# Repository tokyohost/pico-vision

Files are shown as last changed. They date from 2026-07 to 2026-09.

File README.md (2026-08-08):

# Pico RP2040 系统监控屏

项目包含电脑端数据采集程序和 Pico RP2040 显示程序，实现两个独立功能：

1. 按开发板型号非阻塞控制 WS2812 多色灯或 GPIO 单色状态灯。
2. 通过 USB CDC 或 Wi-Fi WebSocket 增量接收 JSON，并将 ST7789 LCD 按条带异步刷新。

## 设计约束

- 不使用 RP2040 第二核心，规避 MicroPython 线程、USB 和 SPI 之间的互锁风险。
- 内置 USB CDC 仅用于 REPL；PV1 通信使用独立 USB CDC 及非阻塞批量 FIFO。
- LCD 不申请 240×320 的整帧缓冲，仅使用 240×48×2，即 23,040 字节条带缓冲。
- LED、串口接收和 LCD 刷新均由单核协作式主循环调度。
- JSON 最大长度为 16 KiB，超限数据包会被拒绝。

## Pico 端文件

将 `picoRP2040/` 的完整目录结构复制到 Pico 根目录：

- `main.py`：应用入口和协作式主循环。
- `led/`：不同板载状态灯的非阻塞控制策略与控制器工厂。
- `protocol.py`：PV1 握手及 JSON 增量接收状态机。
- `net/`：USB CDC、Wi-Fi、WebSocket 传输策略及首连接锁定选择器。
- `usb_transport.py`：创建与 REPL 隔离的 USB CDC 数据通道。
- `usb/device/`：上游 MicroPython `usb-device` 和 `usb-device-cdc` MIT 实现。
- `upgrade_manager.py`：串口升级会话、临时写入、SHA-256 校验、安装和自动重启。
- `data_receiver.py`：最新 JSON 快照缓存。
- `lcd.py`：ST7789 初始化和区域写屏。
- `canvas.py`：带条带裁剪的 RGB565 绘图。
- `dashboard.py`：仪表盘布局和分段刷新。
- `config.py`：开发板、屏幕方案、周期和协议配置。
- `color_manager.py`：按屏幕型号管理反色模式和 RGB/BGR 颜色顺序。
- `board_manager.py`：注册开发板硬件档案并隔离不同板载 LED 类型。
- `fonts/`：SDK 内置文泉驿点阵正黑和 Fusion Pixel 双语字模的授权说明。

Pico 握手会向 Monitor 返回当前开发板型号、屏幕色彩方案、运行固件版本和 `net` 状态；ESP32-S3 还会返回由 eFuse MAC 经 SHA-256 派生的稳定 `device_id`，设备管理页面以 UUID 形式展示且不暴露原始 MAC。USB 模式返回 `mode=usb`，Wi-Fi 模式还返回 SSID、IP、网关、RSSI、WebSocket 端口与路径。源码
直接部署时版本为 `development`，发布全量固件包会自动写入对应的发布版本。

开发板型号和 Wi-Fi 开关由 `picoRP2040/config.py` 配置。例如 ESP32-S3 开启 Wi-Fi：

```python
BOARD_MODEL = "ESP32-S3"
WIFI_ENABLED = True
```

ESP32-S3 与 RP2040 都遵循样式声明的默认字体，例如现有紧凑样式使用
`font_name = "screen_2inch_compact"`。需要显示中文时，可通过 `canvas.text()` 的
`font_name` 参数为单次文字绘制选择字体；调用结束后会恢复样式默认字体。

项目配套的 RP2040 与 ESP32-S3 固件还可选择 `wqy_8x16` 或
`fusion_pixel_8x16`。两者均为英文半角 8×16、中文全角 16×16，直接由 `fn_canvas`
从固件只读区绘制。`canvas.text()` 和 `canvas.text_width()` 都接受 `font_name`；不传入
时保持当前样式字体，样式未指定时仍默认 `native`。

仅使用 USB CDC 时把 `WIFI_ENABLED` 设为 `False`，固件不会初始化无线网卡或 WebSocket 服务。支持的板型包括：

- `rp2040_usb`：GP22 上的 WS2812 多色状态灯。
- `rp2040_typec`：GP25 控制的单色状态灯。
- `ESP32-S3`：默认使用 GPIO48 上的板载 WS2812；具体开发板引脚不同时可修改 `board_manager.py` 中的档案。

新增型号时，可创建 `BoardProfile` 并通过 `register_board_profile()` 注册；业务层
无需感知 LED 的具体实现。

USB 能力同样按照 `BOARD_MODEL` 自动选择，不需要额外 USB 开关：

- `rp2040_usb`、`rp2040_typec` 使用 `machine.USBDevice` 注册保留 REPL 的独立数据 CDC。
- `ESP32-S3` 使用固件内置 USB CDC 或 USB 串行控制台，通过 `sys.stdin` 与
  `sys.stdout` 承载 PV1，不导入也不调用 ESP32 不支持的 `machine.USBDevice`。

ESP32-S3 内置控制台在收到 Monitor 首个字节后锁定 USB 会话；长期无通信后释放，
使启用 Wi-Fi 时 WebSocket 仍可参与传输竞选。

RP2040 端需要 MicroPython 1.23 或更新版本。启动后 USB 会重新枚举为
两个串口：一个保留给 REPL，另一个由 Monitor 通过 PV1 PING 自动识别。
首次部署后原串口短暂断开属于正常现象。Debian 下建议将
`PICO_MONITOR_PORT` 留空，不要固定 `/dev/ttyACM0`。

屏幕硬件由 `picoRP2040/config.py` 中的 `LCD_DEVICE_TYPE` 选择。编码由
芯片、尺寸、排针数量和批次组成，最终由 `lcd` 目录中对应的 `LcdDevice` 子类完整
定义脚位、分辨率、色彩、偏移和写屏细节。工厂会自动扫描该目录中公开
`LCD_DEVICE_CLASS` 的模块，无需维护集中式型号表：

- `st7789-2inch-8pin-a`：ST7789VW 二英寸八针 SPI A 款屏幕。
- `st7789-2.4inch-10pin-a`：ST7789 二点四英寸十针 SPI A 款屏幕。
- `st7789-2.4inch-8pin-b`：ST7789 二点四英寸八针 SPI B 款屏幕。

两种八针屏会按照 `BOARD_MODEL` 自动选择 GPIO。RP2040 保持原有
`SCK=GP6、MOSI=GP7、CS=GP8、DC=GP14、RST=GP15、BL=GP26`；ESP32-S3 使用
`SPI(2)、SCK=GPIO12、MOSI=GPIO11、CS=GPIO10、DC=GPIO9、RST=GPIO14、BL=GPIO13`。
ESP32-S3 默认以 10 MHz 驱动屏幕，并将不接屏幕的 MISO 显式分配到 GPIO15，避免
旧版 MicroPython 自动使用 GPIO13 而与背光 PWM 冲突。
完整接线见 `doc/ST7789_WIRING_README.md`。十针屏目前仅支持 RP2040，ESP32-S3
选择该方案时会返回明确错误，防止误用 RP2040 脚位。

屏幕色彩方案由所选屏幕档案确定，并在握手时提供给 Monitor：

- `st7789vw_2inch`：旧款 ST7789VW 二英寸屏，开启反色并使用 RGB 顺序。
- `st7789_2_4inch`：二点四英寸八针屏，关闭反色并使用 RGB 顺序。
- `st7789_2_4inch_10pin_a`：二点四英寸十针 A 款屏，开启反色并使用 RGB 顺序。
- `st7789_2_4inch_bgr`：新款屏的 BGR 变体；仅在红色与蓝色互换时使用。

旧配置名 `st7789_2inch` 仍可使用，并会自动映射到 `st7789vw_2inch`。

GitHub Actions 会按照全部开发板型号与规范 LCD 设备类型的笛卡尔积生成全量固件包，
文件名格式为 `OmniWatch-pico-full-v<版本>-<开发板型号>-<LCD设备类型>.zip`。包内直接保存
完整部署目录，不再包含 upgrade 清单。Windows Monitor 解压后通过 mpremote 比较设备端文件的
大小和 SHA-256，只复制缺失或内容不一致的文件。无型号后缀的兼容包固定对应
`rp2040_usb` 与 `st7789-2inch-8pin-a`，其他硬件不可混用该兼容包。

## 通信协议

PV1 帧可承载在 USB CDC 字节流或 WebSocket 二进制消息中。USB 和 WebSocket 同时可用时，设备始终优先锁定 USB。WebSocket 默认监听 `ws://设备IP:8765/pv1`，Monitor 握手会携带稳定客户端标识和本机设备名称；ESP32-S3 在 `websocket_clients.json` 中记录成功连接次数、最近地址、启用状态和优先级。设备管理页面可打开“WebSocket 客户端”查看、禁用或设置 `-1000` 至 `1000` 的优先级；仅严格更高优先级的新客户端能够抢占当前 WebSocket，会话切换时会清空旧缓冲，始终只允许一个客户端同步 JSON。

启用 JSON 发送间隔自适应后，Monitor 在每次建立发送会话时从 `400ms` 快速档开始协商；单次启动慢 ACK 不会立即降速，连续慢 ACK 才上调周期，ACK 超时则按两倍周期指数退避，恢复后立即采用更快周期。发送过程继续保持一条在途 JSON 的背压约束。最低采集与发送间隔为 `300ms`；固定间隔模式也不接受更低配置。

设备提供三个配网命令：`wifi.list` 每次返回按信号强度排序的附近全部网络，并在失败中的自动重连与扫描冲突时恢复无线状态后重试；`wifi.set` 的 `params` 接受 `ssid`、`password` 和可选 `timeout_ms`；`wifi.forget` 的 `params` 接受已保存的 `ssid`，用于删除设备凭据。命令均通过 `COMMAND` 帧返回成功详情或失败原因。Wi-Fi 凭据仅保存在设备端 `wifi_config.json`，PONG 和日志不会返回密码。

数据包采用纯 ASCII 行协议，避免 MicroPython 将二进制 `0x03` 解释为 Ctrl+C：

```text
JSON: + 单行 UTF-8 JSON + 换行符
```

设备发现命令为 `PING:PICO_LCD?\n`，有效 JSON 接收完成后返回 `ACK:JSON\n`。

## 启动方式

```powershell
python -m pip install -r requirements.txt
python send_frame.py
```

固定串口时可增加 `--port COM3` 参数。

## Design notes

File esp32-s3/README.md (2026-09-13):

# ESP32-S3 设备端代码

本目录是从 `picoRP2040` 独立出来的 ESP32-S3 专用实现，不包含 RP2040 硬件档案、Pico USB Device 驱动或跨开发板选择逻辑。

## 固定硬件配置

- 开发板：ESP32-S3
- 状态灯：GPIO48 板载 WS2812，单灯珠
- LCD 总线：SPI2，SCK GPIO12，MOSI GPIO11，保留 MISO GPIO15
- LCD 控制：CS GPIO10，DC/RS GPIO9，RST/RESET GPIO14，背光 PWM GPIO13
- 默认 LCD：ST7789 2.4 英寸十针 SPI A 款，排针顺序为 GND、RS、CS、SCL、SDA、RESET、VDD、GND、LED+、LED-
- 十针信号：RS 接 GPIO9，CS 接 GPIO10，SCL 接 GPIO12，SDA 接 GPIO11，RESET 接 GPIO14
- 十针背光：LED+ 接受限电源，LED- 通过外部低端 MOSFET 调光，GPIO13 只驱动 MOSFET 栅极
- 按键：GPIO1、GPIO2、GPIO3，低电平有效并启用内部上拉

### 主题按键监听

当前主题可以实现可选的 `on_button_event(button, event_type, snapshot)` 方法监听三枚物理按键。`button` 分别为 `style_previous`、`style_next`、`function`，`event_type` 分别为 `press`、`long_press`、`repeat`、`release`。返回 `True` 表示主题消费该事件，驱动会使用当前快照立即刷新主题；返回 `False` 或不实现该方法时，继续执行设备原有的样式切换、亮度、旋转等默认命令。监听器异常只会上报 `BUTTON:STYLE_EVENT_ERROR`，不会中断设备主循环。
- 通信：ESP32-S3 内置 USB 控制台和可选 Wi-Fi WebSocket
- WebSocket：客户端握手携带设备名称和稳定标识；设备持久化连接记录，并支持禁用、优先级抢占和单活动连接 JSON 同步

## 10pin LCD 接线图

ST7789 2.4 英寸十针 SPI A 款屏幕按以下排针顺序连接 ESP32-S3：

```text
ST7789 10pin LCD                  ESP32-S3
------------------------------------------------
1  GND        ------------------  GND
2  RS / DC    ------------------  GPIO9
3  CS         ------------------  GPIO10
4  SCL / SCK  ------------------  GPIO12
5  SDA / MOSI ------------------  GPIO11
6  RESET      ------------------  GPIO14
7  VDD        ------------------  3V3
8  GND        ------------------  GND
9  LED+       ------------------  受限流的背光电源正极
10 LED-       ------------------  MOSFET 背光模块 LED- 端子
```

背光使用 GPIO13 驱动外部低端 MOSFET，GPIO 不直接承载 LED 背光电流：

```text
MOSFET 背光模块端子              连接位置
------------------------------------------------
PWM / SIG / IN  --------------  ESP32-S3 GPIO13
GND             --------------  ESP32-S3 GND
LED-            --------------  LCD 第 10 脚 LED-
GND             --------------  背光电源 GND，与 ESP32-S3 GND 共地
```

如果使用裸 MOSFET 而不是成品背光模块，则按以下方式连接：

```text
GPIO13 ----[100R~220R]---- MOSFET G
GPIO13 ----[10K下拉]------ GND

MOSFET S ----------------- GND
MOSFET D ----------------- LCD LED-
LCD LED+ ----------------- 受限流的背光电源正极
ESP32-S3 GND ------------- 背光电源 GND 共地
```

LED+ 必须接带限流的背光电源正极，不要让 GPIO 或无保护电源直接承担背光电流。

## 固件要求

推荐使用仓库 `esp32/driver` 中带原生 PV1、Canvas 和 LCD DMA 加速模块的 ESP32-S3 MicroPython 固件。标准固件缺少原生模块时，协议、画布和 LCD 像素传输会自动使用兼容后端，但必须提供 `network`、`neopixel`、`machine.SPI`、`machine.PWM` 和内置 USB 控制台能力。

部署时将本目录中的 Python 文件及子目录复制到 ESP32-S3 文件系统根目录，并以 `main.py` 作为启动入口。

可见帧整秒同步由每个 Style 的 `sync_visible_frame_to_second` 布尔属性独立决定。
切换 Style 时，渲染器只把该属性下发给 MicroPython SDK；未声明的旧自定义 Style
默认关闭。开启后，每次渲染只把完整画布复制到 C 层的最新帧邮箱并立即返回；
新画布会覆盖尚未显示的旧画布。原生 FreeRTOS 任务在墙钟整秒前取出最新帧，
重新按已显示帧哈希计算脏区，设置 LCD 窗口并在整秒边界启动第一笔像素 DMA。
Python 不计算目标时间，也不等待边界。FPS、
游戏和测试 Style 默认关闭，普通监控及待机时钟 Style 默认开启。缺少 `fn_lcd`
API 4 的兼容 SPI 固件不支持底层异步整秒同步。
设备端会同步推进所有 `history` 和 `*_history` 固定时间格：某秒没有收到新快照
时复制最近一个值，同一秒内真实数据到达后直接覆盖该保持值，使折线持续滚动且
不改写此前的真实历史数据。

## 独立 USB CDC

固件按 TinyUSB 官方双 CDC 方案在启动时直接枚举两个原生接口：CDC 0 保留给 REPL，CDC 1 专供 PV1 数据。数据接口由独立 `fn_cdc_rx` FreeRTOS 任务持续推进 TinyUSB，C 回调立即读空 FIFO 并写入 32 KB 环形缓冲，再按 PV1 头部与 64 字节物理边界组装到四帧有界队列。全程不再使用 `machine.USBDevice` 的 Python 端点回调。长期缓冲优先从 PSRAM 动态分配；队列和环形缓冲都满时依靠 USB NAK 背压，不覆盖未处理数据。该功能必须连接 ESP32-S3 原生 USB OTG 接口，CH343 等 USB-UART 接口仍属于兼容控制台通道。

- 原生数据 CDC 通过 `_usb_cdc_data → NativeCdcStream → UsbCdcTransport → TransportManager` 接入现有协议。
- USB 枚举、端点重挂、FIFO、半帧超时和完整帧队列全部由固件 C 层处理，Python 只取完整帧并调用 `fn_protocol` C 解析器，LCD 渲染停顿不会中断逐包端点服务。
- 固件没有编译 `_usb_cdc_data` 时才回退到原有内置控制台或 CH343 通道，不再创建存在长期稳定性问题的运行时 Python CDC。
- 如需固定使用 CH343/控制台传输，应把 `USB_DEDICATED_CDC_ENABLED` 设为 `False`。
- 可通过 `config.py` 的 `USB_DEDICATED_CDC_ENABLED` 控制数据通道；C 缓冲容量由板级固件宏 `MICROPY_HW_USB_CDC_DATA_RX_BUFSIZE` 决定。
- PONG 会报告当前 MicroPython SDK 版本及 `sdk_update` 能力。仅原生 USB 传输可以执行 `sdk.bootloader`；设备先返回并刷新结构化成功应答，再通过 MicroPython 调度器延迟调用 `machine.bootloader()`，确保命令处理栈退出后进入 ESP32-S3 ROM USB 下载模式，供 Windows Monitor 无按键刷写完整合并 bin。

## 第二阶段渲染服务

ESP32-S3 专用入口已经使用 `render_service.py` 隔离通信主循环与渲染状态：

- 通信主线程只解析 USB/WIFI 数据并发布最新快照。
- Python 渲染工作线程独占 `DashboardRenderer`、Canvas、LCD 和 SPI。
- 两个固定快照槽支持 `latest` 最新帧覆盖和 `block` 阻塞等待两种背压策略。
- 样式切换、旋转、背光和截图通过八项固定控制队列在渲染线程执行。
- 线程模块不可用或线程创建失败时，自动回退到相同接口的同步渲染服务。
- 启动日志通过 `BOOT:RENDER_SERVICE:THREAD` 或 `SYNC_FALLBACK` 标明实际模式。

该阶段可以在 SPI DMA 等待释放 GIL 时让通信主线程继续运行，但所有 MicroPython 线程仍受 GIL 和 CPU1 亲和性限制。真正把绘制计算固定到 CPU0 需要继续实施原生 C 渲染任务。

## LCD 像素传输后端

`LCD_TRANSFER_BACKEND` 可在 `legacy`、`native_dma` 和 `auto` 之间切换。默认
`auto` 在固件包含 `fn_lcd` API 4 时，让 MicroPython 始终在完整 RAM 画布绘制；
C 固件自动检测并记录脏区，以两块内部 SRAM 条带缓冲交替提取像素，再通过两块
内部 DMA RAM 发送。旧固件会安全回退标准 `machine.SPI.write()`。该优化不改变
Python Style 和 Canvas API；完整原理、
配置方法与对照测试见
[ESP32-S3 MicroPython LCD DMA 渲染原理](../doc/esp32-fix/ESP32-S3_MicroPython_LCD_DMA渲染原理.md)。

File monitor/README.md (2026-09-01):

# Pico LCD 系统硬件监控程序

本目录提供独立电脑端监控程序，使用 PV1 协议经独立 USB CDC 或 Wi-Fi WebSocket 双工传输系统快照。内置 USB CDC 仅保留给 MicroPython REPL，不承载监控数据。设备会锁定首个建立的传输模式，只有该连接断开后才重新选择；Monitor 在两种模式下均支持断线重连和 WebSocket 心跳。

Windows 可选用 PresentMon/ETW 采集前台程序 FPS，JSON 顶层 `fps` 包含 `value`、24 点 `history`、`source`、`process_id` 和 `process_name`。PresentMon 不可用时保持字段结构并返回空值；AMD ADLX 可作为可选回退。部署说明见 [win/fps/README.md](win/fps/README.md)。

本程序不安装自定义内核驱动：Windows 使用系统性能接口和串口驱动，Linux 使用 `/proc`、`/sys` 及系统串口驱动。这样无需驱动签名，也不会绑定特定内核版本。

CPU 数据通过顶层 `cpu` 对象发送，其中 `frequency_ghz` 是当前 GHz 频率。GPU 数据通过顶层 `gpu` 对象发送，除使用率和历史外，还包含专用显存 `dedicated_memory_used_bytes`/`dedicated_memory_total_bytes` 与温度 `temperature_c`；操作系统或驱动不提供对应指标时字段值为 `null`。Linux 支持 NVIDIA NVML、AMD sysfs 和 Intel i915 PMU；Intel 核显使用共享内存，因此专用显存字段通常为 `null`。DEB 服务默认以 root 身份运行，可直接读取 i915 系统级 PMU；手动以普通用户运行时，需要系统允许该用户访问对应 perf 事件。

磁盘明细通过 JSON 顶层 `disks` 数组发送。同一物理盘的多个分区会合并，字段包括 `name`、`devices`、`mountpoints`、`filesystems`、`used_bytes`、`total_bytes`、`percent`、`temperature_c` 和 `health`。同时，面向 Pico 显示的物理磁盘统计通过顶层 `physical_disks` 数组发送，每块物理盘也包含 `health`、温度、容量、占用率、实时读写速度 `read_bps`/`write_bps`，以及固定长度的读写速度历史 `read_history`/`write_history`。程序在启动时检查 SMART，之后每 30 分钟复查；Linux 需要安装 `smartmontools`。`health` 取值为：`0` 未知、`1` 健康、`2` 注意、`3` 警告、`4` 严重、`5` 失败。分级以 smartmontools 总体自检结论为最高优先级，并结合 NVMe Critical Warning、寿命百分比和 ATA 重映射、待映射及不可校正扇区等公开指标；无法读取 SMART、USB 硬盘盒不支持或权限不足时返回 `0`。

网络统计通过 `network.receive_bytes` 提供已下载总流量，通过 `network.transmit_bytes` 提供已上传总流量，单位均为字节。

所有 `history`、`*_history` 字段均以一秒为固定时间格，表示最近 24 秒，不受 `PICO_MONITOR_INTERVAL` 或 qBittorrent 采集间隔影响。同一秒内的多次采集保留峰值，避免折线尖峰被后续低值擦除；跨过多秒时，缺失秒使用上一秒数值补齐。

系统采集任务频率使用秒为单位并支持小数，例如在 Windows 设置界面填写
`0.8`，或使用 `--collection-task-intervals '{"cpu_memory": 0.8}'`，表示每
0.8 秒调度一次对应任务。旧版整数配置保持兼容。

开启并配置 qBittorrent Web UI 后，程序会在后台通过 Web API 采集 `qbittorrent` 顶层指标，不会阻塞系统指标发送。字段包括实时上传下载速度及历史、会话与历史流量、历史分享率、会话丢弃、连接用户、下载目录剩余空间和种子状态数量。完整配置与字段说明见 [qbittorrent_config.md](qbittorrent_config.md)。

## 主要功能

- 自动发现并握手识别 Pico LCD，也可固定串口。
- 支持通过 `ws://设备IP:8765/pv1` 连接 ESP32-S3，并在 PONG 中读取当前传输模式和 Wi-Fi 详情。
- 连接后读取并记录 Pico 开发板型号、屏幕色彩方案、当前固件版本和底层 SDK 版本。
- Windows 设备管理支持校验 ESP32-S3 完整合并 bin，并经 USB CDC 受控进入 ROM 下载模式完成 SDK 刷写。
- 下载当前 Monitor 版本对应的 Pico 全量固件包，通过 mpremote 按 SHA-256 增量更新固件。
- 磁盘汇总统计所有有效本地分区，并发送每个磁盘的设备、挂载点、容量、占用率和可用温度。
- Linux 支持通过 RAPL 能耗计数器发送实时功耗；不支持的平台明确发送空值。
- 设备拔插、休眠唤醒或通信失败后自动重连。
- 完整记录握手、JSON 原文、数据块数量、Pico 响应、异常和超时。
- Windows 单文件 EXE、托盘运行、日志查看和当前用户自启动。
- 自定义数据支持目录或 ZIP 插件包、插件独立虚拟环境、第三方依赖安装和超时子进程隔离。
- Debian/Ubuntu DEB、systemd 守护、异常自动重启和开机启动。
- 全部源码采用无 BOM UTF-8，类和方法包含规范中文注释。

## 源码运行

```powershell
python -m pip install -r requirements.txt
python pico_monitor.py
```

常用参数：

```text
--port COM3                 固定 Windows 串口
--port /dev/ttyACM1         固定 Linux 数据 CDC；建议留空自动发现
--websocket-url ws://192.168.1.20:8765/pv1
                            使用 Wi-Fi WebSocket；断线后按 reconnect-interval 自动重连
--wifi-discovery-strategy announcement|scan
                            默认监听 ESP32 UDP 公告并以网段扫描兜底；scan 直接扫描网段
--wifi-announcement-port 37856
                            ESP32 主动公告监听端口
--ping-target 1.1.1.1       指定延迟探测目标，默认 www.baidu.com
--serial-probe-interval 3   串口探测 PING 间隔，默认 3 秒
--interval 1.0              指定采集发送间隔
--reconnect-interval 3.0    指定断线重连间隔
--screen-rotation 180       将 Pico 屏幕旋转一百八十度
--lcd-brightness 80         将 LCD 背光亮度设置为 80%，范围为 1 至 100
--network-unit MB           按 B/s、KB/s、MB/s、GB/s 自动选择单位
--network-unit Mbps         按 bps、Kbps、Mbps、Gbps 自动选择单位
--lcd-style default|disk|horizontal_disk|horizontal_disk4x|horizontal_disk4x_qb|horizontal_disk6x
                            切换 Pico 固件内置 LCD 样式；horizontal_disk4x_qb 保留双列四磁盘布局，并将 IP/GPU 区域替换为 qBittorrent 仪表盘
--qbittorrent-enabled       开启 qBittorrent 指标采集
--no-qbittorrent            显式关闭 qBittorrent 指标采集
--qbittorrent-address http://127.0.0.1:8080
                            qBittorrent Web UI 地址
--qbittorrent-username admin
                            qBittorrent Web UI 登录账号
--qbittorrent-password password
                            qBittorrent Web UI 登录密码
--qbittorrent-interval 2.0 qBittorrent 指标采集间隔，单位为秒
--disk-health-test-index 1  指定从 1 开始的磁盘序号并启用 health 显示测试，0 表示关闭
--disk-health-test-level 3  指定测试 health 等级 0 至 5，默认 3
--dev                       开发模式；未发现 Pico 后停止重试并持续打印 JSON
--once                      成功发送一次后退出
--version                   显示 Monitor 构建版本并退出
--pico-info                 显示已连接 Pico 的板型、屏幕方案和固件版本
--upgrade-pico              下载当前 Monitor 版本全量固件包并更新 Pico
--upgrade-url URL           开发版或私有发布使用的全量固件包地址
--upgrade-sha256 HASH       可选的全量固件包下载摘要校验值
```

开发模式也可通过环境变量 `PICO_MONITOR_DEV=1` 开启。LCD 背光亮度可通过 `PICO_MONITOR_LCD_BRIGHTNESS=1..100` 配置。首次串口扫描未找到 Pico 后，程序不再重试 COM 口，而是按照 `--interval` 周期持续采集，并以 `[DEV][Monitor -> Pico][JSON]` 标识打印完整 `JSON:` 协议行，方便在没有硬件时调试采集数据。

qBittorrent 也可通过环境变量 `PICO_MONITOR_QBITTORRENT_ENABLED`、`PICO_MONITOR_QBITTORRENT_ADDRESS`、`PICO_MONITOR_QBITTORRENT_USERNAME`、`PICO_MONITOR_QBITTORRENT_PASSWORD` 和 `PICO_MONITOR_QBITTORRENT_INTERVAL` 配置。启用采集后地址、账号、密码必须全部配置。建议使用环境变量或 Linux 配置文件保存密码，避免密码出现在进程命令行中。

WebSocket 地址也可通过 `PICO_MONITOR_WEBSOCKET_URL` 配置。首次配网时先使用 USB CDC 连接，通过 `PicoJsonClient.request_wifi_list()` 发送 `wifi.list` 搜索网络，再通过 `PicoJsonClient.set_wifi(ssid, password)` 发送 `wifi.set`。Windows Monitor 的 Wi-Fi 页面每次重新扫描附近全部网络，同时保留“已保存”网络供用户选中；点击“忘记网络”会通过 `PicoJsonClient.forget_wifi(ssid)` 发送 `wifi.forget` 并删除设备端凭据。命令使用结构化 `COMMAND` 帧返回扫描结果、连接或忘记成功详情及具体失败原因；配网成功后关闭 USB 数据串口，再以设备返回的 IP 启动 WebSocket 模式。

ESP32-S3 联网后默认每 2 秒向 `239.255.77.77:37856` 发送 UDP 组播公告，并同时发送局域网广播以兼容不转发组播的路由器。公告不包含 Wi-Fi 凭据；Monitor 使用数据报来源 IP 生成候选地址，并继续通过 PV1 握手确认设备身份。

Linux Monitor 在 USB 和 WebSocket 均未连接时默认先监听 ESP32 主动公告，公告窗口内没有可连接设备时再执行同网段快速扫描兜底，之后每次发现起点至少间隔 30 秒；任一传输连接成功后停止发现。将配置文件中的 `network.discovery_strategy` 改为 `scan` 可跳过公告监听并直接使用原网段扫描。周期扫描限制为 16 个并发连接和 `/24` 最大扫描范围，并严格按 TCP 端口开放、标准 WebSocket 升级、PV1 设备握手三阶段确认。

Windows 托盘的“设备管理 → 主动探测”默认先监听 ESP32 UDP 公告，超时后才枚举所有启用网卡的 IPv4 局域网地址并扫描；设置页面可切换为直接扫描本地网段。所有候选服务都会经过 PV1 设备握手确认；确认成功后，连接地址保存到当前用户的 `settings.json`，以后启动时优先直连。连接成功、首次连接失败和已连接后断开都会产生托盘通知，相同失败状态不会重复通知。

### Windows 受控 USB SDK 刷写

设备管理会同时显示 Python 文件固件版本和 MicroPython SDK 版本。仅当设备通过 ESP32-S3 原生 USB CDC 连接，并在 PONG 中声明支持 SDK 刷写时，“刷写 USB SDK”按钮才会启用；Wi-Fi WebSocket、RP2040、CH343 等兼容控制台通道均不会进入该流程。

选择 `.bin` 后，Monitor 会在停止设备传输前校验 ESP32-S3 芯片编号、`0x8000` 分区表、`0x10000` factory 应用、镜像大小和 SHA-256，并显示目标 SDK 版本供再次确认。确认后设备先返回并刷新带 request_id 的成功应答，再通过调度器延迟调用 `machine.bootloader()` 退出应用 USB；Monitor 只接受同一物理位置或新枚举的 Espressif `VID 303A` ROM 串口，并仅在真实重枚举后报告已经进入 ROM 下载模式，随后由隔离子进程调用 esptool 将完整合并镜像写入 `0x0`。刷写完成会重启监控进程，并在设备重新连接后核对 PONG 中的 SDK 版本。

刷写期间不要断电、拔线或让电脑休眠。旧设备固件如果尚未实现 `sdk.bootloader`，设备页会保持按钮禁用；这类设备需要先用传统方式升级一次支持该命令的固件，后续 SDK 更新才可不按 Boot 键完成。

当设备管理没有已连接设备，或设备已人工进入 ROM 下载模式时，可使用“强刷 SDK”。该入口仍会先校验 `.bin` 镜像，但由用户手动选择目标 COM 口，并让 esptool 通过默认复位策略尝试进入下载模式；使用前必须确认所选 COM 口属于目标 ESP32-S3 设备。

## 构建 Windows 安装包

在 Windows 命令提示符执行：

```bat
build-exe.bat
```

安装包和生成的 Windows EXE 清单均要求管理员权限，启动时系统会显示 UAC 提权确认窗口；用户拒绝提权时程序不会运行。

最终发布文件为 `dist\OmniWatch-windows-x64-setup-v<版本>.exe`，`dist\pico-monitor.exe` 仅作为安装包构建的中间产物。安装完成后从开始菜单或桌面快捷方式启动，程序会驻留系统托盘，运行日志位于 `%LOCALAPPDATA%\PicoMonitor\pico-monitor.log`。右键托盘图标选择“日志导出”，可导出最近 1 MB 日志并打开导出文件目录；勾选“Dev 模式”会保存配置并重启后台监控，使开发模式立即生效。选择“检查更新”可在弹窗中确认或修改更新地址，程序会先更新 Pico 固件，再运行 Monitor 安装包并自动重启。

构建脚本会从 Python 官方 NuGet 源下载固定版本的便携 Runtime，生成 `dist\plugin-runtime` 并一同写入安装包。这个 Runtime 只负责为自定义数据插件创建独立虚拟环境，不参与 Monitor 主程序执行。构建机需要能够访问 `www.nuget.org`。

自定义数据只接受包含 `plugin.json` 的标准插件目录或 ZIP 插件包，不再扫描、导入或校验旧版单文件 `.py`。首次创建用户数据目录时会生成 `custom_data_plugin_template` 目录模板，该目录仅供复制开发，不会作为已安装插件运行。

每个插件会在 Monitor 设置页生成独立配置面板。`interval` 是保留字段，无需写入
`config_panel`；即使不声明 `config_panel`，面板也会至少显示采集间隔。支持的字段
类型为 `string`、`number`、`boolean`、`select`、`password` 和 `textarea`。字段可声明
`default`、`required`、`min`、`max`、`decimal`、`reg`；`select` 还必须声明非空
`options`。所有面板值（包括 `interval`）会组成 JSON 字符串传给 `collect(config_json)`，
插件通过 `json.loads(config_json)` 自行解析。为兼容已有插件，无参数 `collect()` 仍可运行。

插件启用状态由 Monitor 单独持久化，不属于面板业务配置。协议 2 可声明配置动作按钮，
通过白名单方法返回受校验的配置补丁；也可声明删除前执行的 `uninstall(context)` 清理
钩子。完整清单格式、安全边界和迁移规则见
[`docs/custom_data_plugin_protocol_v2.md`](docs/custom_data_plugin_protocol_v2.md)。

插件还可声明 `"bind_style": true` 和插件根目录内的 Python 文件名 `"style"`。导入后
自定义数据插件表会显示该绑定样式，并允许通过“同步样式”校验后上传到当前设备。
声明 `"bind_detail": true` 与 `"detail": "demo_detail.html"` 可绑定不超过 1 MB 的
UTF-8 HTML 简介；声明 `"bind_preview": true` 与 `"preview": "preview.png"` 可绑定
不超过 5 MB 的 PNG、JPEG、GIF 或 WebP 预览图。预览图会显示在插件表中，简介则在
禁用脚本和主界面访问权限的受限页面中打开。所有绑定资源都必须直接位于插件根目录。
`key`、`name`、配置字段 `key` 只能包含字母、数字和下划线且不能以数字开头；
`interval` 不能作为自定义字段重复声明。

日志使用 `[Monitor -> Pico]` 和 `[Pico -> Monitor]` 标识通信方向。Linux 服务可通过 `journalctl -u pico-monitor -f` 实时查看相同内容。

## 构建 Linux DEB

群晖、QNAP 与 TrueNAS 的发布包选择、支持版本和安装限制见
[`NAS_INSTALL.md`](NAS_INSTALL.md)。

Linux 发布明确构建以下四种架构：

- `amd64`：主流 Intel/AMD 64 位电脑，优先支持 Debian、Ubuntu。
- `arm64`：64 位 ARM 设备，包括 Ubuntu Server ARM64 和 Debian ARM64。
- `armhf`：32 位 ARM 硬浮点设备，包括部分 Raspberry Pi OS。
- `i386`：32 位 Intel/AMD 电脑。

DEB 原生支持 Debian、Ubuntu 及使用兼容 APT 依赖仓库的衍生发行版。Fedora、RHEL、openSUSE、Arch Linux 等非 Debian 系统请使用 Release 中的通用 `OmniWatch-<版本>-linux.tar.gz`，解压后运行 `sudo ./install-linux.sh`。

在 Debian 或 Ubuntu 中执行：

```bash
sudo apt update
sudo apt install build-essential debhelper devscripts
chmod 0755 debian/rules bin/pico-monitor
dpkg-buildpackage --no-sign -b
sudo apt install ../OmniWatch_1.0.0_$(dpkg --print-architecture).deb
```

安装后可使用以下命令：

```bash
sudo systemctl status pico-monitor
sudo journalctl -u pico-monitor -f
sudo systemctl restart pico-monitor
```

运行配置位于 `/etc/pico-monitor.conf`。服务默认以 `root` 运行，从而读取硬件传感器并访问 USB 串口；如果发行版已配置 `dialout` 权限，可按安全要求调整服务用户。

### 自动更新 Linux DEB

通过 DEB 安装后，可停止后台服务并从 GitHub 最新 Release 自动下载、校验和安装当前架构的软件包：

```bash
sudo systemctl stop pico-monitor
sudo pico-monitor --update
sudo systemctl start pico-monitor
pico-monitor --version
```

`--update` 会调用 GitHub Release API，按 `dpkg --print-architecture` 自动选择 `amd64`、`arm64`、`armhf` 或 `i386` 软件包，并优先使用 Release 中的 `OmniWatch-SHA256SUMS-linux-deb.txt` 校验下载内容，最后通过 `apt-get install` 完成更新。该命令仅支持 Linux 发布构建，必须使用 root 权限运行；本地 `development` 版本不会执行自动更新。

## Pico 固件要求

先将 `picoRP2040` 完整目录部署到运行 MicroPython 1.23 或更新版本的 Pico。启动后会枚举两个 CDC 串口：内置接口用于 REPL，新增接口用于 PV1。Monitor 会通过 PING/PONG 自动找到数据接口，Debian 配置中应将 `PICO_MONITOR_PORT` 留空。

## Pico 在线升级

查看当前连接 Pico 的硬件配置与固件版本：

```bash
pico-monitor --pico-info
```

该命令会自动发现 Pico，也可同时通过 `--port` 指定串口；信息打印完成后程序立即退出。

发布版 Monitor 使用同版本 GitHub Release 中的 `OmniWatch-pico-full-v<版本>.zip`。该无后缀兼容包仅适用于 `rp2040_usb` 与 `st7789vw_2inch`。其他硬件使用 `OmniWatch-pico-full-v<版本>-<开发板型号>-<屏幕方案>.zip`。Windows 桌面控制中心的设备管理页可分别选择固件 ZIP 和目标串口。默认通过 mpremote 分批读取设备文件大小和 SHA-256，一致文件直接跳过，只上传缺失或摘要不一致的文件；勾选“全量更新”后不读取或计算文件哈希，直接复制并替换包内全部文件。两种模式都会在处理完成后统一复位设备。

### Linux DEB 安装后升级 Pico

通过 DEB 安装的 `pico-monitor` 默认由 systemd 持续运行。主动升级前必须先停止服务，释放 Pico 使用的 `/dev/ttyACM*` 串口，再以 root 权限执行一次性升级命令：

```bash
sudo systemctl stop pico-monitor
sudo /usr/bin/pico-monitor --upgrade-pico
sudo systemctl start pico-monitor
sudo journalctl -u pico-monitor -n 100 --no-pager
```

程序会根据已安装 Monitor 的版本号，从同版本 GitHub Release 下载 `OmniWatch-pico-full-v<版本>.zip`。如果必须显式指定端口，应选择能响应 PV1 PONG 的数据 CDC：

```bash
sudo /usr/bin/pico-monitor --port /dev/ttyACM1 --upgrade-pico
```

升级成功时终端会依次显示 `ACK:UPGRADE:BEGIN:<版本>`、文件传输确认、`PROGRESS:UPGRADE:INSTALL:100` 和 `ACK:UPGRADE:COMPLETE:<版本>`。Pico 随后自动重启；重新启动 systemd 服务后，可通过日志确认出现 `PONG:PICO_LCD` 和 `ACK:JSON`。

首次在线升级前，Pico 必须已经部署包含 `upgrade_manager.py` 的固件。如果在 `UPGRADE:BEGIN` 阶段超时，并且 Pico 随后不再响应握手，先按复位键或重新插拔 USB，再确认 Linux 已安装包含固定协议块升级支持的新版本 DEB，然后重新执行上述步骤。安装提交阶段不要断开 USB 或关闭电源。

### 本地主动升级测试

首次测试前，Pico 中必须已经部署包含 `upgrade_manager.py` 的当前固件，否则设备无法识别 `UPGRADE:` 升级命令。

在 `pico-project` 项目根目录生成本地测试全量固件包：

```powershell
New-Item -ItemType Directory -Force release-assets
python tools\package_pico_firmware.py `
  --source picoRP2040 `
  --output release-assets\OmniWatch-pico-full-vlocal-test.zip `
  --version local-test
```

在第一个 PowerShell 窗口启动本地文件服务，并保持窗口运行：

```powershell
python -m http.server 8000 --directory release-assets
```

在第二个 PowerShell 窗口进入 Monitor 目录并主动升级指定串口的 Pico：

```powershell
cd monitor

python pico_monitor.py `
  --port COM9 `
  --upgrade-pico `
  --upgrade-url http://127.0.0.1:8000/OmniWatch-pico-full-vlocal-test.zip
```

请按实际设备修改 `COM9`。如果需要同时校验全量固件包下载摘要，可读取生成的 SHA-256 并传给 Monitor：

```powershell
$hash = (Get-FileHash `
  ..\release-assets\OmniWatch-pico-full-vlocal-test.zip `
  -Algorithm SHA256).Hash.ToLower()

python pico_monitor.py `
  --port COM9 `
  --upgrade-pico `
  --upgrade-url http://127.0.0.1:8000/OmniWatch-pico-full-vlocal-test.zip `
  --upgrade-sha256 $hash
```

发布版 Windows 安装后使用相同参数：

```powershell
.\pico-monitor.exe `
  --port COM9 `
  --upgrade-pico `
  --upgrade-url http://127.0.0.1:8000/OmniWatch-pico-full-vlocal-test.zip
```

升级成功时，日志会依次出现 `ACK:UPGRADE:BEGIN:local-test`、文件传输确认、`PROGRESS:UPGRADE:INSTALL:100` 和 `ACK:UPGRADE:COMPLETE:local-test`，随后 Pico 自动重启。提交安装期间不要断开 USB 或关闭电源。

## GitHub Actions 自动发布

`pico-project/.github/workflows` 提供 Windows 安装包与 Linux DEB 两套工作流。手动运行工作流时只生成 Actions Artifact；推送 `v` 开头的标签时会自动创建或更新 GitHub Release，并上传以下产物：

- `OmniWatch-windows-x86-setup-v<版本>.exe`
- `OmniWatch-windows-x64-setup-v<版本>.exe`
- `OmniWatch_<版本>_amd64.deb`：Intel/AMD 64 位电脑
- `OmniWatch_<版本>_arm64.deb`：ARM 64 位设备
- `OmniWatch_<版本>_armhf.deb`：ARM 32 位硬浮点设备
- `OmniWatch_<版本>_i386.deb`：Intel/AMD 32 位电脑
- `OmniWatch-<版本>-linux.tar.gz`：Fedora、RHEL、openSUSE、Arch 等 systemd 发行版通用安装包
- `OmniWatch-synology-noarch-v<版本>.tar.gz`：群晖 DSM 7.2+ 安装包
- `OmniWatch-qnap-noarch-v<版本>.tar.gz`：QTS 5.1+ 与 QuTS hero h5.1+ 安装包
- `OmniWatch-truenas-noarch-v<版本>.tar.gz`：TrueNAS SCALE 24.10+ 安装包
- `OmniWatch-SHA256SUMS-nas.txt`：NAS 发布包 SHA-256 摘要
- `OmniWatch-pico-full-v<版本>-<开发板型号>-<屏幕方案>.zip` 与 `.sha256`：定向 Pico 全量固件包及下载摘要
- `OmniWatch-pico-full-v<版本>.zip` 与 `.sha256`：默认硬件组合的全量固件兼容包

发布示例：

```bash
git tag v1.0.0
git push origin v1.0.0
```

### 致谢

- Tz. 感谢协助修复intel 平台cpu 温度获取失败问题

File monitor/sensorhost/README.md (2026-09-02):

# OmniWatch SensorHost

OmniWatch SensorHost 是 Windows 上的独立硬件传感器宿主进程。它使用 C# 和 `LibreHardwareMonitorLib` 读取 CPU、GPU、内存、磁盘与功耗传感器，通过 Named Pipe 向 Python monitor 返回 JSON 快照。

SensorHost 通常由 monitor 作为无窗口子进程启动。子进程只检测 PawnIO，不弹出安装界面、不触发安装流程，也不等待外部安装器；驱动安装完成后需要重启 SensorHost。

## 构建

```powershell
dotnet restore
dotnet build -c Release
```

## 发布流水线

GitHub Actions 配置位于 `.github/workflows/release.yml`。

- 推送到 `main` 或 `master`：执行还原、编译、发布和上传构建产物。
- 创建 `v*` 标签，例如 `v1.0.0`：自动创建 GitHub Release，并上传 zip 与 SHA256。
- 手动运行 `workflow_dispatch`：可填写版本号，并选择是否创建 GitHub Release。

发布包名称格式为 `omniwatch-sensor-host-win-x64-<version>.zip`，包内可执行文件名称格式为 `OmniWatch.SensorHost-<version>.exe`，包含 Windows x64 自包含可执行文件、Python Named Pipe 客户端和 README。

## 调试

```powershell
dotnet run --project src\OmniWatch.SensorHost -- --once --pretty
dotnet run --project src\OmniWatch.SensorHost -- --pipe omniwatch.sensorhost
```

## Named Pipe 协议

管道名称默认是 `omniwatch.sensorhost`，Windows 完整路径是 `\\.\pipe\omniwatch.sensorhost`。请求和响应均为 UTF-8 无 BOM、单行 JSON，以换行符结尾。

请求示例：

```json
{"command":"snapshot"}
```

响应示例：

```json
{"ok":true,"data":{"version":1,"cpu":{"percent":12.3},"memory":{"physical":{"percent":79.92,"used_bytes":54835915653,"available_bytes":13776058778},"virtual":{"percent":74.05,"used_bytes":108780784189,"available_bytes":38117834752}}}}
```

内存快照按 LibreHardwareMonitor 硬件节点拆分：`physical` 对应 `Total Memory`，`virtual` 对应 `Virtual Memory`。两组数据不会跨节点求和或相互替代。
`hardware_access` 返回 PawnIO 安装版本、当前子进程权限、设备可访问状态以及 CPU 温度/时钟传感器数量。`status` 常见值包括 `ready`、`pawnio_not_installed`、`process_not_elevated`、`pawnio_device_unavailable` 和 `cpu_temperature_unavailable`，用于区分驱动问题与传感器兼容问题。
支持命令：

- `ping`：返回宿主健康状态。
- `snapshot`：返回一次硬件传感器快照。
- `shutdown`：优雅退出宿主进程。

## Python 进程管理

`python/omniwatch_sensor_host.py` 提供 `SensorHostProcess` 和 `SensorHostClient`。`SensorHostProcess` 使用 `subprocess.Popen` 启动宿主，并通过 pywin32 Job Object 设置 `JOB_OBJECT_LIMIT_KILL_ON_JOB_CLOSE`，确保 monitor 退出时子进程一起退出。

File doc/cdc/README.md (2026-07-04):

# Third-party USB device modules

`usb/device/core.py` and `usb/device/cdc.py` are vendored without functional
changes from the official `micropython/micropython-lib` repository, commit
`68f8fe4e3c9b408642353c01d9c4f2667399a79b` (2026-07-03).

These files retain their upstream MIT license and copyright notices.

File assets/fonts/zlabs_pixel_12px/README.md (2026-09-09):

# Z工坊像素黑体 12px

来源：https://github.com/Astro-2539/ZLabs-Pixel-12px

采用作者发布的 `Build_20260519` 大陆字形版 `ZLabsPixel_12px_M_CN.ttf`。原字体及生成点阵依照同目录 `LICENSE-OFL.txt` 的 OFL-1.1 授权发布，不适用项目代码的商业使用限制。

固件包沿用现有 ASCII + GB2312 字符索引，共 7,540 个字形，不代表原字体的全部 Unicode 覆盖范围。字形高度 12px，ASCII 步进 6px，其他字符步进 12px；索引之外的字符沿用固件问号回退。

在工作区执行 `python pico-project/tools/build_zlabs_pixel_font.py` 重新生成点阵，需要 Pillow。生成文件为 `micropython/ports/rp2/modules/fn_canvas/font_zlabs_pixel_data.c`，点阵占 180,960 字节只读 Flash，不整体加载到 Python 堆。

重新编译启用 `FN_CANVAS_BUILTIN_FONTS` 的 MicroPython 固件（fn_canvas API 10），再部署对应 Pico 或 ESP32-S3 SDK。旧固件需要更新后才能使用新字体。

```python
canvas.text(8, 8, "你好，世界！CPU 88%", WHITE, font_name="zlabs_pixel_12px")
canvas.set_font("zlabs_pixel_12px")
```

字体测试样式名为 `zlabs_pixel_test`，中文名称为“Z工坊12px字体测试”，可通过现有样式选择功能加载。测试页为 240×320 竖屏，包含 1 倍和 2 倍显示、中文、英文数字、标点及紧凑字体对照；刷新区域使用 40px 条带。

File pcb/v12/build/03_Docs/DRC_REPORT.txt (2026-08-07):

Board: 20.00 x 30.00 mm
Copper clearance target: 0.20 mm
Copper-edge target: 0.25 mm
Different-net clearance errors: 0
Connectivity errors: 0
NOTE: independent geometry/connectivity checker, not official KiCad DRC.

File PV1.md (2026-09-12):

# PV1 串口通信协议规范

## 1. 文档状态

本文定义 pico-vision Monitor 与 RP2040 Pico LCD 固件之间使用的 PV1 串口协议。

- 协议名称：PV1
- 协议版本：1
- 传输介质：USB CDC ACM 串口字节流
- 默认串口参数：115200 baud，8N1
- Monitor 实现：`monitor/pico_client.py`、`monitor/pico_upgrade.py`
- Pico 实现：`picoRP2040/protocol.py`、`picoRP2040/upgrade_manager.py`
- 兼容策略：仅支持 PV1，不兼容旧版 `PING:`、`JSON:`、`UPGRADE:` 裸文本协议

本文中的“必须”“不得”“应”“可以”分别对应 MUST、MUST NOT、SHOULD、MAY。

## 2. 设计目标

PV1 的目标如下：

1. 在 Windows 与 Linux USB CDC 上提供一致的消息边界。
2. 支持串口字节流的分段、合并、短写入和部分读取。
3. 在收到其他程序写入的非协议内容后重新同步。
4. 使用长度字段和 CRC 检测截断、拼接及传输损坏。
5. 避免未同步的短数据触发固定长度阻塞读取。
6. 使用批量读取和压缩降低 RP2040 的接收与解析耗时。
7. 限制帧大小、JSON 大小、半包驻留时间和解压内存。
8. 让握手、快照、升级、事件、确认和错误共用同一种帧格式。

PV1 的 CRC 只用于偶然错误检测，不提供身份认证、机密性或抗恶意篡改能力。

## 3. 分层模型

PV1 分为三层：

1. USB CDC 字节流层：不保留应用消息边界。
2. PV1 帧层：提供魔数、类型、长度、CRC、填充和物理块边界。
3. 消息层：定义 `PING`、`PONG`、`JSONZ`、`JSONB`、`ACK`、`ERR`、`EVENT`、`COMMAND` 和 `STATUS`。

## 4. 基本编码规则

- 协议关键字、类型、长度和 CRC 使用 ASCII。
- JSON 使用 UTF-8；Monitor 当前以 `ensure_ascii=True` 生成紧凑 JSON。
- 数字字段不得包含符号、空格或前导说明文字。
- 类型名称区分大小写，规范类型全部使用大写 ASCII。
- 一条物理帧以单个 LF 字节 `0x0A` 结束。
- 接收方可以接受 LF 前的传输填充空格，但不得把填充计入载荷。
- `JSONB` 载荷允许包含任意字节（包括 LF），接收方必须按 `LENGTH` 定界；其他文本类型继续按 LF 兼容定界。

## 5. 帧格式

### 5.1 语法

```text
PV1:<TYPE>:<LENGTH>:<CRC16>:<PAYLOAD><PADDING>\n
```

等价的 ABNF 表示：

```text
frame       = magic ":" type ":" length ":" crc16 ":" payload padding LF
magic       = "PV1"
type        = 1*(ALPHA / DIGIT / "_")
length      = 1*DIGIT
crc16       = 4HEXDIG
payload     = *OCTET
padding     = *SP
LF          = %x0A
```

`payload` 的实际字节数必须恰好等于 `LENGTH`。解析器先按前四个冒号分割头部，剩余部分再按 `LENGTH` 划分为载荷和填充，因此载荷可以包含冒号。

### 5.2 字段定义

| 字段 | 含义 | 是否参与 CRC |
|---|---|---|
| `PV1` | 固定魔数和主版本 | 否 |
| `TYPE` | 消息类型 | 是 |
| `LENGTH` | `PAYLOAD` 的字节数 | 否 |
| `CRC16` | 四位大写十六进制校验值 | 不适用 |
| `PAYLOAD` | 消息载荷 | 是 |
| `PADDING` | 传输层空格填充 | 否 |
| LF | 帧结束符 | 否 |

### 5.3 长度

`LENGTH` 是原始 `PAYLOAD` 的字节数，不是字符数，也不包含：

- `PV1:` 头部；
- 类型、长度、CRC 及分隔冒号；
- 传输填充空格；
- 结尾 LF。

当前实现允许的最大帧载荷为 16 KiB。

### 5.4 CRC-16/CCITT-FALSE

CRC 参数如下：

| 参数 | 值 |
|---|---|
| 名称 | CRC-16/CCITT-FALSE |
| 多项式 | `0x1021` |
| 初始值 | `0xFFFF` |
| 输入反射 | false |
| 输出反射 | false |
| 最终异或 | `0x0000` |
| 标准测试向量 | `CRC("123456789") = 0x29B1` |

CRC 输入必须严格为：

```text
ASCII(TYPE) + b":" + PAYLOAD
```

CRC 不覆盖魔数、长度、填充和 LF。发送方使用四位大写十六进制输出；接收方可以按十六进制解析，但规范发送方必须使用大写。

RP2040 实现使用 256 项、16 位字节查找表。表占约 512 字节，每个输入字节只执行一次查表，避免 MicroPython 逐位算法造成明显延迟。

定制 UF2 可内置接口版本为 `1` 的 `fn_protocol` 用户 C 模块，由 C 完成帧头、长度、
尾部填充及 CRC 校验。Pico 启动代码会检查模块版本和 `parse_frame` 接口；模块缺失、
版本不匹配或接口不完整时，自动回退到上述纯 Python 查表实现，协议线格式不变。

## 6. 64 字节传输块

### 6.1 Monitor 到 Pico

Monitor 发送的每个 PV1 帧必须补齐为 64 字节的整数倍：

```text
padding_length = -(header_and_payload_length + 1) mod 64
```

发送顺序为：

```text
头部 + 载荷 + padding_length 个 ASCII 空格 + LF
```

因此 LF 总是位于一个 64 字节传输块的最后一个字节。

Monitor 当前将完整帧按最多 511 字节一块交给 pySerial。单次写入长度不得是 64 的整数倍；若最后剩余部分恰好是 64 的整数倍，必须再拆成一个非整倍数短块和余下字节。511 只是主机写入粒度，不是 PV1 消息边界。

在 POSIX/Linux 上，每个短块后执行 `flush()` 并等待约 2ms，防止 CDC 驱动重新合并为恰好 64 字节的满端点传输。64 字节 PING 因此按 63+1 两次物理写入，但逻辑上仍是一条完整 PV1 帧。

### 6.2 Pico 到 Monitor

Pico 响应帧当前不补齐到 64 字节，直接以 LF 结束。主机使用带超时的 `readline()` 接收，不依赖固定块读取。

### 6.3 填充校验

接收方必须：

1. 根据 `LENGTH` 截取载荷；
2. 检查载荷后、LF 前的剩余字节；
3. 剩余字节只能是 ASCII 空格；
4. 任何其他尾随字节必须返回 `BAD_FRAME_TRAILER`。

## 7. 接收状态机

### 7.1 未同步状态

Pico 不得在尚未识别 PV1 魔数时直接执行 `readinto(64)`。`poll()` 只证明至少一个字节可读，不保证已经存在 64 字节。

未同步时接收方必须：

1. 每次只读取一个已由 `poll()` 确认可读的字节；
2. 在缓存中搜索 `PV1:`；
3. 丢弃魔数之前的所有垃圾字节；
4. 尚未找到完整魔数时只保留最后三个字节，以便跨读取匹配 `PV1:`。

这能避免 ModemManager、brltty、串口终端或其他程序写入短 `AT` 探测命令后，Pico 因等待固定长度而永久阻塞。

### 7.2 已同步状态

缓存以 `PV1:` 开头后，接收方进入批量模式。Monitor 保证帧总长度是 64 的整数倍，因此 Pico 可以读取到下一个 64 字节边界：

```text
read_size = 64 - (buffer_length mod 64)
```

批量模式显著减少 MicroPython 轮询次数。例如约 4.4 KiB 的帧从约 4400 次单字节读取降为约 73 次读取。

### 7.3 帧完成与多帧

- 接收方先解析第四个冒号之前的帧头，再用 `LENGTH` 计算载荷末端和下一个 64 字节边界。
- `JSONB` 只有在计算出的物理边界末字节为 LF 时才算完整，载荷内部 LF 不参与定界。
- 文本类型继续接受 LF 定界，以兼容旧的无填充诊断帧。
- 消费当前帧后，剩余字节保留给下一帧。
- 一次轮询可以接收一个帧的一部分、一个完整帧或多个连续帧。
- 应用层只能处理通过全部结构检查和 CRC 检查的帧。

### 7.4 半包超时

缓存非空且连续 1000ms 没有收到新字节时：

1. 清空接收缓存；
2. 清除帧开始时间和读取计数；
3. 返回 `ERR` 帧，载荷为 `FRAME_TIMEOUT`；
4. 回到未同步状态。

### 7.5 大小限制

当前 Pico 每轮最多读取 4096 字节。接收缓存上限取以下较大值并预留一个传输块：

```text
max(MAX_JSON_SIZE + 64, MAX_UPGRADE_LINE_SIZE + 64)
```

当前参数：

- `MAX_JSON_SIZE = 16 KiB`
- `MAX_UPGRADE_LINE_SIZE = 1024`
- `SERIAL_READ_BUDGET = 4096`

超过接收缓存上限时必须清空缓存并返回 `ERR: FRAME_TOO_LARGE`。

### 7.6 批量读取的安全边界

当前 RP2040 优化实现只凭完整魔数 `PV1:` 切换到 64 字节批量读取。普通非协议垃圾不会触发批量模式，但一个恰好以 `PV1:` 开头、又没有补齐到 64 字节的伪帧仍可能使底层阻塞式 `readinto()` 等待后续字节。

因此：

- 合规发送方必须一次发送完整、64 字节对齐的 Monitor→Pico 帧；
- 系统应通过串口独占、udev 规则和禁用 ModemManager 探测，避免其他进程写入；
- 面向不可信串口写入者的实现应使用真正的非阻塞批量读取或具备底层读取超时，不得仅依赖魔数；
- 1 秒协议超时只能处理中间返回主循环的半包，不能中断已经进入底层阻塞调用的读取。

## 8. 帧校验顺序

接收方必须按以下顺序处理帧：

1. 搜索并定位 `PV1:` 魔数；
2. 检查头部分隔字段数量；
3. 解析十进制 `LENGTH`；
4. 解析十六进制 `CRC16`；
5. 检查长度范围；
6. 按长度截取载荷；
7. 检查尾部只有空格填充；
8. 计算并比较 CRC；
9. 识别消息类型；
10. 对载荷执行 Base64、解压、JSON 或升级命令解析；
11. 仅在全部成功后修改应用状态。

未经 CRC 校验的数据不得交给 JSON 解析器、解压器、升级管理器或 LCD 渲染器。

## 9. 消息类型

### 9.1 `PING`

方向：Monitor → Pico

载荷为空。用于设备发现和握手。

逻辑帧示例（省略填充）：

```text
PV1:PING:0:<CRC>:\n
```

Monitor 最多尝试三次，每次等待约 1.2 秒，只接受通过校验且类型为 `PONG` 的响应。

Linux/POSIX 实现首次握手前执行恢复性同步：清空主机输入输出缓冲，发送 64 个 LF 作为无害边界，等待至少 1 秒让 Pico 的半包超时状态复位，再清空收到的诊断残留并发送正式 `PING`。同步块不是 PV1 帧，接收方只能将其用于丢弃旧半包，不得交给应用层。

### 9.2 `PONG`

方向：Pico → Monitor

载荷是未压缩 UTF-8 JSON，包含：

```json
{
  "board_model": "ESP32-S3",
  "device_id": "17226b1f-68ae-8acd-af07-46450f642874",
  "screen_color_profile": "st7789_2_4inch",
  "firmware_version": "1.2.3",
  "device_name": "PICO_LCD",
  "lcd_driver": "ST7789",
  "width": 240,
  "height": 320,
  "pixel_format": "RGB565"
}
```

ESP32-S3 的 `device_id` 是稳定的设备 UUID：固件读取芯片 eFuse MAC，计算
SHA-256 后取前 128 位，并设置 UUID v8 版本位和 RFC 变体位。Monitor 不接收、
记录或展示原始 MAC；旧版固件未提供该字段时，Monitor 按未知设备 UUID 兼容处理。

### 9.3 `JSONZ`

方向：Monitor → Pico

用于兼容旧的非事务快照和 JSON 命令。新固件的大快照不得使用 JSONZ 事务分片。

```text
应用快照
  → 删除线路上重复的顶层 disks（存在 physical_disks 时）
  → 紧凑 UTF-8 JSON
  → zlib 压缩
  → Base64
  → PV1 JSONZ 帧
  → 64 字节传输填充
```

`JSONZ` 的 `LENGTH` 和 CRC 针对 Base64 文本载荷，而不是压缩前 JSON 或 Base64 解码后的 DEFLATE 数据。

解压后的 JSON 使用模式信封。监控快照格式为：

```json
{"mode":"snapshot","request_id":1,"data":{"host":"示例主机","display":{"dev":false}}}
```

命令格式为：

```json
{"mode":"command","command":"reboot","params":{},"request_id":"可选请求编号"}
```

固件暂时兼容没有 `mode` 字段的旧快照对象。新实现不得再增加独立的 PV1
命令类型；配置修改、升级和重启等操作都应通过 JSON 命令策略扩展。

命令结果使用 `COMMAND` 帧返回 JSON：

```json
{"status":"ok","command":"config.update","data":{"restart_required":true},"request_id":"1"}
```

固件从 `picoRP2040/command` 自动发现公开 `COMMAND_STRATEGY` 的模块。自定义策略
必须继承 `CommandStrategy`、声明唯一 `name`，并实现带中文规范注释的 `execute` 方法。

### 9.4 `JSONB`

方向：Monitor → Pico

用于高效传输完整大快照。Monitor 对整份紧凑 JSON 只执行一次 zlib 压缩，再直接切割压缩字节；不生成差异操作、不维护事务基线，也不执行事务提交。每片载荷由 13 字节大端序二进制头和数据组成：

| 偏移 | 长度 | 字段 | 含义 |
|---|---:|---|---|
| 0 | 1 | version | JSONB 子协议版本，当前为 1 |
| 1 | 4 | request_id | 无符号请求编号 |
| 5 | 2 | sequence | 从 0 开始的片序号 |
| 7 | 2 | count | 总片数 |
| 9 | 4 | total_size | 全部 zlib 压缩字节总长度 |
| 13 | 可变 | data | 当前片的原始压缩字节 |

设备仅接受严格顺序分片。收到乱序、缺片后的后续片、头冲突或长度越界时，必须立即清空当前重组缓冲并返回 `ERR`；下一次传输从第 0 片重新开始。全部分片收齐后，设备一次解压、解析并替换完整快照，再返回对应 ACK。

PONG 中的 `snapshot_chunks.version=3`、`encoding=jsonb`、`mode=binary` 表示支持该模式。版本 1/2 的 JSONZ 事务能力已经废弃，Monitor 不得回退使用。

### 9.5 `ACK`

方向：Pico → Monitor

成功接收、校验、解压并解析快照后返回对应请求序号：

```text
TYPE    = ACK
PAYLOAD = JSON:<request_id>
```

旧版无请求序号快照仍返回 `ACK/JSON`。Monitor 的周期发送不等待 ACK；已经到达的
ACK 由后续循环非阻塞消费，请求序号用于关联日志与错误诊断，不参与发送流控。

### 9.6 `ERR`

方向：双向均可，当前主要由 Pico 返回

载荷是 ASCII 错误码。规范错误码如下：

| 错误码 | 含义 |
|---|---|
| `BAD_FRAME_HEADER` | 头部字段缺失或数值无法解析 |
| `BAD_FRAME_LENGTH` | 长度越界或实际数据不足 |
| `BAD_FRAME_TRAILER` | 载荷后存在非空格尾随内容 |
| `BAD_FRAME_CRC` | CRC 不匹配 |
| `BAD_FRAME_TYPE` | 类型不是 ASCII |
| `FRAME_TIMEOUT` | 半包空闲超过 1000ms |
| `FRAME_TOO_LARGE` | 接收缓存超过上限 |
| `BAD_JSON` | Base64、zlib、UTF-8 或 JSON 处理失败，或发生内存不足 |
| `BAD_JSONB_HEADER` | JSONB 二进制子头无效或版本不支持 |
| `BAD_JSONB_SEQUENCE` | JSONB 分片乱序、缺片或批次冲突 |
| `BAD_JSONB_LENGTH` | JSONB 重组长度与声明不一致 |
| `BAD_JSONB_LIMIT` | JSONB 分片数量或总长度超过设备上限 |
| `JSONB_TIMEOUT` | JSONB 分片超过 10 秒仍未收齐，重组缓冲已释放 |
| `UPGRADE_UNAVAILABLE` | 固件未启用升级管理器 |
| `UNKNOWN_TYPE` | 消息类型不受支持 |

固件返回 `BAD_FRAME_LENGTH` 时附带不包含业务载荷的长度现场，例如：

```text
BAD_FRAME_LENGTH:DECLARED=1772:REMAINDER=1771:SHORTAGE=1:MAX=16384:LINE_BYTES=1791:READS=4:BACKEND=PYTHON
```

`DECLARED` 是帧头声明的载荷长度，`REMAINDER` 是第四个冒号后实际收到的总字节数，
`SHORTAGE` 是不足字节数；超出上限时额外提供 `OVER_LIMIT`。`READS` 是固件接收该行的
累计读取次数，`BACKEND` 表示本次使用的帧解析后端。

### 9.7 `EVENT`

方向：Pico → Monitor

承载启动、配置、LCD 绘制和性能诊断消息。载荷是 UTF-8 或 ASCII 文本。常见事件：

```text
BOOT:PICO_LCD_READY
CONFIG:LCD_STYLE:horizontal_disk4x_qb
ACK:LCD_FRAME:<version>:TOTAL=...MS:...:CANVAS_BACKEND=C:PROTOCOL_BACKEND=C:LCD_BACKEND=NATIVE_DMA
PROTOCOL_TIMING:TYPE=JSONZ:...
FATAL:<ExceptionType>:<message>
```

`PROTOCOL_BACKEND` 为 `C` 时表示 PV1 帧由 UF2 原生模块解析，为 `PYTHON` 时表示使用 Python 兼容解析器。
`LCD_BACKEND` 为 `NATIVE_DMA` 时表示像素使用内部 DMA 双缓冲发送，为 `LEGACY` 时表示使用标准 `machine.SPI.write()`。

`display.dev` 由 Monitor 的 Dev 开关穿透到 Pico。关闭时 Pico 不发送
`PROTOCOL_TIMING` 和 `ACK:LCD_FRAME` 高频性能事件，仅保留 `ACK`、`CONFIG`、
命令结果、错误及启动等低频必要信息；开启时恢复完整诊断事件。

`EVENT` 不构成对请求的确认，Monitor 必须继续等待对应 `ACK`、`PONG` 或 `STATUS`。

### 9.8 `COMMAND`

方向：Pico → Monitor

载荷是 UTF-8 JSON 命令执行结果。成功和失败分别使用 `ok`、`error` 状态，
并原样返回请求中的可选 `request_id`。命令级错误使用此帧返回，不应误报为
传输层 `ERR`。

升级使用 `JSONZ` 中名为 `upgrade` 的命令，支持以下 `params.action`：

```text
begin
file
data
file_end
commit
abort
```

升级文件数据在 `data` 动作内使用 Base64。每个升级命令仍由 JSONZ 压缩信封、PV1 长度和 CRC 保护。

### 9.9 `STATUS`

方向：Pico → Monitor

用于返回升级确认、进度和错误文本，例如：

```text
ACK:UPGRADE:BEGIN:<version>
ACK:UPGRADE:DATA:<sequence>
PROGRESS:UPGRADE:INSTALL:<percent>
ACK:UPGRADE:COMPLETE:<version>
ERR:UPGRADE:<reason>
```

## 10. 压缩与二进制分片规范

### 10.1 JSON 预处理

Monitor 必须：

- 使用 UTF-8 编码；
- 使用紧凑分隔符 `,` 和 `:`；
- 当前实现将非 ASCII 字符转义为 `\uXXXX`；
- 当 `physical_disks` 存在时，不在线路上重复发送顶层 `disks`；
- 不修改采集器持有的原始快照对象。

### 10.2 zlib 参数

| 参数 | 值 |
|---|---|
| 容器格式 | zlib |
| DEFLATE 压缩级别 | 6 |
| 窗口位数 | 9 |
| 窗口大小 | 512 字节 |
| 字典 | 无 |

不得使用 zlib 默认的 15 位、32 KiB 窗口。RP2040 的 MicroPython 堆可能因碎片化无法提供连续 32768 字节，导致 `MemoryError`。

Monitor 使用等价于以下过程的压缩：

```python
compressor = zlib.compressobj(level=6, wbits=9)
compressed = compressor.compress(json_bytes) + compressor.flush()
```

### 10.3 JSONB 二进制分片

快照的 zlib 结果直接进入 JSONB `data`，不执行 Base64。接收状态机按 PV1 `LENGTH` 和 64 字节物理块定位帧尾，因此压缩结果中的 LF 不会截断帧。

JSONZ 仅为旧非事务快照和命令保留 Base64 编码；JSONB 快照链路不得回退 JSONZ 事务。

### 10.4 Pico 解压

Pico 的解码顺序为：

1. 校验 PV1 CRC；
2. 解析 JSONB 子头并严格按序追加压缩字节；
3. 收齐后使用 zlib 容器和 9 位窗口解压；
4. 检查压缩总长和解压后大小不超过设备声明的 `max_bytes`；
5. UTF-8 解码；
6. JSON 解析；
7. 更新最新快照缓存；
8. 返回 `ACK/JSON`。

MicroPython 1.27 固件不保证提供 `zlib` 或 `uzlib` 模块。当前实现优先使用 `zlib.decompress(data, 15)`；不存在 `zlib` 时，使用：

```python
deflate.DeflateIO(io.BytesIO(data), deflate.ZLIB, 9)
```

### 10.5 内存约束

- zlib 窗口固定为 512 字节。
- JSONB 不产生 Base64 文本及其解码副本。
- 解压会产生一份 JSON 字节串。
- JSON 解析会产生字典、列表和字符串对象。
- `MemoryError` 必须被捕获并转换为 `ERR/BAD_JSON`，不得让协议主循环进入 FATAL 状态。
- 当前实现解压后检查 16 KiB 上限。安全等级更高的实现应采用有输出上限的流式解压，在分配完整输出前阻止解压炸弹。

## 11. 典型交互

### 11.1 握手

```text
Monitor → Pico: PING(empty)
Pico → Monitor: PONG(device JSON)
```

### 11.2 快照

```text
Monitor → Pico: JSONB#0(binary-header + zlib(JSON)[0:n])
Monitor → Pico: JSONB#1(binary-header + zlib(JSON)[n:m])
Pico → Monitor: EVENT(PROTOCOL_TIMING...)
Pico → Monitor: ACK(JSON)
```

处理失败时：

```text
Monitor → Pico: JSONB(...)
Pico → Monitor: ERR(BAD_FRAME_CRC | BAD_JSONB_SEQUENCE | BAD_JSON | ...)
```

### 11.3 升级

```text
Monitor → Pico: UPGRADE(BEGIN...)
Pico → Monitor: STATUS(ACK:UPGRADE:BEGIN...)
Monitor → Pico: UPGRADE(FILE...)
Pico → Monitor: STATUS(ACK:UPGRADE:FILE...)
Monitor → Pico: UPGRADE(DATA...)
Pico → Monitor: STATUS(ACK:UPGRADE:DATA...)
Monitor → Pico: UPGRADE(FILE_END)
Pico → Monitor: STATUS(ACK:UPGRADE:FILE_END...)
Monitor → Pico: UPGRADE(COMMIT)
Pico → Monitor: STATUS(PROGRESS...)
Pico → Monitor: STATUS(ACK:UPGRADE:COMPLETE...)
```

## 12. 性能诊断

Monitor 记录：

- 构帧耗时；
- 每次 pySerial 写入的请求字节数、实际字节数和阻塞耗时；
- write 合计和最慢 write；
- flush 耗时；
- ACK 等待耗时；
- 构帧到 ACK 的总耗时。

Pico 在处理 `JSONB` 后发送 `PROTOCOL_TIMING` 事件：

```text
PROTOCOL_TIMING:
TYPE=JSONB:
BYTES=<PV1 line bytes>:
JSON_BYTES=<decompressed bytes>:
READS=<read calls>:
RX=<receive ms>MS:
FRAME_PARSE=<header+CRC ms>MS:
DECOMPRESS=<zlib ms>MS:
JSON=<json parse ms>MS
```

诊断事件在 `ACK/JSON` 之前发送，因此 Monitor 可以在本次交互日志中看到完整分段耗时。

## 13. 错误恢复要求

- 坏头、坏长度、坏尾部或坏 CRC：不得处理载荷，返回对应 `ERR`。
- 未知类型：返回 `ERR/UNKNOWN_TYPE`。
- JSONB 头、顺序或重组长度错误：清空重组缓冲并返回对应 `BAD_JSONB_*` 错误。
- JSONZ/Base64 或 JSONB/zlib 解码、UTF-8、JSON 处理失败：返回 `ERR/BAD_JSON`。
- 解压内存不足：捕获 `MemoryError`，返回 `ERR/BAD_JSON`，保持主循环运行。
- 半包超时：清空缓存并返回 `ERR/FRAME_TIMEOUT`。
- 缓存超限：清空缓存并返回 `ERR/FRAME_TOO_LARGE`。
- 收到非 PV1 垃圾：逐字节扫描并丢弃，直到重新发现 `PV1:`。
- Monitor 收到 `EVENT` 时不得误认为请求完成。
- Monitor 只接受与当前请求匹配的确认类型。

## 14. 实现一致性检查

实现至少应覆盖以下测试：

1. 标准 CRC 向量 `123456789 → 29B1`。
2. 主机与 Pico 对随机载荷计算相同 CRC。
3. 帧载荷包含冒号时仍能正确解析。
4. 长度不足、超长、坏十六进制和非空格尾部被拒绝。
5. 单字节、跨块和多帧连续输入。
6. 魔数前存在 `AT` 等无换行垃圾时能重新同步。
7. 普通短垃圾不会触发 64 字节阻塞读取。
8. 半包空闲 1000ms 后被丢弃。
9. JSONB 的 zlib 数据包含 LF 时仍按长度完整传输，不提前截帧。
10. zlib 头声明 9 位窗口，即 512 字节。
11. 解压后 JSON 超过 16 KiB 被拒绝。
12. 解压 `MemoryError` 不终止固件主循环。
13. `EVENT` 不会被当作 `ACK`。
14. 升级序号、文件长度和 SHA-256 验证失败时不会提交安装。

## 15. 版本演进

- `PV1` 是完整主版本魔数，而不是独立的版本字段。
- 不兼容的帧格式变更必须使用新魔数，例如 `PV2`。
- 在 PV1 内新增消息类型属于兼容扩展；旧接收方会返回 `UNKNOWN_TYPE`。
- 改变 CRC 参数、字段顺序、长度含义、填充规则或 JSONZ 编码流水线属于不兼容变更。
- 当前项目明确不兼容 PV1 之前的裸文本协议。

## 16. 安全说明

- CRC 不是 MAC，不能验证发送方身份。
- USB 串口被本机不可信进程访问时，应使用操作系统权限和独占锁保护。
- Linux 建议通过 udev 设置设备权限并禁止 ModemManager 探测。
- 升级包除 PV1 CRC 外，还必须继续验证清单中的文件长度和 SHA-256。
- 路径必须拒绝绝对路径、空路径、隐藏暂存路径和 `..` 路径穿越。
- 任何实现都不得在 CRC 校验前执行升级命令或解析 JSON。

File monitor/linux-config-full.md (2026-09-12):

# Linux DEB 配置完整说明

本文说明 Pico Monitor Linux DEB 安装包使用的配置文件、所有可配置项、取值限制和常见用途。文中的配置适用于 Debian、Ubuntu、Linux Mint、Raspberry Pi OS 等使用 APT 的系统；使用通用 tar 包的 Linux 主机也可以复用同一套 YAML 配置。

## 先确认：这里不是自定义内核驱动

Pico Monitor 是用户态监控程序，不会安装或编译自定义 Linux 内核模块。DEB 包通过 Python、`/proc`、`/sys`、`smartmontools`、系统串口驱动和可选的 NVML/显卡接口读取指标，再通过 USB CDC 或 WebSocket 发送给 Pico LCD。Linux 内核、USB 串口、显卡和磁盘驱动仍由发行版负责。

因此，本文中的“驱动配置”实际指 Linux DEB 服务和 Pico Monitor 的运行配置；修改配置不会改变内核驱动参数。如果 `/dev/ttyACM*`、GPU 温度或磁盘 SMART 不可用，应先检查内核模块、设备权限和硬件支持。

## 配置文件位置和生效方式

DEB 安装后使用以下文件：

```text
/etc/pico-monitor.conf
```

仓库中的默认模板是 [`debian/pico-monitor.conf`](debian/pico-monitor.conf)。安装脚本只在目标文件不存在时复制模板，因此升级 DEB 通常会保留你已经修改的配置。

systemd 服务通常位于 `/lib/systemd/system/pico-monitor.service` 或 `/etc/systemd/system/pico-monitor.service`，启动命令为：

```text
/usr/bin/pico-monitor --config /etc/pico-monitor.conf
```

配置修改后重启服务：

```bash
sudo systemctl daemon-reload
sudo systemctl restart pico-monitor
sudo systemctl status pico-monitor --no-pager
```

查看实时日志：

```bash
sudo journalctl -u pico-monitor -f
```

### 配置优先级

同一个选项同时出现在多个位置时，优先级从高到低为：

1. 命令行参数，例如 `--interval 2`。
2. 对应的 `PICO_MONITOR_*` 环境变量。
3. YAML 文件中的嵌套键，例如 `monitor.interval`。
4. 程序内置默认值。

systemd 的 DEB 服务不会自动读取交互式 Shell 的环境变量。需要通过环境变量覆盖配置时，应使用 systemd drop-in：

```bash
sudo systemctl edit pico-monitor
```

```ini
[Service]
Environment=PICO_MONITOR_INTERVAL=2
Environment=PICO_MONITOR_HTTP_AUTH=请替换为随机长密钥
```

保存后执行：

```bash
sudo systemctl daemon-reload
sudo systemctl restart pico-monitor
```

### YAML 语法和类型

- 文件必须是一个 YAML 对象，推荐使用 UTF-8 无 BOM 编码。
- 布尔值使用 `true` 或 `false`，不要把 `on`、`off` 当成 YAML 布尔值依赖解析器行为。
- URL、设备路径、密码和包含特殊字符的字符串建议使用双引号。
- 时间间隔支持整数和小数，单位统一为秒。
- 数字、布尔值和对象不要写成带引号的字符串，除非该字段明确要求字符串。
- 未知键会被忽略，不会自动变成新的运行参数；拼写错误通常表现为“配置看起来正确但仍使用默认值”。

## 一份可直接修改的完整示例

下面的示例合并了 DEB 模板和高级选项。首次使用时至少修改 `serial.port`、网络连接方式和 `http.auth`；没有固定串口时可把 `serial.port` 留空。

```yaml
# /etc/pico-monitor.conf
serial:
  port: ""                         # 例如 /dev/ttyACM1；留空自动发现
  probe_interval: 3.0              # USB PING 探测间隔，秒

network:
  websocket_url: ""               # 例如 ws://192.168.1.50:8765/pv1
  force_usb_cdc: false             # true 时只使用 USB，不搜索 Wi-Fi
  websocket_client_name: ""       # WebSocket 握手时显示的客户端名称
  websocket_client_id: ""         # 稳定客户端标识，留空自动生成
  discovery_strategy: announcement # announcement 或 scan
  announcement_port: 37856
  announcement_group: "239.255.77.77"
  announcement_timeout: 3.0
  ping_target: "www.baidu.com"
  unit: MB                         # MB 或 Mbps
  # 以下四项在当前版本建议通过同名环境变量或命令行覆盖；
  # 解析器暂未把它们映射到嵌套 YAML 路径：
  # lan_probe_port: 8765
  # lan_probe_path: "/pv1"
  # lan_probe_timeout: 0.3
  # lan_probe_max_workers: 256

monitor:
  interval: 1.0                    # DEB 模板值；裸程序默认值为 0.5
  adaptive_transmit: true
  reconnect_interval: 3.0
  dev: false

screen:
  rotation: 0                      # 0 或 180
  lcd_brightness: 100              # 1 到 100；裸程序默认值为 50
  lcd_style: "fps_simple"
  idle_enabled: true               # false 表示永不进入待机样式
  idle_style: "idle"
  idle_timeout: 30

collection_tasks:
  logs_enabled: true
  intervals:
    basic_information: 1
    cpu_memory: 1
    disk_capacity_health: 60
    disk_temperature: 5
    disk_rate: 1
    network: 1
    power: 1
    gpu: 1
    # Linux 不会注册 Windows 专属 fps 任务；自定义任务示例：
    # custom_data.my_data: 5

custom_data:
  configs:
    # 插件名称必须与 plugin.json 中的 name 相同。
    # my_data:
    #   interval: 5
    #   endpoint: "http://127.0.0.1:9000/metrics"
  enabled:
    # 当前版本建议通过 PICO_MONITOR_CUSTOM_DATA_ENABLED 环境变量或管理页面维护；
    # 嵌套 YAML 的 enabled 键暂未纳入文件解析映射。
    # my_data: true

qbittorrent:
  enabled: false
  address: "http://127.0.0.1:8080"
  username: "admin"
  password: "请替换为 qBittorrent 密码"
  interval: 2.0

disk_health_test:
  index: 0                         # 0 关闭；从 1 开始选择磁盘
  level: 3                         # 0 到 5

upgrade:
  url: ""                          # 留空使用当前版本默认 Release 地址
  sha256: ""                       # 可选 SHA-256

market:
  url: "https://omni.mzlblog.com"

logging:
  level: INFO                       # DEBUG、INFO、WARNING、ERROR、CRITICAL

diagnostics:
  threads: false
  thread_interval: 10.0

sensor_host:
  enabled: true                     # 仅 Windows 使用，Linux 会忽略
  path: ""
  pipe: "omniwatch.sensorhost"

http:
  enabled: true                     # DEB 模板开启；裸程序默认关闭
  host: "127.0.0.1"                # 局域网访问可改为 0.0.0.0
  port: 9876
  auth: "请替换为随机长密钥"
```

## `serial`：USB CDC 串口

| 配置项 | 类型和默认值 | 取值要求 | 作用和示例 |
| --- | --- | --- | --- |
| `serial.port` | 字符串；默认空 | Linux 设备路径或空字符串 | 固定使用某个数据 CDC，例如 `"/dev/ttyACM1"`。留空时程序扫描可用串口并通过 PV1 PING/PONG 识别 Pico，不建议把随机变化的 `/dev/ttyACM0` 写死。 |
| `serial.probe_interval` | 浮点数；`3.0` 秒 | 必须大于 0 | 没有连接时发送 USB 探测 PING 的间隔。设备频繁插拔或串口枚举较慢时可调到 `5`；需要更快发现时可设为 `1`。 |

USB 数据 CDC 和 MicroPython REPL CDC 可能同时出现。自动发现会用握手区分二者；固定端口时必须填写能返回 PV1 PONG 的接口。

示例：

```yaml
serial:
  port: "/dev/serial/by-id/usb-Raspberry_Pi_Pico_XXXX-if01"
  probe_interval: 2.0
```

使用 `/dev/serial/by-id/` 比使用 `/dev/ttyACM0` 稳定，因为前者通常包含设备序列号和接口信息。

## `network`：Wi-Fi、WebSocket、局域网发现和延迟

| 配置项 | 类型和默认值 | 取值要求 | 作用和示例 |
| --- | --- | --- | --- |
| `network.websocket_url` | 字符串；默认空 | `ws://` 或 `wss://` 地址，通常包含 `/pv1` | 固定通过 Wi-Fi 连接设备，例如 `"ws://192.168.1.50:8765/pv1"`。服务启动的主动探测仍先尝试 USB，USB 不可用后使用该地址；后续重连也会优先直连该地址。设备 IP 使用 DHCP 时不建议长期写死。 |
| `network.force_usb_cdc` | 布尔；`false` | `true` 或 `false` | `true` 时强制 USB CDC，并停止 WebSocket 直连、UDP 公告和局域网搜索。升级 Pico 或排查 Wi-Fi 时可临时启用。 |
| `network.websocket_client_name` | 字符串；默认空 | 任意短名称 | 写入 WebSocket 握手，便于设备端或日志区分客户端，例如 `"nas-monitor"`。 |
| `network.websocket_client_id` | 字符串；默认空 | 建议稳定且唯一 | 固定客户端身份。留空时按设备名称和网卡标识生成；多台 Monitor 共存时可显式设置，如 `"nas-01"`。 |
| `network.discovery_strategy` | 枚举；`announcement` | `announcement` 或 `scan` | `announcement` 先监听 ESP32 UDP 公告，超时后扫描网段；`scan` 直接扫描网段。组播被交换机隔离时可改为 `scan`。 |
| `network.announcement_port` | 整数；`37856` | 1 到 65535 | Monitor 监听 ESP32 主动公告的 UDP 端口，必须与固件一致。防火墙放行该 UDP 端口后才可接收公告。 |
| `network.announcement_group` | 字符串；`239.255.77.77` | 合法 IPv4 组播地址 | ESP32 公告组播地址。一般保持默认；多套隔离网络需要自定义组播地址时，两端必须相同。 |
| `network.announcement_timeout` | 浮点数；`3.0` 秒 | 必须大于 0 | 每轮等待 UDP 公告的最长时间。公告丢失后会转入网段扫描；网络较慢时可提高到 `5`。 |
| `network.ping_target` | 字符串；`www.baidu.com` | 域名或 IP | 用于生成网络延迟和在线状态。内网无外网时可改为网关，例如 `"192.168.1.1"`；目标不可达会使 `online` 显示离线，但不影响串口。 |
| `network.unit` | 枚举；`MB` | `MB` 或 `Mbps` | LCD 速率显示单位。`MB` 使用 B/s、KB/s、MB/s、GB/s；`Mbps` 使用 bps、Kbps、Mbps、Gbps。 |
| `network.lan_probe_port` | 整数；`8765` | 1 到 65535 | 网段扫描时尝试连接 Pico WebSocket 服务的 TCP 端口。设备端修改端口后必须同步。 |
| `network.lan_probe_path` | 字符串；`/pv1` | WebSocket 路径 | 网段扫描使用的升级路径，通常保持 `/pv1`。 |
| `network.lan_probe_timeout` | 浮点数；`0.3` 秒 | 必须大于 0 | 每个候选 IP 的连接超时。跨 VLAN 或无线较慢时可设 `0.8`；过大将使扫描等待明显变长。 |
| `network.lan_probe_max_workers` | 整数；`256` | 必须大于 0 | 网段扫描并发数。低功耗 NAS 可设 `32` 或 `64`，避免瞬时创建过多 TCP 连接。 |

### USB 优先级和 Wi-Fi 发现流程

未设置 `force_usb_cdc` 时，服务启动会先尝试 USB；没有可用 USB 连接时再按以下逻辑处理：

1. 有 `websocket_url` 时尝试固定地址。
2. `discovery_strategy=announcement` 时监听 `announcement_group:announcement_port`。
3. 公告窗口没有有效设备时执行局域网扫描。
4. 所有候选地址都要经过 TCP、WebSocket 升级和 PV1 握手三步确认。

如果 USB 数据线仍连接设备，USB 会优先于 Wi-Fi。验证纯 Wi-Fi 时应断开 USB 数据连接，但保留设备供电。

示例：固定 Wi-Fi 地址并禁用 USB：

```yaml
network:
  websocket_url: "ws://192.168.1.50:8765/pv1"
  force_usb_cdc: true
```

`force_usb_cdc: true` 会使上面的 WebSocket 地址不生效；验证 Wi-Fi 时应改为 `false`。

## `monitor`：采集、发送和重连

| 配置项 | 类型和默认值 | 取值要求 | 作用和示例 |
| --- | --- | --- | --- |
| `monitor.interval` | 浮点数；DEB 模板 `1.0`，程序默认 `0.5` 秒 | 不得小于 `0.3` 秒 | 完整快照的调度和发送周期。设为 `2.0` 可降低低性能 NAS 的 CPU 占用；单项采集任务还可在 `collection_tasks.intervals` 中独立设置。 |
| `monitor.adaptive_transmit` | 布尔；`true` | `true` 或 `false` | 根据 Pico JSON ACK 耗时调整发送节奏，拥塞时只保留最新快照。USB 线路不稳定或调试固定节拍时可设 `false`，但仍保留 ACK 背压。 |
| `monitor.reconnect_interval` | 浮点数；`3.0` 秒 | 必须大于 0 | WebSocket 或设备连接异常后的等待时间。局域网设备重启较慢时可设 `5` 或 `10`。USB 断开时程序还会等待端口重新枚举。 |
| `monitor.dev` | 布尔；`false` | `true` 或 `false` | 开发模式。没有 Pico 时持续采集并打印待发送 JSON，适合在 CI 或没有硬件的主机上检查 Linux 指标；生产服务应关闭。 |

示例：低功耗主机每 2 秒发送，关闭发送自适应：

```yaml
monitor:
  interval: 2.0
  adaptive_transmit: false
  reconnect_interval: 5.0
  dev: false
```

## `collection_tasks`：各类系统指标频率

`collection_tasks.intervals` 的键必须是任务英文标识，值是大于 0 的秒数。未填写的任务保持默认频率；未知键会被忽略。任务执行由线程池调度，某个任务暂时失败不会阻止其他任务继续发送。

| 任务键 | 中文含义 | Linux 默认值 | 采集内容和调整建议 |
| --- | --- | ---: | --- |
| `basic_information` | 基础信息采集 | `1` | 主机名、平台、系统运行时间等低成本信息。一般保持 `1`。 |
| `cpu_memory` | CPU 与内存采集 | `1` | CPU 使用率、频率、温度、内存使用率和历史曲线。CPU 很弱时可设 `2`。 |
| `disk_capacity_health` | 磁盘容量与健康 | `60` | 分区容量、占用率、SMART 健康等级。SMART 查询可能较慢，不建议设为 `1`。 |
| `disk_temperature` | 磁盘温度 | `5` | SATA、NVMe 等物理盘温度。硬盘数量多或 SMART 访问慢时可设 `10`。 |
| `disk_rate` | 磁盘读写速率 | `1` | 读写 B/s、每物理盘速度和 24 秒历史。需要平滑曲线时保持 `1`。 |
| `network` | 网络采集 | `1` | 上传/下载速率、累计流量、网卡速率、Ping 和在线状态。只关心总流量时可设 `2`。 |
| `power` | 功耗采集 | `1` | Linux RAPL 可用时读取实时功耗；不支持的平台返回空值。RAPL 计数器无效时降低频率也不会产生数据。 |
| `gpu` | GPU 采集 | `1` | NVIDIA NVML、AMD sysfs、Intel i915 PMU 等可用后采集 GPU 使用率、温度和显存。无独立 GPU 时可设 `5`。 |
| `fps` | FPS 采集 | 不注册 | 仅 Windows PresentMon/ETW 任务。Linux 配置此键不会创建 FPS 任务。 |
| `custom_data.<插件名>` | 自定义插件 | 插件定义值 | 插件名来自 `plugin.json` 的 `name`，例如 `custom_data.my_data: 5`。插件运行目录和配置格式见 `docs/custom_data_plugin_protocol_v2.md`。 |

DEB 模板中的完整频率示例：

```yaml
collection_tasks:
  logs_enabled: true
  intervals:
    basic_information: 1
    cpu_memory: 1
    disk_capacity_health: 60
    disk_temperature: 5
    disk_rate: 1
    network: 1
    power: 1
    gpu: 1
```

任务频率和 `monitor.interval` 是两层设置。例如 `monitor.interval=0.5`、`disk_capacity_health=60` 表示快照可以每 0.5 秒发送，但磁盘容量和 SMART 数据最多每 60 秒更新一次。

`collection_tasks.logs_enabled` 是布尔值，DEB 模板为 `true`，裸程序默认 `false`。开启后会记录任务提交、开始、完成和线程池状态；关闭后仍保留错误和告警。排查任务卡顿时建议临时开启。

## `custom_data`：自定义数据插件

| 配置项 | 类型和默认值 | 作用 |
| --- | --- | --- |
| `custom_data.configs` | 对象；`{}` | 按插件名保存面板字段，例如 `my_data: {endpoint: "http://127.0.0.1:9000"}`。字段必须符合插件 `plugin.json` 中的 `config_panel` 定义，数字范围、正则和必填项由插件协议校验。 |
| `custom_data.enabled` | 对象；`{}` | 按插件名控制是否启用，例如 `my_data: true`。启用状态通常由 HTTP 管理页面或 Windows 设置页持久化。 |

配置示例：

```yaml
custom_data:
  configs:
    my_data:
      interval: 5
      endpoint: "http://127.0.0.1:9100/metrics"
      token: "只在插件要求时填写"
  enabled:
    my_data: true
```

兼容性提示：当前解析器已经支持 `PICO_MONITOR_CUSTOM_DATA_ENABLED` 环境变量，但没有把它映射到嵌套 YAML 路径。若 `custom_data.enabled` 在你的版本中没有生效，请改用环境变量，或把下面的旧式根键写入配置文件：

```text
PICO_MONITOR_CUSTOM_DATA_ENABLED='{"my_data": true}'
```

插件脚本在独立运行环境中执行，超时或异常会被隔离；不要把插件密码、令牌提交到公开仓库。插件详细字段格式请参阅 [`docs/custom_data_plugin_protocol_v2.md`](docs/custom_data_plugin_protocol_v2.md)。

## `screen`：Pico LCD 显示

| 配置项 | 类型和默认值 | 取值要求 | 作用和示例 |
| --- | --- | --- | --- |
| `screen.rotation` | 整数；`0` | 只能是 `0` 或 `180` | 屏幕倒置安装时设为 `180`。其他角度会在参数校验阶段拒绝。 |
| `screen.lcd_brightness` | 整数；DEB 模板 `100`，程序默认 `50` | 1 到 100 | LCD 背光百分比。夜间运行可设 `20` 或 `30`；设为 `100` 最亮但功耗和发热更高。 |
| `screen.lcd_style` | 字符串；DEB 模板 `fps_simple`，程序默认 `horizontal_disk4x` | 内置样式名或设备已同步的自定义样式名 | 常见内置值：`default`、`disk`、`diskv2`、`diskv3`、`diskv4`、`horizontal_disk`、`horizontal_diskv2`、`horizontal_disk4x`、`horizontal_disk4x_qb`、`horizontal_disk6x`、`simple`、`fpstest`、`fps_simple`、`game`、`idle`。自定义样式必须先上传并同步到设备。 |
| `screen.idle_enabled` | 布尔值；`true` | `true` 或 `false` | 设为 `false` 时设备不会进入待机样式，`idle_style` 与 `idle_timeout` 暂不生效。 |
| `screen.idle_style` | 字符串；`idle` | 设备样式目录中的待机样式 | 连续超过 `idle_timeout` 未收到有效快照后显示的样式。通常保持 `idle`。 |
| `screen.idle_timeout` | 整数；`30` 秒 | 必须大于 0 | Pico 多久没有收到 JSON 后切换到待机样式。USB 或 Wi-Fi 经常短暂断线时可设 `60`，避免频繁切换。 |

示例：倒置安装、低亮度、四盘布局：

```yaml
screen:
  rotation: 180
  lcd_brightness: 35
  lcd_style: "horizontal_disk4x"
  idle_enabled: true
  idle_style: "idle"
  idle_timeout: 60

## `logging` 和 `diagnostics`：日志与线程诊断

### 日志级别

```yaml
logging:
  level: INFO
```

| 配置项 | 默认值 | 说明 |
| --- | --- | --- |
| `logging.level` | `INFO` | 支持 `DEBUG`、`INFO`、`WARNING`、`ERROR`、`CRITICAL`。排查串口握手、WebSocket 扫描和采集耗时时使用 `DEBUG`；生产环境通常使用 `INFO`。 |

### 线程诊断

```yaml
diagnostics:
  threads: false
  thread_interval: 10.0
```

| 配置项 | 类型和默认值 | 说明 |
| --- | --- | --- |
| `diagnostics.threads` | 布尔；`false` | 开启后周期输出 `threading.enumerate()` 摘要和 `faulthandler` 全线程栈。仅在服务卡死、线程池不退出或采集超时期间临时开启。 |
| `diagnostics.thread_interval` | 浮点数；`10.0` 秒 | 诊断输出周期，必须大于 0。设得过小会快速增加日志量。 |

排查结束后关闭线程诊断：

```yaml
diagnostics:
  threads: false
```

## `sensor_host`：外置传感器宿主

该组配置用于 Windows SensorHost 外置硬件传感器进程。Linux 下 `SystemInformationCollector` 不创建 SensorHost，配置会被安全忽略；Linux 温度、GPU 和功耗使用本机 `/sys`、NVML、i915 PMU 或 RAPL 等接口。

| 配置项 | 类型和默认值 | 说明 |
| --- | --- | --- |
| `sensor_host.enabled` | 布尔；`true` | 仅 Windows 有效。Linux 无需为了此项安装额外服务。 |
| `sensor_host.path` | 字符串；默认空 | Windows SensorHost 可执行文件路径。留空时从打包目录查找。 |
| `sensor_host.pipe` | 字符串；`omniwatch.sensorhost` | Windows Named Pipe 名称。只有自定义宿主管道时才修改。 |

## `qbittorrent`：qBittorrent Web API

| 配置项 | 类型和默认值 | 取值要求 | 作用和示例 |
| --- | --- | --- | --- |
| `qbittorrent.enabled` | 布尔；`false` | `true` 时三项连接信息都必须填写 | 是否启动 qBittorrent 后台采集线程。 |
| `qbittorrent.address` | 字符串；默认空 | 例如 `http://127.0.0.1:8080` | qBittorrent Web UI 地址，不要填写 `/api/v2` 后缀。 |
| `qbittorrent.username` | 字符串；默认空 | 登录账号 | Web UI 用户名。 |
| `qbittorrent.password` | 字符串；默认空 | 登录密码 | Web UI 密码。建议使用权限为 `600` 的配置文件或 systemd 环境变量。 |
| `qbittorrent.interval` | 浮点数；`2.0` 秒 | 必须大于 0 | API 采集间隔。qBittorrent 任务很多时可设 `5`。 |

启用示例：

```yaml
qbittorrent:
  enabled: true
  address: "http://127.0.0.1:8080"
  username: "admin"
  password: "替换为实际密码"
  interval: 2.0
```

启用后地址、账号、密码任何一项为空，服务启动校验都会失败。更完整的字段和 API 说明见 [`qbittorrent_config.md`](qbittorrent_config.md)。

## `disk_health_test`：磁盘健康显示测试

此组用于验证 Pico 样式的健康等级颜色和图标，不会修改硬盘 SMART 数据。

| 配置项 | 类型和默认值 | 取值要求 | 说明 |
| --- | --- | --- | --- |
| `disk_health_test.index` | 整数；`0` | `0` 关闭；大于等于 `1` 选择按发送顺序排列的物理磁盘 | 例如 `2` 只让第二块盘进入测试显示。实际磁盘顺序可能随设备枚举变化，长期运行应关闭。 |
| `disk_health_test.level` | 整数；`3` | 0 到 5 | 测试健康等级：`0` 未知、`1` 健康、`2` 注意、`3` 警告、`4` 严重、`5` 失败。 |

测试示例：

```yaml
disk_health_test:
  index: 1
  level: 5
```

验证完成后恢复：

```yaml
disk_health_test:
  index: 0
```

真实 Linux 磁盘健康信息依赖 `smartmontools`。DEB 主依赖不一定自动安装该工具，可手动执行：

```bash
sudo apt-get update
sudo apt-get install -y smartmontools
```

## `upgrade`：Pico 固件在线升级

| 配置项 | 类型和默认值 | 说明 |
| --- | --- | --- |
| `upgrade.url` | 字符串；默认空 | 留空时按当前 Monitor 版本选择 GitHub Release 中的 Pico 全量固件包；本地测试或私有发布可填写 HTTP/HTTPS 地址。 |
| `upgrade.sha256` | 字符串；默认空 | 可选的固件 ZIP SHA-256 摘要。填写后下载完成必须匹配，否则不会写入设备。 |

配置示例：

```yaml
upgrade:
  url: "https://example.com/OmniWatch-pico-full-vlocal-test.zip"
  sha256: "0123456789abcdef0123456789abcdef0123456789abcdef0123456789abcdef"
```

升级命令需要停止 systemd 服务以释放串口：

```bash
sudo systemctl stop pico-monitor
sudo /usr/bin/pico-monitor --config /etc/pico-monitor.conf --upgrade-pico
sudo systemctl start pico-monitor
```

升级提交阶段不要断电、拔线或让主机休眠。`upgrade.url` 和 `upgrade.sha256` 只决定固件包来源和校验，不会执行 Linux DEB 更新。

## `market`：插件市场

```yaml
market:
  url: "https://omni.mzlblog.com"
```

`market.url` 是 HTTP 管理页面加载插件市场和同源资源的地址，默认值为 `https://omni.mzlblog.com`。必须使用 `http://` 或 `https://`；内网部署可改为自建市场地址，例如 `http://192.168.1.10:8081`。如果不使用插件市场，仍可保留默认值，或者在防火墙层面限制管理页面访问。

## `http`：Linux HTTP 管理页面

| 配置项 | 类型和默认值 | 取值要求 | 作用和示例 |
| --- | --- | --- | --- |
| `http.enabled` | 布尔；DEB 模板 `true`，程序默认 `false` | `true` 或 `false` | 启用浏览器管理页面、设备控制和插件市场。无桌面 DEB 主机通常开启；不需要远程管理时可关闭。 |
| `http.host` | 字符串；`0.0.0.0` | 本机地址或绑定网卡地址 | `127.0.0.1` 只允许本机访问；`0.0.0.0` 监听所有 IPv4 网卡，适合局域网管理但必须配合强 Auth 和防火墙。 |
| `http.port` | 整数；`9876` | 1 到 65535 | 管理页面端口，例如 `9988`。修改后需同步防火墙规则。 |
| `http.auth` | 字符串；DEB 模板为示例密钥，裸程序默认空 | 建议至少 32 个随机字符 | WebSocket Upgrade 和管理 API 的鉴权密钥。留空时每次启动随机生成并写入启动日志；首次登录后应立即改成随机长密钥。 |

推荐的仅本机配置：

```yaml
http:
  enabled: true
  host: "127.0.0.1"
  port: 9876
  auth: "替换为 32 位以上随机密钥"
```

局域网访问示例（假设主机防火墙只允许管理网段）：

```yaml
http:
  enabled: true
  host: "0.0.0.0"
  port: 9876
  auth: "替换为 32 位以上随机密钥"
```

然后限制端口来源，例如使用 UFW：

```bash
sudo ufw allow from 192.168.1.0/24 to any port 9876 proto tcp
sudo ufw deny 9876/tcp
```

不要把默认的 `omni-watch-123456789` 暴露到不可信网络。密码、qBittorrent 凭据和插件令牌会出现在配置文件中，建议设置文件权限：

```bash
sudo chown root:root /etc/pico-monitor.conf
sudo chmod 600 /etc/pico-monitor.conf

## 命令行专用参数

以下开关不属于常驻 YAML 配置，写入 YAML 不会产生作用，应在执行一次性命令时直接使用：

| 参数 | 用途和示例 |
| --- | --- |
| `--config PATH` | 指定配置文件，例如 `sudo pico-monitor --config /tmp/test.conf --pico-info`。也可使用 `PICO_MONITOR_CONFIG` 或 `PICO_MONITOR_CONFIG_PATH` 指定路径。 |
| `--version` | 打印 Monitor 版本并退出。 |
| `--once` | 成功发送一次快照后退出，适合手动验证连接。 |
| `--pico-info` | 连接 Pico，显示板型、屏幕方案和固件版本后退出。 |
| `--upgrade-pico` | 下载并执行 Pico 固件升级。 |
| `--update` | 从 GitHub 最新 Release 下载并安装当前架构的 Linux DEB；与 `--pico-info`、`--upgrade-pico` 互斥。 |
| `--worker` | 供内部 HTTP/后台工作流程使用，普通用户不应手动设置。 |
| `--force-usb-cdc` / `--no-force-usb-cdc` | 临时覆盖 `network.force_usb_cdc`。 |
| `--adaptive-transmit` / `--no-adaptive-transmit` | 临时覆盖 `monitor.adaptive_transmit`。 |
| `--collection-task-intervals '{"network": 0.8}'` | 临时覆盖采集任务频率，值必须是 JSON 对象。 |
| `--http-enabled` / `--no-http` | 临时覆盖 HTTP 页面开关。 |

常用一次性检查：

```bash
# 检查版本和命令入口
pico-monitor --version

# 显示帮助；会先读取并解析指定 YAML
pico-monitor --config /etc/pico-monitor.conf --help

# 停止服务后，仅发送一次快照进行连接验证
sudo systemctl stop pico-monitor
sudo pico-monitor --config /etc/pico-monitor.conf --once
sudo systemctl start pico-monitor
```

## 环境变量完整对照

所有 `PICO_MONITOR_*` 环境变量都可以覆盖同名配置。下表列出变量、常用 YAML 路径和备注：

| 环境变量 | YAML 路径 | 备注 |
| --- | --- | --- |
| `PICO_MONITOR_PORT` | `serial.port` | 固定串口 |
| `PICO_MONITOR_SERIAL_PROBE_INTERVAL` | `serial.probe_interval` | USB 探测周期 |
| `PICO_MONITOR_WEBSOCKET_URL` | `network.websocket_url` | 固定 WebSocket |
| `PICO_MONITOR_FORCE_USB_CDC` | `network.force_usb_cdc` | `1/true/yes/on` 为真 |
| `PICO_MONITOR_WEBSOCKET_CLIENT_NAME` | `network.websocket_client_name` | 握手名称 |
| `PICO_MONITOR_WEBSOCKET_CLIENT_ID` | `network.websocket_client_id` | 稳定身份 |
| `PICO_MONITOR_WIFI_DISCOVERY_STRATEGY` | `network.discovery_strategy` | `announcement` 或 `scan` |
| `PICO_MONITOR_WIFI_ANNOUNCEMENT_PORT` | `network.announcement_port` | UDP 公告端口 |
| `PICO_MONITOR_WIFI_ANNOUNCEMENT_GROUP` | `network.announcement_group` | UDP 组播地址 |
| `PICO_MONITOR_WIFI_ANNOUNCEMENT_TIMEOUT` | `network.announcement_timeout` | 公告窗口 |
| `PICO_MONITOR_PING_TARGET` | `network.ping_target` | 延迟目标 |
| `PICO_MONITOR_NETWORK_UNIT` | `network.unit` | `MB` 或 `Mbps` |
| `PICO_MONITOR_LAN_PROBE_PORT` | `network.lan_probe_port` | 环境变量可用；当前版本未纳入嵌套 YAML 映射 |
| `PICO_MONITOR_LAN_PROBE_PATH` | `network.lan_probe_path` | 环境变量可用；当前版本未纳入嵌套 YAML 映射 |
| `PICO_MONITOR_LAN_PROBE_TIMEOUT` | `network.lan_probe_timeout` | 环境变量可用；当前版本未纳入嵌套 YAML 映射 |
| `PICO_MONITOR_LAN_PROBE_MAX_WORKERS` | `network.lan_probe_max_workers` | 环境变量可用；当前版本未纳入嵌套 YAML 映射 |
| `PICO_MONITOR_INTERVAL` | `monitor.interval` | 最小 0.3 秒 |
| `PICO_MONITOR_ADAPTIVE_TRANSMIT` | `monitor.adaptive_transmit` | 发送自适应 |
| `PICO_MONITOR_RECONNECT_INTERVAL` | `monitor.reconnect_interval` | 重连周期 |
| `PICO_MONITOR_DEV` | `monitor.dev` | 开发模式 |
| `PICO_MONITOR_COLLECTION_TASK_INTERVALS` | `collection_tasks.intervals` | JSON 对象 |
| `PICO_MONITOR_COLLECTION_TASK_LOGS` | `collection_tasks.logs_enabled` | 任务常规日志 |
| `PICO_MONITOR_CUSTOM_DATA_CONFIGS` | `custom_data.configs` | JSON 对象 |
| `PICO_MONITOR_CUSTOM_DATA_ENABLED` | `custom_data.enabled` | 环境变量可用；当前版本未纳入嵌套 YAML 映射 |
| `PICO_MONITOR_SCREEN_ROTATION` | `screen.rotation` | `0` 或 `180` |
| `PICO_MONITOR_LCD_BRIGHTNESS` | `screen.lcd_brightness` | 1 到 100 |
| `PICO_MONITOR_LCD_STYLE` | `screen.lcd_style` | 样式名 |
| `PICO_MONITOR_IDLE_ENABLED` | `screen.idle_enabled` | 待机功能开关 |
| `PICO_MONITOR_IDLE_STYLE` | `screen.idle_style` | 待机样式 |
| `PICO_MONITOR_IDLE_TIMEOUT` | `screen.idle_timeout` | 正整数秒 |
| `PICO_MONITOR_LOG_LEVEL` | `logging.level` | 日志级别 |
| `PICO_MONITOR_THREAD_DIAGNOSTICS` | `diagnostics.threads` | 线程诊断开关 |
| `PICO_MONITOR_THREAD_DIAGNOSTICS_INTERVAL` | `diagnostics.thread_interval` | 诊断周期 |
| `PICO_MONITOR_SENSOR_HOST_ENABLED` | `sensor_host.enabled` | 仅 Windows |
| `PICO_MONITOR_SENSOR_HOST_PATH` | `sensor_host.path` | 仅 Windows |
| `PICO_MONITOR_SENSOR_HOST_PIPE` | `sensor_host.pipe` | 仅 Windows |
| `PICO_MONITOR_QBITTORRENT_ENABLED` | `qbittorrent.enabled` | 启用 qBittorrent |
| `PICO_MONITOR_QBITTORRENT_ADDRESS` | `qbittorrent.address` | Web UI 地址 |
| `PICO_MONITOR_QBITTORRENT_USERNAME` | `qbittorrent.username` | 登录账号 |
| `PICO_MONITOR_QBITTORRENT_PASSWORD` | `qbittorrent.password` | 登录密码 |
| `PICO_MONITOR_QBITTORRENT_INTERVAL` | `qbittorrent.interval` | 采集周期 |
| `PICO_MONITOR_DISK_HEALTH_TEST_INDEX` | `disk_health_test.index` | 测试磁盘序号 |
| `PICO_MONITOR_DISK_HEALTH_TEST_LEVEL` | `disk_health_test.level` | 测试等级 |
| `PICO_MONITOR_UPGRADE_URL` | `upgrade.url` | 固件包地址 |
| `PICO_MONITOR_UPGRADE_SHA256` | `upgrade.sha256` | 固件包摘要 |
| `PICO_MONITOR_MARKET_URL` | `market.url` | 插件市场 |
| `PICO_MONITOR_HTTP_ENABLED` | `http.enabled` | HTTP 开关 |
| `PICO_MONITOR_HTTP_HOST` | `http.host` | 监听地址 |
| `PICO_MONITOR_HTTP_PORT` | `http.port` | 监听端口 |
| `PICO_MONITOR_HTTP_AUTH` | `http.auth` | 鉴权密钥 |

布尔环境变量识别 `1`、`true`、`yes`、`on`（不区分大小写）为真，其余字符串按假处理。对象环境变量必须是合法 JSON，例如：

```bash
sudo systemctl edit pico-monitor
```

```ini
[Service]
Environment="PICO_MONITOR_COLLECTION_TASK_INTERVALS={\"cpu_memory\":0.8,\"network\":1.5}"
Environment="PICO_MONITOR_CUSTOM_DATA_ENABLED={\"my_data\":true}"
```

## 旧版 EnvironmentFile 格式

旧版本曾使用每行一个 `PICO_MONITOR_*` 的环境变量文件。当前程序仍兼容这种文件：如果配置文件第一个有效内容行以 `PICO_MONITOR_` 开头，程序会按旧格式解析，而不是按 YAML 解析。

旧格式示例：

```text
# /etc/pico-monitor.conf（旧格式）
PICO_MONITOR_PORT="/dev/ttyACM1"
PICO_MONITOR_INTERVAL="1.0"
PICO_MONITOR_HTTP_ENABLED="true"
PICO_MONITOR_HTTP_AUTH="替换为随机长密钥"
PICO_MONITOR_COLLECTION_TASK_INTERVALS='{"disk_rate":2}'
```

新部署建议使用本文前面的 YAML 格式。迁移时逐项把环境变量移动到对应的 YAML 路径；对象值仍保持 JSON 字符串。

## systemd 服务和文件权限

DEB 服务的关键属性通常如下：

```ini
[Service]
ExecStart=/usr/bin/pico-monitor --config /etc/pico-monitor.conf
Restart=always
RestartSec=3
User=root
Environment=HOME=/var/lib/pico-monitor
Environment=PICO_MONITOR_DATA_ROOT=/var/lib/pico-monitor
Environment=PICO_MONITOR_SCREENSHOT_DIR=/var/lib/pico-monitor/screenshot
NoNewPrivileges=true
PrivateTmp=true
ProtectHome=true
ProtectSystem=strict
```

以 root 运行是为了直接读取系统级 i915 PMU、RAPL、SMART 和 USB 串口。若你已为运行账号配置 `dialout`、`video`、`render`、`adm` 等权限，可以复制服务并降低权限，但必须重新验证串口、GPU、功耗和 SMART 数据；不要直接修改包管理器管理的服务文件。

配置中的密码和令牌应限制为 root 可读：

```bash
sudo chown root:root /etc/pico-monitor.conf
sudo chmod 600 /etc/pico-monitor.conf
```

systemd drop-in 中的环境变量同样可能包含秘密信息，修改后请检查：

```bash
sudo systemctl cat pico-monitor
```

服务单元中还有三项路径环境变量，它们不是 YAML 配置项：

| 环境变量 | DEB 默认值 | 用途 |
| --- | --- | --- |
| `HOME` | `/var/lib/pico-monitor` | systemd 服务的运行主目录。 |
| `PICO_MONITOR_DATA_ROOT` | `/var/lib/pico-monitor` | 自定义插件、插件运行环境和导出数据的根目录。 |
| `PICO_MONITOR_SCREENSHOT_DIR` | `/var/lib/pico-monitor/screenshot` | Pico LCD 截图保存目录。 |

需要迁移数据目录时，应通过 systemd drop-in 同时修改这些变量并提前创建目录、设置 root 权限；不要把它们写入 `pico-monitor.conf`，因为 Monitor 配置解析器不会读取这些路径键。

另外几个高级环境变量也不属于 YAML：

| 环境变量 | 作用 |
| --- | --- |
| `PICO_MONITOR_ERROR_LOG_PATH` | 将 `ERROR` 及以上日志追加写入指定文件，例如 `/var/lib/pico-monitor/error.log`。目录必须先存在且服务用户可写；使用 `/var/log` 时还要在服务单元中增加对应的 `ReadWritePaths`。 |
| `PICO_MONITOR_PLUGIN_PYTHON` | 指定创建和运行插件虚拟环境的 Python 解释器路径。Linux 通常留空，使用服务自身的 `/usr/bin/python3`。 |
| `PICO_MONITOR_SETTINGS_PATH` | 覆盖样式目录等设置文件路径；主要用于开发或自定义部署。 |
| `PICO_MONITOR_PRESENTMON` | Windows FPS 采集使用的 PresentMon 路径，Linux 忽略。 |
| `PICO_MONITOR_ADLX_BRIDGE` | Windows AMD ADLX 回退桥接程序路径，Linux 忽略。 |

## 常见配置场景

### 1. 只使用 USB，完全关闭网络发现

```yaml
serial:
  port: "/dev/serial/by-id/usb-Pico-if01"
network:
  force_usb_cdc: true
http:
  enabled: false
```

适合没有局域网、只在本机使用 LCD 的场景。`serial.port` 应填写实际 PV1 数据接口。

### 2. 固定 Wi-Fi 地址，不扫描整个网段

```yaml
serial:
  port: ""
network:
  websocket_url: "ws://192.168.1.50:8765/pv1"
  force_usb_cdc: false
```

设备使用 DHCP 时地址可能变化；此时建议删除 `websocket_url`，使用 `announcement` 自动发现。

### 3. 无外网环境，用网关测延迟

```yaml
network:
  ping_target: "192.168.1.1"
  discovery_strategy: scan
```

如果交换机不转发组播，`scan` 比 `announcement` 更直接，但会产生局域网探测流量。

### 4. 低性能 NAS 降低采集开销

```yaml
monitor:
  interval: 2.0
collection_tasks:
  intervals:
    cpu_memory: 2
    disk_capacity_health: 300
    disk_temperature: 30
    disk_rate: 2
    network: 2
    power: 2
    gpu: 10
```

磁盘健康和温度的频率可以比 LCD 发送频率低很多；快照会继续发送最近一次有效值。

### 5. 开启 HTTP 管理页面但只允许本机访问

```yaml
http:
  enabled: true
  host: "127.0.0.1"
  port: 9876
  auth: "替换为随机长密钥"
```

访问 `http://127.0.0.1:9876/`。如果要从远程浏览器访问，建议通过 SSH 端口转发，而不是直接把 `9876` 暴露到公网：

```bash
ssh -L 9876:127.0.0.1:9876 user@linux-host
```

### 6. qBittorrent 与四盘样式

```yaml
screen:
  lcd_style: "horizontal_disk4x_qb"
qbittorrent:
  enabled: true
  address: "http://127.0.0.1:8080"
  username: "admin"
  password: "替换为实际密码"
  interval: 2.0
```

该样式会保留四盘布局，并使用 qBittorrent 仪表盘替换部分 IP/GPU 区域；没有 qBittorrent 服务时不要开启 `enabled`。

## 修改后的排错顺序

1. 先检查 YAML 缩进、引号和布尔值：

   ```bash
   sudo pico-monitor --config /etc/pico-monitor.conf --help >/dev/null
   ```

2. 查看 systemd 实际加载的命令和环境：

   ```bash
   sudo systemctl cat pico-monitor
   ```

3. 查看最近 100 行日志：

   ```bash
   sudo journalctl -u pico-monitor -n 100 --no-pager
   ```

4. 检查串口和权限：

   ```bash
   ls -l /dev/serial/by-id/ /dev/ttyACM* /dev/ttyUSB* 2>/dev/null
   id
   dmesg | tail -n 50
   ```

5. 检查 Linux 可选硬件工具：

   ```bash
   command -v smartctl || true
   ls /sys/class/powercap 2>/dev/null || true
   ls /sys/class/drm 2>/dev/null || true
   ```

6. 配置改动后确认服务没有被旧进程占用：

   ```bash
   sudo systemctl restart pico-monitor
   sudo systemctl is-active pico-monitor
   ```

常见错误与处理：

| 日志或现象 | 原因和处理 |
| --- | --- |
| `YAML 配置解析失败` | 缩进、冒号、引号或 JSON 字符串错误。用 `python3 -c 'import yaml; yaml.safe_load(open("/etc/pico-monitor.conf"))'` 定位语法。 |
| `采集间隔不得低于 0.3 秒` | `monitor.interval` 太小；改为 `0.3` 或更大。 |
| `开启 qBittorrent 采集后必须配置` | `qbittorrent.enabled=true` 时地址、账号、密码不能留空。 |
| 服务反复重启 | 查看 `journalctl -u pico-monitor -b`，重点检查配置类型、Python 依赖、串口权限和端口冲突。 |
| 找不到 Pico | 先确认 USB 线支持数据，查看 `dmesg`；不要把 REPL CDC 当成 PV1 数据 CDC。 |
| Wi-Fi 找不到设备 | 检查设备与主机是否同一网段、防火墙是否允许 TCP 8765/UDP 37856；组播不可用时将策略改为 `scan`。 |
| 磁盘温度或健康为未知 | 安装 `smartmontools`，确认服务有 root 权限，并检查 USB 硬盘盒是否透传 SMART。 |
| 功耗为 `null` | 只有支持 RAPL 的 Intel 平台通常能读取 Linux 实时功耗；其他平台属于正常情况。 |
| HTTP 页面打不开 | 确认 `http.enabled`、监听地址、端口和 Auth；`127.0.0.1` 只能从本机访问。 |

修改硬件驱动、内核参数或 udev 规则后，建议重新插拔设备并重启 `pico-monitor`，再通过 `journalctl` 确认出现 `PONG:PICO_LCD` 和正常快照发送日志。
```
```

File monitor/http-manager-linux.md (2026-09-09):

# Linux HTTP 管理页面

Pico Monitor 在 Linux 上默认启用无桌面的 HTTP 管理页面，适合服务器、迷你主机和 NAS 使用。默认监听地址为 `0.0.0.0:9876`，初始 Auth 为 `omni-watch-123456789`。

> 初始 Auth 是公开的默认值。首次登录后请立即在 `/etc/pico-monitor.conf` 中替换为高强度随机密钥，并重启服务。

## 当前支持范围

当前 Linux HTTP 后端支持：

- 查看和保存应用配置、设备连接状态、Wi-Fi 与 WebSocket 客户端策略；
- 通过设备主循环执行设备探测、截图、重启、样式目录管理和 Wi-Fi 操作；
- 在浏览器中上传 ZIP 插件、目录插件、PY/ZIP 样式、固件 ZIP 和 SDK 镜像；
- 在同源插件市场中安装数据插件和屏幕样式，并查询安装进度；
- 查询、清理日志和检查/安装 Linux 应用更新。

浏览器上传文件会暂存于 Monitor 生成的临时目录，默认 30 分钟后清理；HTTP action 不接受浏览器直接传入的服务器本地路径。日志导出和打开服务器目录仍属于桌面专属功能，页面会给出明确提示。设备 Wi-Fi 配置也可参阅 [`linux-wifi-config.md`](linux-wifi-config.md)。

插件市场地址可在“设置 → 插件市场”中修改，Linux 配置文件对应 `market.url`。市场下载地址必须与该配置同源，单个市场 ZIP 最大 20 MB。

## 默认配置

编辑 Linux 服务配置：

```sh
sudo nano /etc/pico-monitor.conf
```

默认安装生成的 `http` 配置如下：

```yaml
http:
  enabled: true
  host: 0.0.0.0
  port: 9876
  auth: "omni-watch-123456789"
```

插件市场配置位于同一文件的 `market` 节点：

```yaml
market:
  url: "https://omni.mzlblog.com"
```

各配置项含义：

| 配置项 | 说明 |
|---|---|
| `enabled` | 是否启用 HTTP 管理页面。 |
| `host` | 监听地址；`0.0.0.0` 允许局域网访问，`127.0.0.1` 仅允许本机访问。 |
| `port` | 首选监听端口，默认为 `9876`。 |
| `auth` | 浏览器和接口请求使用的鉴权密钥；初始值为 `omni-watch-123456789`。 |

可以使用 OpenSSL 生成随机 Auth：

```sh
openssl rand -base64 32
```

首次登录后，将输出内容复制到 `auth`，并保留 YAML 双引号，然后重启服务。不要把真实 Auth 提交到 Git 仓库、截图或公开日志中。

## 重启并检查服务

应用配置：

```sh
sudo systemctl restart pico-monitor
sudo systemctl status pico-monitor
```

查看启动日志：

```sh
sudo journalctl -u pico-monitor -n 50 --no-pager
```

正常情况下会看到类似日志：

```text
HTTP 管理页面已启动：http://0.0.0.0:9876，Auth=******
```

如果配置的端口已被占用，程序会从该端口开始自动寻找可用端口。请以启动日志中记录的实际端口为准。

当配置中的 `auth` 为空时，程序会在每次启动时生成新的随机 Auth，并将明文 Auth 写入启动日志。为保证地址稳定且减少密钥暴露，长期运行时建议显式配置 Auth。

## 浏览器访问

仅在 Linux 主机本机访问：

```text
http://127.0.0.1:9876/
```

从同一局域网的其他电脑访问：

```text
http://Linux主机IP:9876/
```

页面首次建立连接时会提示输入 Auth。首次安装可输入 `omni-watch-123456789`，登录后应立即更换该默认值。验证成功后，Auth 会保存在当前浏览器的本地存储中；修改 Auth 后，可清除该站点的浏览器存储并重新输入。

## 健康检查

健康检查接口不要求 Auth：

```sh
curl -fsS http://127.0.0.1:9876/api/health
```

正常响应：

```json
{"ok": true, "service": "omniwatch-http"}
```

查看页面运行参数：

```sh
curl -fsS http://127.0.0.1:9876/api/runtime
```

## HTTP 接口调用示例

管理页面主要通过 WebSocket 调用后端，同时也提供 `POST /api/invoke`。以下示例读取设备连接状态：

```sh
read -rsp "HTTP Auth: " OMNIWATCH_HTTP_AUTH; printf '\n'
curl -fsS \
  -H "Authorization: Bearer ${OMNIWATCH_HTTP_AUTH}" \
  -H "Content-Type: application/json" \
  -d '{"action":"device.status","payload":{}}' \
  http://127.0.0.1:9876/api/invoke
unset OMNIWATCH_HTTP_AUTH
```

读取应用首屏信息：

```sh
read -rsp "HTTP Auth: " OMNIWATCH_HTTP_AUTH; printf '\n'
curl -fsS \
  -H "Authorization: Bearer ${OMNIWATCH_HTTP_AUTH}" \
  -H "Content-Type: application/json" \
  -d '{"action":"app.bootstrap","payload":{}}' \
  http://127.0.0.1:9876/api/invoke
unset OMNIWATCH_HTTP_AUTH
```

使用 `read -s` 可以避免 Auth 显示在终端和 Shell 历史中。

## 配置防火墙

仅在确实需要局域网访问时开放端口，并尽量限制可信网段。

使用 UFW 的系统可以执行：

```sh
sudo ufw allow from 192.168.1.0/24 to any port 9876 proto tcp
```

使用 firewalld 的系统可以执行：

```sh
sudo firewall-cmd --permanent --zone=public --add-port=9876/tcp
sudo firewall-cmd --reload
```

firewalld 的端口规则会允许该区域内的来源访问。如果需要限制来源，请改用符合本机网络策略的 rich rule。

## 安全建议

- 只在本机管理时，将 `host` 设置为 `127.0.0.1`。
- 不要长期使用默认 Auth `omni-watch-123456789`。
- 局域网访问时使用高强度随机 Auth，并通过防火墙限制来源。
- HTTP 本身不加密，不要直接暴露到公网。
- 需要跨互联网管理时，应通过 VPN 或带 HTTPS 的反向代理访问。
- 不要在命令参数、Shell 历史、截图或工单中泄露 Auth。

## 常见问题

### 浏览器无法访问

检查监听地址和实际端口：

```sh
sudo journalctl -u pico-monitor -n 100 --no-pager
sudo ss -lntp | grep pico-monitor
```

如果 `host` 为 `127.0.0.1`，其他电脑无法直接访问，这是预期行为。

### 页面提示鉴权失败

确认输入的是 `/etc/pico-monitor.conf` 中的 `http.auth`；首次安装的默认值是 `omni-watch-123456789`。如果该值为空，请从本次服务启动日志中获取随机 Auth。修改配置后必须重启服务。

### 页面为空或静态资源返回 404

确认使用正式 DEB 或通用 Linux 发布包安装。源码运行时必须先构建 `monitor/win/ui-web/dist`，否则 HTTP 服务无法提供 Vue 页面。

### 端口不是 9876

端口被占用时，Pico Monitor 会自动选择后续可用端口。通过服务日志确认实际地址；若防火墙只开放了 `9876`，应先释放该端口再重启服务。

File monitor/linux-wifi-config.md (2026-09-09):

# Linux 命令行配置设备 Wi-Fi

本文说明如何在没有桌面环境的 Linux 主机上，通过 Pico Monitor 命令行控制通道为设备配置 Wi-Fi。

## Linux HTTP 管理页面说明

Linux 版本确实内置了 HTTP 管理页面，并在默认安装配置中启用。默认监听端口为 `9876`，初始 Auth 为 `omni-watch-123456789`。`/etc/pico-monitor.conf` 中的默认配置如下：

```yaml
http:
  enabled: true
  host: 0.0.0.0
  port: 9876
  auth: "omni-watch-123456789"
```

修改后重启服务：

```sh
sudo systemctl restart pico-monitor
sudo journalctl -u pico-monitor -n 50 --no-pager
```

然后使用浏览器访问 `http://Linux主机IP:9876/`，首次访问时输入 `omni-watch-123456789`。该初始 Auth 是公开默认值，首次登录后应立即替换为高强度随机密钥；如果 `auth` 留空，程序会在每次启动时随机生成 Auth，并将它写入启动日志。

当前版本的 Linux HTTP 后端已经开放 `wifi.list`、`wifi.connect` 和 `wifi.forget`。这些动作会排队交给 Monitor 主循环执行，避免 HTTP 线程与设备协议流并发读写；设备配网可以直接在浏览器页面完成，也可以继续使用本文后续的命令行控制方式。

> 将 `host` 配置为 `0.0.0.0` 会向局域网开放管理页面。请设置高强度 Auth，并通过主机防火墙限制访问来源；仅在本机使用时建议配置为 `127.0.0.1`。

## 使用条件

- 设备固件必须支持 Wi-Fi，例如启用了 Wi-Fi 的 ESP32-S3 固件。
- 首次配网必须通过 USB CDC 连接设备。
- Linux 主机已经安装 Pico Monitor，并能执行 `pico-monitor --version`。
- 当前账号具有 `sudo` 权限。

RP2040 本身不具备 Wi-Fi 功能。设备未在握手信息中声明支持 Wi-Fi 时，配网命令会失败。

## 1. 确认 USB 设备

连接设备后查看串口：

```sh
ls -l /dev/serial/by-id/ 2>/dev/null
ls -l /dev/ttyACM* /dev/ttyUSB* 2>/dev/null
```

通常无需固定串口，Pico Monitor 会通过 PV1 握手自动识别正确的 USB CDC 数据接口。如果自动识别失败，可在后续命令中添加 `--port /dev/ttyACM1`，并替换为实际设备路径。

## 2. 停止后台服务

systemd 服务可能正在占用串口。进入交互配网前先停止服务：

```sh
sudo systemctl stop pico-monitor
```

## 3. 启动命令行配网会话

执行：

```sh
sudo pico-monitor --config /etc/pico-monitor.conf --worker --force-usb-cdc
```

需要固定串口时执行：

```sh
sudo pico-monitor --config /etc/pico-monitor.conf --worker --force-usb-cdc --port /dev/ttyACM1
```

等待终端显示 `Pico LCD 已连接` 后，在同一终端中输入下面的控制命令。每条命令输入完成后按 Enter。

## 4. 扫描附近 Wi-Fi

输入：

```text
WIFI_LIST
```

成功时会输出一行以 `WIFI_RESULT:` 开头的 JSON，例如：

```text
WIFI_RESULT:{"status":"ok","action":"list","data":{"networks":[{"ssid":"Home-WiFi","rssi":-45,"security":"WPA2"}]}}
```

设备扫描无线网络可能需要数秒，请等待结果返回后再输入下一条命令。

## 5. 连接 Wi-Fi

输入以下命令，并替换 Wi-Fi 名称和密码：

```text
WIFI_CONNECT:{"ssid":"Home-WiFi","password":"your-password"}
```

连接开放网络时，密码使用空字符串：

```text
WIFI_CONNECT:{"ssid":"Guest-WiFi","password":""}
```

成功结果中的 `data` 会包含设备当前 Wi-Fi 状态和 IP 地址，例如：

```text
WIFI_RESULT:{"status":"ok","action":"connect","data":{"wifi":{"ssid":"Home-WiFi","ip":"192.168.1.50"}}}
```

请记录返回的 IP 地址。Wi-Fi 名称或密码包含双引号、反斜杠等特殊字符时，必须按照 JSON 字符串规则转义。

> 密码会显示在当前终端输入区域，但不会出现在 Shell 命令历史中，Monitor 的结果和日志也不会回显密码。请避免在录屏、共享终端或不可信会话中操作。

## 6. 忘记已保存的 Wi-Fi

需要删除设备中保存的网络时，在 USB 配网会话中输入：

```text
WIFI_FORGET:{"ssid":"Home-WiFi"}
```

成功时会输出：

```text
WIFI_RESULT:{"status":"ok","action":"forget","data":{"forgotten":"Home-WiFi"}}
```

## 7. 退出配网并启用 Wi-Fi 连接

配网成功后按 `Ctrl+C` 结束交互进程，然后编辑配置：

```sh
sudo nano /etc/pico-monitor.conf
```

如果希望固定连接刚才返回的设备 IP，在 `network` 节点中增加或修改：

```yaml
network:
  websocket_url: ws://192.168.1.50:8765/pv1
  force_usb_cdc: false
```

如果设备使用 DHCP，IP 地址可能变化。此时可将 `websocket_url` 留空，使用默认的 UDP 公告和局域网扫描自动发现：

```yaml
network:
  websocket_url: ""
  force_usb_cdc: false
  discovery_strategy: announcement
```

重新启动服务：

```sh
sudo systemctl start pico-monitor
sudo systemctl status pico-monitor
```

查看连接日志：

```sh
sudo journalctl -u pico-monitor -f
```

日志中出现 `WebSocket 连接` 和设备地址，表示 Wi-Fi 通信已经建立。设备仍通过同一根 USB 线连接主机时，USB 通信具有更高优先级；需要验证纯 Wi-Fi 模式时，应断开 USB 数据连接，并通过其他方式为设备供电。

## 常见问题

### 没有发现串口

确认设备和 USB 线支持数据传输，并检查内核日志：

```sh
sudo dmesg --follow
```

重新插入设备后，观察是否出现 `ttyACM` 或 `ttyUSB`。

### 返回 `Wi-Fi 名称不能为空` 或 JSON 错误

确认 `WIFI_CONNECT:` 或 `WIFI_FORGET:` 后面紧跟合法 JSON，属性名和字符串必须使用英文双引号。

### Wi-Fi 连接超时

确认 SSID、密码和信号强度正确。设备支持的频段取决于硬件；常见 ESP32-S3 设备只能连接 2.4 GHz Wi-Fi。

### 配网后服务仍使用 USB

USB 是优先传输方式。确认配置中的 `force_usb_cdc` 为 `false`，结束配网进程后断开 USB 数据连接，再启动 systemd 服务。

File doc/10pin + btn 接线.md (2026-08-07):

# LCD
- 1脚 --- 不接 
- 2脚 --- 3V3
- 3脚 --- GND
- 4脚 --- 3v3
- 5脚 --- GP14
- 6脚 --- GP11
- 7脚 --- GP12
- 8脚 --- GP10
- 9脚 --- GP9 
- 10脚 --- GND
- PWM --- GP13

# 按钮 
- GND --- GND
- K1 --- GP3
- K2 --- GP1
- K3 --- GP2

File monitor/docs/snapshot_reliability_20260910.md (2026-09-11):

# Snapshot 网络与 ESP32 性能验证（2026-09-10）

## 结论

完整事务可以超过 16KiB；限制仍保留在单条 PV1 负载和单条解压 JSON 上。事务发送器将每片 JSON 控制在 4096 字节以内，设备收齐后应用操作，不会把整个事务重新拼成一条大 JSON 再解析。

新增序列化事务预算：ESP32-S3 为 256KiB，RP2040 为 64KiB，通过 PONG 的 snapshot_chunks.max_bytes 协商。预算统计唯一分片的解压 JSON 字节，包含事务信封与操作；不是最终快照的体积上限，也不代表等量的堆内存。MicroPython 对象开销、旧快照、暂存操作和新快照会额外占用内存，内存不足时原子提交失败并释放暂存事务。

## 对比测量

Windows CPython、固定随机种子 17、每组构帧（包含压缩）7 次，表中为中位数。没有刷写连接的设备，没有测量 ESP32 原生 CPU、实际 Wi-Fi 丢包率或端到端延迟。压缩后线路字节随随机会话标识略有变化。

| 完整快照字节 | 分片数（前→后） | 操作数（前→后） | 线路字节（前→后） | 主机构帧 ms（前→后） |
|---:|---:|---:|---:|---:|
| 40950 | 20 → 12 | 453 → 14 | 18816 → 13440 | 47.988 → 20.096 |
| 164808 | 79 → 44 | 1803 → 46 | 75200 → 52864 | 192.836 → 88.116 |

## 已验证路径

- 40950 字节（RP2040）和 164808 字节（ESP32-S3）业务快照通过真实 PV1 校验、zlib 解压、JSON 解析和事务提交，内容完全一致；读取按 37 字节拆分，最终只产生一次匹配请求的 ACK。
- 单条解压后超过 16KiB 的 JSONZ 即使压缩很小仍被拒绝。
- 同次轮询的多个事务以及显示缓存使用完整替换，已删除插件字段不复活。
- 注入网络抖动、CPU 处理停顿、缺片和提交过慢，验证 400ms 预算失败、基线清理和下一批全量恢复。CPU/网络延迟由可控时钟模拟，不是物理网络仿真。
- WebSocket 半行读取超时保留已收片段；发送中断、超时关闭、发送锁争用、无换行大包均有覆盖。异常关闭立即释放 socket，避免 websocket-client 默认三秒关闭握手。
- 超出设备事务预算或提交 MemoryError 时，不发布半份快照。

## 优化内容

连续数组项共享一个 items 操作；分片装箱采用编码长度累计，避免反复编码整组操作；数组容量用指数探测减少大数组重复编码。设备全量根覆盖不再复制旧快照，按序迭代分片操作，长文本取消逐片补齐到完整长度的空格分配。WebSocket 发送整条 PV1 消息，不再经过 USB 511 字节分块。

## 实机验收入口

开启 display.dev 后，设备在最终 ACK 后输出 SNAPSHOT_TIMING，包含 PARTS、BYTES、APPLY 和 TRANSACTION。APPLY 是最终应用操作的板端耗时，TRANSACTION 是从第一片到提交的时间，包含接收间隔与处理时间；Monitor 的构帧到最终 ACK 耗时才是主机端整批预算。ACK 证明协议层提交，不代表屏幕已完成绘制。

建议分别采集冷启动全量、稳定增量、切换股票样式、Wi-Fi 弱信号和渲染繁忙时的 p50/p95/p99、超时率与 gc.mem_free()。400ms 是成功判定预算，不是对任意弱网、驱动阻塞和数据量的按时成功交付保证。

## 回归结果

本轮相关用例合计 158 项通过：snapshot 17、WebSocket 10、CDC 10、Monitor 115、ESP32 历史缓存 6。snapshot 用例额外包含两种固件 160 轮随机数据往返及 5 类网络/CPU 场景。CRC 损坏线路帧不会提交，后续全量事务可恢复。

在 Monitor 目录运行 `python -m unittest discover -s tests -p test_snapshot_transfer.py`、`test_websocket_transport.py`、`test_usb_cdc_framework.py` 和 `test_monitor.py`（分别替换 `-p` 参数）。ESP32 历史缓存用例位于 `../esp32-s3/tests/test_history_increase.py`。

## 2026-09-12 连接稳定性修正

取消 Monitor 整批快照的 400ms 硬截止时间。构帧和已完成分片不再消耗后续分片及最终 ACK 的等待窗口，按实际分片发送进度推进。单帧写入和最终 ACK 仍使用原有无响应保护；失败时清理基线，半帧失败仍重建连接。上文 400ms 成功判定仅记录旧版行为。

回归覆盖：真实 CDC 读写线程首帧阻塞 550ms 后成功确认；可控时钟下慢速构帧、慢速发送不触发整批超时；网络抖动、CPU 停顿和慢提交可完成，缺片或 ACK 失败仍恢复全量发送。

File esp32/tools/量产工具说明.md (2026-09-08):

# ESP32-S3 量产工具

双击同目录 `start_production.cmd` 打开中文 GUI，确认 SDK 和代码目录后点击 **开始量产**，随后插入 USB。也会处理启动时已连接的候选设备。多块设备依次处理。

界面显示单板流程进度条和状态灯：**红灯**表示正在处理设备（识别、写入、校验及复位期间请勿拔出）；**绿灯**表示写入、校验和复位全部完成，可拔出设备；确认拔出后转为**黄灯**，等待下一块。失败时显示黄灯及“本块失败 · 等待重试”，不显示绿灯；停止时显示灰灯，已完成结果则保留绿灯。

流程进度按阶段分配：识别 0–10%、SDK 写入 10–55%、重枚举 55–60%、代码同步 60–90%、校验 90–98%、最终复位 98%，成功后为 100%。已有兼容 SDK 时直接进入代码同步阶段。百分比表示流程推进，不代表剩余时间；只有校验和复位成功才显示 100%。

- 自动读取 `flash.sh` 最后一条 `esptool write_flash/write-flash` 命令的芯片、波特率、地址及镜像系列，不执行整个历史脚本。串口号由实际设备替换。
- 仅在 `flash.sh` 同目录、同硬件规格、同固件系列中按数字版本比较。当前选择 **N16R8 v1.0.69**，不会被官方 MicroPython v1.28.0 或 N8R8 系列混淆。新增同系列更高版本 bin 后，下一次开始量产自动选用。
- 已有 SDK 的判断来自真实 REPL：ESP32-S3 平台及 `fn_protocol` API v1 可用。已有兼容定制 SDK（包括旧版本）直接同步代码；不会强制升级。如果需要最新 SDK，需先让设备进入 ROM 下载模式再接入。
- 无可用 SDK 时，通过 esptool ROM 握手核对 ESP32-S3，确认 Flash 容量满足文件名规格，刷入 SDK，等待同一物理 USB 设备重新枚举，再部署代码。N16R8 固件用于 16 MB Flash / 8 MB 八线 PSRAM 板卡；工具不自动探测 PSRAM 接线规格，批次中请使用匹配板型。
- 复用 `pico-project/tools/mpremote_stream_copy.py`，默认代码库 `pico-project/esp32-s3`。同步完成后逐文件核对 SHA-256，确认设备身份并复位后计为成功。过滤规则与原同步器一致，默认增量同步，不删除设备中本地已移除的旧文件。
- 双 CDC 接口按 USB 物理位置归为同一设备。正常完成或失败后不会在本次连接中反复刷写；拔出至少 **3 秒**再接入才能重试。停止按钮等待当前设备完成后停止；重新开始会重新检查已连接设备。
- 日志自动保存在同目录 `production_logs`；失败显示在日志中，不计为成功。成功表示 SDK 可访问、代码内容一致且复位命令成功，不代表已完成屏幕、网络等整机功能测试。

请使用数据 USB 线，关闭占用串口的 Monitor、Thonny 等软件。支持发现 Espressif 原生 USB、CP210x、CH34x、FTDI；VID 仅筛选候选，不作为确认芯片的依据。没有自动下载电路的板卡，需按住 BOOT 插入 USB（必要时点按 RESET）。串口驱动必须正常安装。若 USB 模式切换后物理位置和序列号均无法保持，工具会报错停止，不会猜测其他设备的 COM 口。

启动脚本优先使用项目 `.venv`，否则使用 PATH 中的 `python`。需要 Python 3.10+（含 Tkinter）。缺少依赖时在项目根目录执行：

```powershell
.\.venv\Scripts\python.exe -m pip install -r .\esp32\tools\production_requirements.txt
```

测试命令（不访问或刷写真实设备）：

```powershell
.\.venv\Scripts\python.exe -m unittest discover -s .\esp32\tools\tests -v
```

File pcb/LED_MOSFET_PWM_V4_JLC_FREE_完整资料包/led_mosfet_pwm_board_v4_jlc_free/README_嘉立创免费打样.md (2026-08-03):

# LED MOSFET PWM 小板 V4——嘉立创免费打样兼容版

## PCB设计
- 单片尺寸：20.00 × 14.00 mm
- 2层 FR-4，板厚 1.60 mm；通孔焊盘在正反两面都有铜环
- 单板文件，不拼板，不含 V-CUT、邮票孔或工艺边
- 0805 电阻 + SOT-23 MOSFET，继续保留手焊间距
- 底层丝印预留 `JLCJLCJLCJLC`，用于指定嘉立创客编位置

## 推荐下单参数
- 板材：FR-4
- 层数：2层
- 数量：5片
- 板厚：1.6 mm
- 阻焊颜色：绿色
- 字符颜色：白色
- 铜厚：1 oz
- 表面处理：喷锡，选择你账户免费券支持的喷锡选项
- 出货方式：单片
- 拼板：否
- 阻抗：否
- 个性化选项：订单号/客编选择“指定位置”，对应底层 `JLCJLCJLCJLC`

## 用嘉立创EDA专用免费券
1. 在嘉立创EDA/EasyEDA中选择导入 KiCad。
2. 上传 `JLCEDA_Import_LED_MOSFET_PWM_V4_JLC_FREE.zip`。
3. 导入后检查焊盘网络、运行DRC，确认0错误。
4. 从嘉立创EDA内发起PCB下单，再选择账户中可用的免费券。

## 接线
- J1.1 PWM → Pico PWM GPIO
- J1.2 GND → Pico GND
- J2.1 LED- → 屏幕背光 LED-
- J2.2 GND → 背光电源/驱动器 GND
- Pico GND、屏幕/背光电源 GND 必须共地。
- LED+ 不经过此板，必须接符合屏幕规格的恒流/限流电源。

## 安全说明
本板只做MOSFET低边PWM开关，不提供LED恒流或限流。R1=100Ω是栅极串联电阻，R2=10kΩ是栅极下拉电阻。

## 下单前最终检查
- Gerber Viewer识别尺寸为20×14 mm；
- 只识别为单片板，不要开启拼板；
- Q1 1脚=G、2脚=S/GND、3脚=D/LED-；
- J1/J2钻孔为1.0 mm，间距2.54 mm；
- 底层客编位置不会压住焊盘。

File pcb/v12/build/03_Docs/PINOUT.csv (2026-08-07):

Pin | J1 FPC | J2 Breakout | Function / Note
1 | LEDK | LEDK | Backlight cathode / LED-; also connected to Q1 drain
2 | LEDA via R3=25R | LEDA | Backlight anode; FPC pin 2 is connected to J2 pin 2 through R3=25 ohm
3 | GND | GND | Logic/power ground; adjacent to LED- on the original board
4 | SDO | SDO | LCD serial data output / NC if unused
5 | SDA | SDA | SPI MOSI
6 | CS | CS | Chip select
7 | DC | DC | Data/command
8 | SCL | SCL | SPI clock
9 | RESET | RST | LCD reset
10 | VDD | VDD | LCD logic supply, nominal 3.3V
J3-1 | PWM |  | 3.3V logic PWM input through R1=100R
J3-2 | GND |  | PWM reference ground

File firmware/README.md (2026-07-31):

# 原生加速固件

`fn_canvas` 是可选的 MicroPython 用户 C 模块。业务代码通过
`canvas_backend.Canvas` 使用策略选择器：`canvasC.native_canvas_supported()` 会校验
模块版本和完整方法集合；匹配时选择 C 适配器，不匹配或不存在时选择未经修改的
`canvas.Canvas` Python/FrameBuffer 实现。

`fn_protocol` 是可选的 PV1 帧解析与 CRC 原生模块。`protocolC.py` 会校验
接口版本；匹配时使用 C 完成帧头、长度、填充及 CRC 校验，不匹配或不存在时自动
回退到原有 Python 解析器。JSON 仍由固件自带的 `ujson` 解析。

两套双语点阵字体已经作为 `fn_canvas` 只读数据编译进固件：

- `wqy_8x16`：文泉驿点阵正黑，ASCII 8×16、中文 16×16。
- `fusion_pixel_8x16`：Fusion Pixel 整数像素放大版，ASCII 8×16、中文 16×16。

字库覆盖 ASCII 和 GB2312，缺字回退为 `?`。标准 2 MiB Pico 无法同时容纳两套字库、
MicroPython 和项目文件系统，因此项目提供 `FN_VISION_RP2040_4M` 板配置。在
`micropython/ports/rp2` 目录构建四兆字节 RP2040 UF2：

```sh
make BOARD=FN_VISION_RP2040_4M \
  USER_C_MODULES=modules/micropython.cmake
```

生成文件位于 `micropython/ports/rp2/build-FN_VISION_RP2040_4M/firmware.uf2`。

设备侧可执行以下检查：

```python
from canvasC import native_canvas_supported
from canvas_backend import canvas_backend_name

print(native_canvas_supported(), canvas_backend_name())

from protocolC import native_protocol_supported
print(native_protocol_supported())
```

返回 `True` 表示当前 UF2 已启用且接口版本兼容；返回 `False` 表示会自动回退。

业务样式通过 `Canvas.draw_line_chart(definition, values)` 提交图表定义和原始数据。
当前定义支持位置、尺寸、固定或自动最大值、折线颜色、实心填充、数值颜色区间以及
点阵背景；C 策略负责全部坐标计算，Python 策略仅用于旧固件兼容回退。

```python
canvas.draw_line_chart({
    "x": 8, "y": 20, "width": 90, "height": 35,
    "maximum": 100, "color": 0xFFFF, "filled": True,
    "regions": ((50, 0x6607), (80, 0xE507), (101, 0xF36D)),
    "grid_step_x": 12, "grid_step_y": 7, "grid_color": 0x4208,
}, history_values)
```

`maximum` 设为 `0` 时由后端根据数据自动缩放；`regions` 按上限升序定义，每项为
`(上限, RGB565颜色)`。关闭实心或点阵时分别设置 `filled=False` 或将点阵步距设为 `0`。

无法用固定阈值表达颜色规则时，可设置 `color_callback`。回调接收当前插值数值并返回
RGB565 颜色；`color_cache_step` 控制 C 端哈希缓存粒度，默认为 `1`，同一整数区间只
调用一次 Python。设为 `0` 会关闭缓存并逐列回调，通常仅用于必须精确到小数的场景。

```python
def history_color(value):
    """根据业务规则返回历史图当前数值对应的颜色。"""
    return 0xF800 if value >= 90 else 0x07E0

definition["color_callback"] = history_color
definition["color_cache_step"] = 1
canvas.draw_line_chart(definition, history_values)
```

通用抗锯齿渐变圆环通过 `Canvas.draw_ring(option)` 调用。配置结构参考 ECharts，
`radius` 使用 `(内半径, 外半径)`，角度以屏幕右侧为 `0°`、顺时针增加，`-90°`
表示从顶部开始。API 9 固件会在 C 层完成逐像素 `sqrtf/atan2f`、边缘覆盖率、
RGB565 三色渐变和圆角端帽计算；旧固件返回 `False`，调用方可以选择兼容画法。

```python
drawn = canvas.draw_ring({
    "center": (93, 116),
    "radius": (66, 76),
    "value": 45,
    "min": 0,
    "max": 100,
    "startAngle": -90,
    "backgroundColor": 0x2104,
    "palette": (0x07E0, 0x05FC, 0x001F),
    "roundCap": True,
})
```

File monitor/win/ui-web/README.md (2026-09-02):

# OmniWatch Windows Web UI

此目录是 Windows 托盘程序的完整 Web 界面源代码，技术栈为 Vue 3、Element Plus 与 Vite。

前端不启动开发服务器，也不访问 REST API。所有桌面能力统一调用：

```js
window.pywebview.api.invoke(action, payload)
```

Python 兼容入口位于相邻的 `win/ui_web.py`，按职责拆分后的桥接实现位于
`win/ui-web-api`。生产构建使用相对资源路径，可被 PyInstaller 单文件程序从
临时解包目录通过 `file://` 直接加载。

## 本地开发

```powershell
npm ci
npm run dev
```

Vite 开发页会加载 HTTP 兼容桥接；联调业务动作时需把 `/ws` 代理到已启用的
Monitor HTTP 管理服务。

## HTTP 管理页面

同一份生产构建可以由内置 HTTP 服务提供。普通浏览器加载页面时，
`httpBridge.js` 会使用 `reconnecting-websocket` 创建具备退避重连能力的
兼容 `window.pywebview.api.invoke`，并通过 `/ws?auth=...` 代理原 action
协议，因此业务 Vue 组件不区分桌面和 HTTP 传输。服务端使用 `aiohttp`
承载静态页面、HTTP 接口和 WebSocket Upgrade。

Windows 可在“设置 → HTTP 管理页面”中配置启停、端口和 Auth，默认端口为
`9876`，首次运行会生成随机 Auth。Linux 通过 `pico-monitor.conf` 的 `http`
节点配置，默认启用，初始 Auth 为 `omni-watch-123456789`；部署后应立即更换
该公开默认值。浏览器首次访问会要求输入 Auth，并保存到当前浏览器的
`localStorage`。

如果配置端口被占用、被 Windows 排除或没有监听权限，服务会从该端口开始
向后寻找可监听端口。Windows 会把实际端口回写设置并通过托盘通知；Linux
保持配置文件不变，并在启动日志中输出实际端口。

额外的 `POST /api/invoke` 接口使用 `Authorization: Bearer <Auth>` 鉴权；
健康检查地址为 `GET /api/health`。原生文件选择、打开服务器本地目录等桌面
专属动作会在 HTTP 代理层返回不支持，不会进入原业务桥接。

## 插件市场

“插件市场”菜单通过 iframe 加载市场页面，并自动附加
`embed=1&theme=dark`。Monitor 版本为 `development` 时使用
`http://localhost/market`；正式版本使用控制中心“设置 → 插件市场”中保存的地址。

## 生产构建

```powershell
npm ci
npm run build
```

仓库根目录的 Windows GitHub Actions 工作流和 `monitor/build-exe.bat` 会先执行上述
构建，再把 `dist` 目录加入 PyInstaller 数据文件。

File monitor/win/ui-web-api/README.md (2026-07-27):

# Web 界面 Python API

本目录承载 `ui_web.py` 拆分后的 Python 实现。`win.ui_web` 继续作为稳定兼容
入口，托盘程序和已有测试无需修改导入路径。

- `bridge.py`：统一动作路由和桥接状态初始化。
- `settings_api.py`：首屏数据、设置保存和 qBittorrent 验证。
- `update_api.py`：应用、固件和 SDK 在线更新。
- `device_api.py`：设备控制、探测和 SDK 刷写。
- `network_api.py`：Wi-Fi 和 WebSocket 客户端管理。
- `style_api.py`：屏幕样式管理。
- `custom_data_api.py`：自定义数据插件管理。
- `log_api.py`：日志和数据目录操作。
- `common.py`：队列、对话框和响应公共能力。
- `webview.py`：pywebview 窗口生命周期和页面导航。
- `config.py`：桥接层稳定配置常量。

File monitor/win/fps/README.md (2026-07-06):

# Windows FPS 采集

主后端使用 PresentMon 的 ETW 事件，AMD ADLX 是可选回退。采集器只统计前台进程最活跃的 SwapChain，不写 CSV、不采集 GPU 时序和输入延迟。

## 部署 PresentMon

仓库已包含官方 PresentMon 2.4.1 64 位控制台程序（SHA-256：`D74183E7AE630F72CD3690BE0373ECBFDC6CBB86578148AAB8FA2A7166068F34`）。也可以通过环境变量 `PICO_MONITOR_PRESENTMON` 指定其他版本，或把它加入 `PATH`。未安装时 JSON 中 `fps.source` 为 `unavailable`，不会影响其他指标。

PresentMon ETW 会持续接收帧事件；JSON 和 history 每秒更新一次。部分 Windows 账户需要管理员权限或加入 `Performance Log Users` 用户组才能启动 ETW 会话。

## 可选 AMD ADLX

Python 端使用稳定的三函数 C ABI，桥接库应导出：

```c
int adlx_fps_initialize(void);
int adlx_fps_current(int* fps);
void adlx_fps_shutdown(void);
```

仓库的 `bridge/adlx_fps_bridge.cpp` 已实现该接口。安装 Visual Studio C++ 和 CMake 后，在 `bridge` 目录执行：

```text
cmake -S . -B build -A x64 -DADLX_SDK_ROOT=D:/SDK/ADLX/SDK
cmake --build build --config Release
```

产物会进入 `monitor/win/fps/bin`，也可以通过 `PICO_MONITOR_ADLX_BRIDGE` 指定其他位置。桥接库及 ADLX 运行库必须按照 AMD ADLX SDK 的许可要求分发。

## JSON

```json
"fps": {
  "value": 60.0,
  "history": [0, 0, 59.0, 60.0],
  "source": "presentmon_etw",
  "process_id": 1234,
  "process_name": "game.exe"
}
```

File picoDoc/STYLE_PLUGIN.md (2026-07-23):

# LCD 样式插件说明

LCD 渲染由 `dashboard.py` 统一调度，具体布局由 `styles/style_<名称>.py` 插件负责。
默认样式由 `config.py` 中的 `LCD_STYLE` 选择，monitor 也可以在线切换样式。

## 新增样式

1. 在 `styles` 目录创建 `style_<名称>.py`。名称只能包含小写字母、数字和下划线。
2. 样式类必须提供 `create_dirty_regions()`、`draw_visible()` 和 `draw_dirty()`。
3. 模块末尾调用 `register_style("<名称>", 工厂函数)` 完成注册。
4. 将名称加入 monitor 的 `BUILTIN_LCD_STYLES`，随后可通过
   `--lcd-style <名称>` 或 `PICO_MONITOR_LCD_STYLE=<名称>` 在线切换。
5. 横屏样式声明 `width = 320`、`height = 240` 和 `landscape = True`。
6. 样式的 `font_name` 定义该样式自己的默认字体。可选择 `native`、
   `screen_2inch`、`screen_2inch_compact`、`wqy_8x16` 或
   `fusion_pixel_8x16`。其中两个 8×16 字体来自已编译双语字模的 MicroPython 固件。
7. ESP32-S3 样式可声明 `sync_visible_frame_to_second = True`，让当前样式的
   最新待显示帧由 `fn_lcd` 原生异步任务在下一整秒按脏区自动提交。新帧只覆盖
   尚未显示的旧待显示帧，不会阻塞 Python 渲染线程。FPS、游戏等高帧率样式应
   设为 `False`；未声明的旧自定义样式默认关闭。

`create_dirty_regions()` 返回 `(key, x, y, width, height)` 列表。首次显示由
`draw_visible(canvas, snapshot)` 按条带完整绘制；后续刷新由
`draw_dirty(canvas, key, snapshot)` 只更新动态区域。

## 性能设计原则

性能日志格式如下：

```text
ACK:LCD_FRAME:<version>:TOTAL=...MS:CANVAS=...US:LCD=...US:REGIONS=...:MEMORY_USED=...:MEMORY_TOTAL=...:CANVAS_BACKEND=...:PROTOCOL_BACKEND=...:LCD_BACKEND=...
```

- `CANVAS` 包含样式计算、文字、曲线和 Canvas 绘制时间。
- `CANVAS_BACKEND` 为 `C` 时表示使用 UF2 原生加速，为 `PYTHON` 时表示使用兼容回退实现。
- `PROTOCOL_BACKEND` 为 `C` 时表示 PV1 帧使用 UF2 原生解析器，为 `PYTHON` 时表示使用 Python 回退解析器。
- `LCD_BACKEND` 为 `NATIVE_DMA` 时表示使用内部 DMA 双缓冲，为 `LEGACY` 时表示使用标准 SPI 兼容路径。
- `LCD` 是将脏区域写入屏幕的时间。
- `REGIONS` 只是区域数量。区域更多但总像素更少，通常仍可能更快。
- 优化时同时观察 `TOTAL`、`CANVAS`、`LCD` 和 `MEMORY_USED`，不要只看单项。

### 静态层与动态层分离

首帧负责绘制外框、标题、分隔线和固定标签。后续帧不要为了更新一个数值而清空、
重画整个面板。

推荐将面板拆成独立动态区域，例如：

```python
@staticmethod
def create_dirty_regions():
    return [
        ("cpu_values", 8, 10, 92, 16),
        ("cpu_history", 8, 31, 88, 35),
        ("network_upload_value", 32, 143, 64, 7),
        ("network_upload_history", 8, 152, 88, 19),
    ]
```

`draw_dirty()` 开始时渲染器会清空当前脏矩形，因此矩形必须覆盖旧内容的最大范围，
而不只是新文字的实际宽度。这样文字变短、曲线下降或状态消失时不会留下旧像素。

如果动态矩形穿过固定标签或分隔线，`draw_dirty()` 必须重新绘制被清除的那一部分；
更好的做法是调整矩形边界，使其避开静态元素。

外框颜色随健康等级、连接状态或告警相位变化时，外框属于动态内容，不能静态化。
磁盘健康闪烁和连接状态面板通常需要保留完整区域刷新。

### 按字段选择脏区域

不要只比较整个 `cpu`、`network` 或 `disk` 字典。历史数组变化不应触发数值区域刷新，
单个速率变化也不应重画另一条曲线。

```python
if previous_cpu.get("history") != current_cpu.get("history"):
    selected.append(region_map["cpu_history"])

if previous_network.get("upload_bps") != current_network.get("upload_bps"):
    selected.append(region_map["network_upload_value"])
```

实现 `select_dirty_regions(previous, current)` 时应遵循：

- 相同数据返回空列表。
- 数值、历史、状态和容量分别比较。
- 显示单位变化时，同时刷新依赖该单位的区域。
- 告警闪烁即使数据未变化，也要刷新对应动态区域。
- `force=True` 会使用 `create_dirty_regions()`，所以列表必须包含所有动态内容。

## Canvas 高效接口

优先使用 Canvas 已封装的原生 `framebuf` 操作：

- 大块背景使用 `clear()` 或 `fill_rect()`。
- 水平、垂直线仍调用 `canvas.line()`；Canvas 会自动选择原生 `hline()`/`vline()`。
- 同色面积图使用 `fill_polygon()`。
- 按采样值着色的历史图使用 `draw_columns()`，不要在 style 中逐列调用 `line()`。
- 文字统一使用 `canvas.text()`，不要自行创建 RGB565 字符位图。

单次文字可以通过 `font_name` 临时选择 SDK 已编译的字体，宽度计算必须
传入相同名称；省略参数时继续使用当前样式设置的字体，样式未设置时默认为 `native`。
单次调用结束后会自动恢复样式字体，不会影响后续文字：

```python
canvas.text(8, 20, "系统正常", WHITE, font_name="wqy_8x16")
width = canvas.text_width("系统正常", font_name="wqy_8x16")
canvas.text(8, 40, "Fusion Pixel", WHITE, font_name="fusion_pixel_8x16")
```

Canvas 的自定义字体使用 1-bit MONO 字形和 RGB565 palette。字形可以跨颜色复用，
固定字符串会在受限预算内缓存；包含数字的动态字符串不会进入整字符串缓存，以避免
持续分配和堆碎片。

不要在 style 中建立大尺寸 RGB565 静态背景缓存。RP2040 堆空间有限，一张
`320 × 40` RGB565 条带就需要 25,600 字节，容易引发连续内存分配失败。

## 历史图规则

历史图通常是 `CANVAS` 的主要热点：

- 优先把同色连续采样合并为一个原生多边形。
- 必须逐值着色时，将 `(x, y, color)` 交给 `canvas.draw_columns()`。
- 避免在双层 Python 循环中调用 `pixel()` 或逐像素 `fill_rect()`。
- 坐标计算优先使用整数和定点运算，避免 RP2040 上大量浮点除法。
- 限制采样数量到实际显示宽度；多个样本映射到同一列时应先聚合。
- 无数据或只有一个样本时尽早返回。

## 内存与分配约束

MicroPython 的可用总内存不等于最大连续可分配内存。即使日志仍显示数十 KB 空闲，
堆碎片也可能导致小块分配出现 `MemoryError`。

绘图热路径中应避免：

- 每帧创建大 `bytearray`、RGB565 FrameBuffer 或完整背景图。
- 对历史数组反复切片。
- 无上限的字符串、字形或颜色缓存。
- 缓存满后持续淘汰和重建动态内容。
- 为每一列创建元组、列表和临时多边形。

能复用的数组和缓冲区应在 Canvas 或样式初始化阶段创建。缓存必须有明确的项数或字节
上限，切换样式时应能够释放。

## 优化与验收流程

1. 先记录至少 20 个稳定帧的 `TOTAL/CANVAS/LCD/MEMORY_USED`。
2. 给疑似热点的 `_draw_*`、文字或历史图增加临时微秒计时。
3. 优先减少绘制工作和脏矩形面积，再考虑底层原生代码或 DMA。
4. 分别测试首帧、常规增量帧、强制刷新、样式切换和旋转后的完整重绘。
5. 连续运行数分钟，确认 `MEMORY_USED` 稳定且没有 `MemoryError`。
6. 验证文字由长变短、历史值由高变低、告警闪烁和状态颜色切换没有残影。

DMA 只能隐藏 LCD 传输时间，不能减少 `CANVAS`。当 `CANVAS` 仍明显大于 `LCD` 时，
优先优化样式算法和脏矩形；只有 LCD 已成为主要占比时，双缓冲 DMA 才通常值得引入。

## 测试要求

新增或修改样式至少应覆盖：

- `select_dirty_regions()` 只返回实际变化的 key。
- 历史变化不会刷新无关数值区域。
- 单方向网络变化不会刷新另一方向。
- 健康告警在数据不变时仍按帧刷新。
- 强制刷新包含所有动态区域。
- 字体缓存、历史图颜色和动态区域边界相关回归测试。

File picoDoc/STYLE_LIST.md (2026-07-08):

# LCD 样式列表

本文档简述系统内置 LCD 样式。Monitor 可通过命令行参数选择样式：

```powershell
python pico_monitor.py --lcd-style simple
```

也可以设置环境变量 `PICO_MONITOR_LCD_STYLE`。Pico 未连接 Monitor 时，使用
`config.py` 中的 `LCD_STYLE` 默认值。

## 样式总览

| 选择名称 | 源文件 | 方向与分辨率 | 字体 | 主要用途 |
| --- | --- | --- | --- | --- |
| `default` | `styles/style_default.py` | 竖屏 240×320 | 原生字体 | 通用系统概览 |
| `disk` | `styles/style_disk.py` | 竖屏 240×320 | 原生字体 | 突出磁盘总容量和网络趋势 |
| `diskv2` | `styles/style_diskv2.py` | 横屏 320×240 | 紧凑字体 | 高密度显示最多十五块磁盘 |
| `diskv3` | `styles/style_diskv3.py` | 横屏 320×240 | 紧凑字体 | 顶部显示 IP 的十五磁盘视图 |
| `diskv4` | `styles/style_diskv4.py` | 横屏 320×240 | 紧凑字体 | 实心趋势与空磁盘占位视图 |
| `horizontal_disk` | `styles/style_horizontal_disk.py` | 横屏 320×240 | 二寸屏字体 | 高密度显示最多九块磁盘 |
| `horizontal_diskv2` | `styles/style_horizontal_diskv2.py` | 横屏 320×240 | 紧凑字体 | 原九磁盘布局的紧凑字体版本 |
| `horizontal_disk4x` | `styles/style_horizontal_disk4x.py` | 横屏 320×240 | 紧凑字体 | 清晰显示最多四块磁盘 |
| `horizontal_disk4x_qb` | `styles/style_horizontal_disk4x_qb.py` | 横屏 320×240 | 紧凑字体 | 四磁盘与 qBittorrent 状态 |
| `horizontal_disk6x` | `styles/style_horizontal_disk6x.py` | 横屏 320×240 | 紧凑字体 | 均衡显示最多六块磁盘 |
| `simple` | `styles/style_simple.py` | 横屏 320×240 | 紧凑字体 | 健康优先的三磁盘简洁视图 |
| `fps_simple` | `styles/style_fps_simple.py` | 横屏 320×240 | 紧凑字体 | 深色简约 FPS 实时监控与趋势统计 |

## default

项目的基础竖屏仪表盘，依次显示 CPU、内存、磁盘、网络和底部状态信息。
CPU、内存和磁盘均提供当前值、详细数值及历史趋势，适合需要完整系统概览且
不强调单块物理磁盘的场景。

## disk

以磁盘总容量和总体占用率为视觉重点，同时显示 CPU、内存、上下行网络速率、
历史趋势、时间和运行时长。布局比 `default` 更突出存储使用情况，适合竖屏设备。

## diskv2

横屏三列五行高密度磁盘仪表盘，最多显示十五块物理磁盘。顶部显示主机、系统、
时间和运行时长，左侧集中显示 CPU、内存、网络、延迟及 GPU，右侧显示磁盘总体
容量、总体占用率和物理磁盘卡片。样式使用紧凑字体，并对容量单位进行合并显示，
适合磁盘数量较多且需要在单屏快速浏览状态的存储服务器。

每块磁盘的 SMART 健康状态与空间占用率独立显示：占用率仅控制百分比和进度条颜色，
`UNKNOWN`、`HEALTHY`、`NOTICE`、`WARNING`、`CRITICAL`、`FAILED` 状态由 `health`
等级决定；达到警告等级时，磁盘边框和状态信息会按照等级变色或逐帧闪烁。

## diskv3

沿用 `diskv2` 的十五磁盘高密度布局，并将顶部左侧的主机名和系统类型替换为当前
网络 IP 地址。适合通过屏幕直接确认设备网络地址的无键盘服务器和存储设备。

## diskv4

沿用 `diskv3` 的十五磁盘高密度布局，将 CPU 和 GPU 历史折线改为实心面积图；
不足十五块磁盘时，剩余槽位绘制低对比度的 `EMPTY` 占位卡，使网格结构保持完整。

## horizontal_disk

横屏高密度磁盘仪表盘。左侧显示 CPU、内存和网络，右侧显示磁盘总览及三行三列
的物理磁盘卡片，最多显示九块磁盘。磁盘卡片包含容量、占用率、温度和健康告警，
适合磁盘数量较多的主机。

## horizontal_diskv2

完整继承 `horizontal_disk` 的横屏布局、九磁盘上限、增量刷新和健康告警规则，
仅将二寸屏字体替换为紧凑字体。适合希望保留原有信息结构，同时减少文字占用空间
并提高卡片留白的场景。

## horizontal_disk4x

横屏双列磁盘仪表盘，最多显示四块物理磁盘。相比九磁盘样式，单块磁盘拥有更大
的显示空间，可展示容量、占用率、温度、读写速率和健康状态；剩余区域用于网络、
GPU 等扩展信息。

## horizontal_disk4x_qb

在 `horizontal_disk4x` 布局基础上加入 qBittorrent 面板。最多显示四块物理磁盘，
并展示 qBittorrent 在线状态、上传下载速度及相关统计。适合同时承担下载任务的
NAS 或家庭服务器。

## horizontal_disk6x

横屏双列三行布局，最多显示六块物理磁盘。信息密度介于四磁盘和九磁盘样式之间，
磁盘卡片包含容量、占用率、温度、实时读写速率和健康告警，适合中等磁盘数量的主机。

## simple

横屏简洁样式，最多显示三块物理磁盘，并按照 `health` 从差到好优先展示。左侧显示
CPU、内存、GPU、网络及网络延迟，右侧显示磁盘总览和磁盘读写信息。CPU、内存、GPU、
网络及磁盘读写历史使用低开销实心渐变面积图。磁盘卡片显示占用率、已用/总容量、
H0 至 H5 健康等级、温度和实时读写速率，适合优先观察异常磁盘及快速刷新。

## fps_simple

参考深色青紫仪表盘设计，顶部显示 FPS 标题和当前时间，主区域显示当前帧率与最近
二十四个采样点的趋势，底部集中展示平均值、最低值、最高值、FPS 抖动、
采集来源和前台进程。无可用采集源时会明确显示 `N/A` 与不可用状态。

## 健康等级

物理磁盘健康值含义如下：

| 等级 | 含义 |
| --- | --- |
| `H0` | 未知 |
| `H1` | 健康 |
| `H2` | 注意 |
| `H3` | 警告 |
| `H4` | 严重 |
| `H5` | 失败 |

横屏磁盘样式会使用状态色显示健康告警；达到较高告警等级时，会通过变色或闪烁增强提示。

## 新增样式

新增样式时在 `styles` 文件夹内使用 `style_<名称>.py` 命名，并在模块末尾调用 `register_style()` 注册。
完整插件接口和脏区域刷新约定请参阅 `STYLE_PLUGIN.md`。若样式需要由 Monitor 命令行选择，
还需将选择名称加入 `monitor/monitor_core/style_commands.py` 的 `BUILTIN_LCD_STYLES`。

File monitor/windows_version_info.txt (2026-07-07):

# Windows 可执行文件版本资源，用于任务管理器和文件属性展示应用身份。
VSVersionInfo(
    ffi=FixedFileInfo(
        filevers=(1, 0, 0, 0),
        prodvers=(1, 0, 0, 0),
        mask=0x3F,
        flags=0x0,
        OS=0x40004,
        fileType=0x1,
        subtype=0x0,
        date=(0, 0),
    ),
    kids=[
        StringFileInfo([
            StringTable(
                "080404B0",
                [
                    StringStruct("CompanyName", "OmniWatch"),
                    StringStruct("FileDescription", "OmniWatch"),
                    StringStruct("FileVersion", "1.0.0.0"),
                    StringStruct("InternalName", "OmniWatch"),
                    StringStruct("LegalCopyright", "Copyright (c) 2026 xuehui_li"),
                    StringStruct("OriginalFilename", "pico-monitor.exe"),
                    StringStruct("ProductName", "OmniWatch"),
                    StringStruct("ProductVersion", "1.0.0.0"),
                ],
            )
        ]),
        VarFileInfo([VarStruct("Translation", [2052, 1200])]),
    ],
)

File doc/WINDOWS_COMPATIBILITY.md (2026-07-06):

# Pico Vision Windows 兼容性说明

## 1. 适用范围

本文说明 Pico Vision 在 Windows 环境下的系统兼容范围，重点描述基于 PresentMon/ETW 的 FPS 采集能力。其他硬件监控功能的实际可用性还会受到设备型号、驱动程序和系统权限影响。

## 2. Windows 系统兼容范围

| Windows 系统 | CPU 架构 | 兼容级别 | 说明 |
| --- | --- | --- | --- |
| Windows 11 | x64 | 正式支持 | 推荐使用仍处于 Microsoft 支持周期内的版本 |
| Windows 10 | x64 | 正式支持 | 推荐使用 Windows 10 22H2 或受支持的 LTSC 版本 |
| Windows 11 | ARM64 | 未验证 | 内置 PresentMon 为 x64 程序，可能依赖 Windows x64 模拟层，不作为正式支持环境 |
| Windows 8.1、Windows 8 | x64/x86 | 不支持 | 当前项目及内置 PresentMon 2.4.1 未纳入兼容性验证 |
| Windows 7 | x64/x86 | 不支持 | 即使旧版 PresentMon 可能运行，也不代表当前项目能够稳定工作 |
| 32 位 Windows | x86 | 不支持 | 项目内置的 PresentMon 和发布目标均为 64 位 |

项目对外可声明的系统兼容范围为：**Windows 10 64 位和 Windows 11 64 位**。

## 3. FPS 采集兼容性

Pico Vision 默认使用 `PresentMonBackend`，通过 Windows ETW（Event Tracing for Windows）接收帧呈现事件。项目内置官方 PresentMon 2.4.1 64 位控制台程序。

支持的主要图形接口如下：

- DirectX 9；
- DirectX 11；
- DirectX 12；
- OpenGL；
- Vulkan。

PresentMon 不限定 Intel 显卡，可用于 Intel、AMD 和 NVIDIA 显卡。FPS 是否能够正常产生，还取决于目标程序是否提交可被 ETW 捕获的帧呈现事件。

当前实现仅统计前台程序及其关联进程中最活跃的 SwapChain，用于生成约一秒窗口的 FPS 数据。当前实现不采集 GPU 时序、输入延迟，也不写入 PresentMon CSV 文件。

## 4. 运行权限

PresentMon 启动 ETW 会话时，运行 Pico Vision 的账户应满足以下任一条件：

- 使用管理员权限运行；
- 属于 Windows 的 `Performance Log Users`（性能日志用户）组。

权限不足时，PresentMon 可能因 `Access Denied` 无法创建 ETW 会话，FPS 字段将不可用，但不应影响项目中的其他监控指标。

修改用户组后通常需要注销并重新登录，权限才会生效。

## 5. AMD ADLX 回退能力

AMD ADLX 不是 Windows 系统自带组件。项目中的 `AdlxBackend` 是可选回退方案，需要额外部署 `adlx_fps_bridge.dll` 及其依赖的 AMD ADLX 运行环境。

未部署 ADLX 桥接库时出现“未找到 ADLX FPS 桥接库”警告属于预期行为。只要 `PresentMonBackend` 已正常启动并收到帧事件，FPS 采集仍可使用。

ADLX 方案仅适用于兼容的 AMD 显卡和驱动环境，不能替代 PresentMon 作为跨显卡厂商的通用方案。

## 6. 已知限制

- 无管理员权限或性能日志用户权限时，ETW 会话可能启动失败；
- 受保护进程、其他用户启动的进程或生命周期很短的进程，可能无法获得完整的进程信息；
- OpenGL 和 Vulkan 的部分高级时序指标精度低于 DirectX，但本项目主要统计帧事件数量，通常仍可计算 FPS；
- 无画面更新、最小化、后台限帧或未产生 Present 事件的程序可能显示空 FPS；
- 多进程应用由前台窗口、关联进程识别和最活跃 SwapChain 共同决定采样目标，特殊启动器或跨权限进程可能识别失败；
- 远程桌面、虚拟机、云桌面及无物理显示输出环境未列入正式支持范围；
- Windows ARM64、Windows Server 和精简版 Windows 尚未完成项目级验证。

## 7. 推荐验证矩阵

正式发布前建议至少验证以下组合：

| 系统 | 显卡厂商 | 建议测试内容 |
| --- | --- | --- |
| Windows 10 22H2 x64 | Intel、AMD、NVIDIA | PresentMon 启动、前台进程识别、FPS 连续采集 |
| Windows 11 23H2 或更高版本 x64 | Intel、AMD、NVIDIA | PresentMon 启动、前台切换、全屏与窗口模式采集 |
| Windows 10/11 x64 普通用户 | 任一 | 性能日志用户组权限验证 |
| Windows 10/11 x64 管理员 | 任一 | 管理员权限采集及跨权限进程行为验证 |

每次升级 PresentMon、Python 运行环境、打包工具或前台进程识别逻辑后，都应重新执行兼容性验证。

## 8. 部署检查

部署或排查 FPS 功能时，应确认：

1. 操作系统为 Windows 10/11 64 位；
2. `PresentMon.exe` 已随程序打包，或通过 `PICO_MONITOR_PRESENTMON` 指定了有效路径；
3. 当前账户具备 ETW 会话所需权限；
4. 显卡驱动已正确安装并处于正常状态；
5. 日志中出现 `PresentMonBackend` 初始化成功和 ETW 采集启动信息；
6. 前台目标程序正在持续渲染并产生帧呈现事件。

当日志显示 `PresentMonBackend` 已启动，而 `AdlxBackend` 因缺少桥接库初始化失败时，应优先检查 PresentMon 是否持续收到帧事件，不需要仅因 ADLX 警告判定 FPS 功能不可用。

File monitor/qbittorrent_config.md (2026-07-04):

# qBittorrent 采集配置

monitor 端通过 qBittorrent Web API 在后台采集传输、用户统计和种子状态。默认关闭；开启后地址、账号、密码均为必填项。API 断开不会阻塞 Pico 主采集循环，最近一次快照会被保留，同时 `qbittorrent.online` 变为 `false`。

## 开启 Web UI

在 qBittorrent 的“工具 → 选项 → Web UI”中启用 Web 用户界面，配置监听地址、端口、用户名和密码。monitor 所在主机必须能够访问该地址；如果跨主机访问，请同时检查防火墙和 qBittorrent 的 Web UI 访问控制设置。

## 命令行配置

```powershell
python pico_monitor.py `
  --qbittorrent-enabled `
  --qbittorrent-address http://127.0.0.1:8080 `
  --qbittorrent-username admin `
  --qbittorrent-password your-password `
  --qbittorrent-interval 2.0
```

使用 `--no-qbittorrent` 可显式关闭采集。密码直接写入命令行可能被系统进程列表记录，长期运行时建议使用环境变量或 Linux 配置文件。

## 环境变量配置

```text
PICO_MONITOR_QBITTORRENT_ENABLED="1"
PICO_MONITOR_QBITTORRENT_ADDRESS="http://127.0.0.1:8080"
PICO_MONITOR_QBITTORRENT_USERNAME="admin"
PICO_MONITOR_QBITTORRENT_PASSWORD="your-password"
PICO_MONITOR_QBITTORRENT_INTERVAL="2.0"
```

Linux 安装包可在 `/etc/pico-monitor.conf` 中填写以上变量，修改后执行：

```bash
sudo systemctl restart pico-monitor
sudo journalctl -u pico-monitor -f
```

`PICO_MONITOR_QBITTORRENT_ENABLED` 支持 `1`、`true`、`yes` 和 `on`。启用后若地址、账号或密码为空，monitor 会立即报告缺失参数并退出；关闭时不会连接 qBittorrent。

## 采集字段

采集结果放在 JSON 顶层 `qbittorrent` 中：

| 字段 | 含义 | 单位 |
| --- | --- | --- |
| `enabled` | qBittorrent 采集已启用 | 布尔值 |
| `online` | 最近一次 API 采集是否成功 | 布尔值 |
| `connection_status` | qBittorrent 连接状态 | `connected`、`firewalled` 或 `disconnected` |
| `error` | 最近一次采集错误，成功时为空 | 文本 |
| `upload_bps` | 当前上传速度 | 字节/秒 |
| `download_bps` | 当前下载速度 | 字节/秒 |
| `upload_history` | 最近 24 秒上传速度 | 字节/秒数组 |
| `download_history` | 最近 24 秒下载速度 | 字节/秒数组 |
| `uploaded_bytes` | 本次会话已上传 | 字节 |
| `downloaded_bytes` | 本次会话已下载 | 字节 |
| `free_space_bytes` | qBittorrent 下载位置剩余空间 | 字节 |
| `user_statistics.alltime_uploaded_bytes` | 历史上传 | 字节 |
| `user_statistics.alltime_downloaded_bytes` | 历史下载 | 字节 |
| `user_statistics.alltime_share_ratio` | 历史分享率 | 比率 |
| `user_statistics.session_wasted_bytes` | 本次会话丢弃数据 | 字节 |
| `user_statistics.connected_users` | 当前连接用户数 | 个 |

`qbittorrent.torrents` 包含以下种子计数：

| 字段 | 含义 |
| --- | --- |
| `all` | 全部种子数 |
| `downloading` | 正在下载数 |
| `seeding` | 正在做种数 |
| `completed` | 已完成数 |
| `resumed` | 已恢复且未暂停数 |
| `paused` | 已暂停数 |
| `active` | 当前有上传或下载流量的种子数 |
| `inactive` | 当前无上传下载流量的种子数 |
| `paused_uploading` | 已完成且上传暂停数 |
| `stalled_uploading` | 上传停滞数 |
| `checking` | 正在检查数 |
| `errored` | 错误或文件缺失数 |

字节字段由显示端按 B、KiB、MiB、GiB、TiB 自动格式化。例如历史上传 `3961542100992` 字节可显示为约 `3.603 TiB`。

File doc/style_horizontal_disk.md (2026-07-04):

# 横向磁盘统计表盘说明

`styles/style_horizontal_disk.py` 实现名为 `horizontal_disk` 的 LCD 表盘样式。该样式面向 320×240 横屏，在保留 CPU、内存和网络概览的同时，把主要显示空间用于磁盘总览和各分区统计。

## 启用方式

监控端通过以下参数选择该样式：

```text
--lcd-style horizontal_disk
```

也可以设置环境变量：

```text
PICO_MONITOR_LCD_STYLE=horizontal_disk
```

样式使用 `screen_2inch` 点阵字体，并声明 `landscape = True`，由渲染器自动切换为 320×240 横向显示。

## 表盘布局

```text
┌──────────── CPU ────────────┐ ┌──────────── STORAGE OVERALL ────────────┐
│ CPU                  占用率 │ │ 总已用/总容量                    占用率 │
│ 温度                        │ │ 总体容量进度条                         │
│ CPU 历史实心面积图          │ ├────────┬────────┬────────┤
└─────────────────────────────┘ │ 磁盘 1 │ 磁盘 2 │ 磁盘 3 │
┌──────────── MEM ────────────┐ ├────────┼────────┼────────┤
│ 占用率       容量进度条     │ │ 磁盘 4 │ 磁盘 5 │ 磁盘 6 │
│ 已用/总容量                 │ ├────────┼────────┼────────┤
└─────────────────────────────┘ │ 磁盘 7 │ 磁盘 8 │ 磁盘 9 │
┌──────────── NET ────────────┐ └────────┴────────┴────────┘
│ NET                 P延迟ms │
│ ↑UP 上传速率                │
│ 上传历史实心面积图          │
│ ↓DN 下载速率                │
│ 下载历史实心面积图          │
└─────────────────────────────┘
┌──────── 时间 ─────── UPTIME ─────────────── PWR ────────┐
└───────────────────────────────────────────────────────────┘
```

左侧区域宽 100 像素，依次显示 CPU、内存和网络；右侧区域宽 212 像素，显示磁盘总览及三列三行的磁盘卡片；底部为全宽状态栏。

## CPU 区域

CPU 区域位于左上角，显示以下内容：

- `CPU` 标题和当前 CPU 温度。
- 右侧使用二倍字号显示当前 CPU 占用率。
- 下方显示 CPU 历史占用率实心面积图，纵轴固定为 0%～100%。
- 面积图和百分比使用当前 CPU 占用率对应的状态颜色。

CPU 和内存占用率颜色规则：

| 数值范围 | 颜色 | 含义 |
| --- | --- | --- |
| 小于 50% | 绿色 | 正常 |
| 50%～79% | 黄色 | 较高 |
| 大于等于 80% | 红色 | 危险 |

## 内存区域

内存区域显示：

- `MEM` 标题。
- 当前内存占用百分比及同色进度条。
- 已用容量和总容量，例如 `51.2/63.9G`。

已用容量与总容量单位相同时，左侧重复单位会被省略。容量按照 B、K、M、G、T 自动换算，其中 G 和 T 保留一位小数。

## 网络区域

网络区域标题缩写为 `NET`，包含延迟、上传和下载信息：

- 延迟显示在标题右侧，例如 `P23ms`；无法取得延迟时显示 `ERR`。
- `↑UP` 表示上传，具体速率使用蓝色，与上传实心面积图一致。
- `↓DN` 表示下载，具体速率使用绿色，与下载实心面积图一致。
- 网络速率根据监控端配置显示为 `B/s`、`KB/s`、`MB/s`、`GB/s`，或者比特速率模式。
- 上传和下载趋势图根据各自历史数据的最大值自动缩放。

网络延迟颜色规则：

| 延迟范围 | 颜色 | 含义 |
| --- | --- | --- |
| 小于 50ms | 绿色 | 良好 |
| 50ms～99ms | 黄色 | 一般 |
| 大于等于 100ms | 红色 | 较高 |
| 无数据 | 红色 | 检测异常 |

## 磁盘总览

右上角 `STORAGE OVERALL` 区域显示全部磁盘的总体统计：

- 已用总容量与总容量。
- 总体磁盘占用百分比。
- 总体容量进度条。

总览边框和标题保持黄色，百分比及进度条按照磁盘占用率动态变色。

## 磁盘卡片

表盘最多显示 9 个磁盘，按三列三行排列。每张卡片包含：

- 盘符或磁盘名称，例如 `C:\`。
- 超过四个字符的磁盘名称会自动压缩，例如 `DISK0` 显示为 `D0`，为温度保留固定空间。
- 当前磁盘温度；无数据时显示灰色 `--C`。
- 已用容量与总容量，使用共享单位并压缩到最多 8 个字符。
- 当前占用百分比和容量进度条。

每个磁盘的边框、盘符、占用百分比和进度条使用相同的占用率颜色：

| 数值范围 | 颜色 | 含义 |
| --- | --- | --- |
| 小于 50% | 绿色 | 空间充足 |
| 50%～89% | 黄色 | 空间逐渐紧张 |
| 大于等于 90% | 红色 | 空间不足 |

## 温度颜色

CPU 温度和所有磁盘温度统一使用以下分级：

| 温度范围 | 颜色 | 含义 |
| --- | --- | --- |
| 小于 50°C | 绿色 | 正常 |
| 50°C～69°C | 黄色 | 偏高 |
| 大于等于 70°C | 红色 | 过高 |
| 无数据 | 灰色 | 未检测到温度 |

温度颜色独立于占用率颜色。例如磁盘空间充足但温度过高时，磁盘边框仍为绿色，温度文本会显示为红色。

## 底部状态栏

底部状态栏从左到右显示：

- 当前时间，格式为 `HH:MM:SS`。
- `UPTIME` 与系统运行时长，格式为 `天数D HH:MM:SS`。
- `PWR` 与当前功耗，单位为 W；无功耗数据时显示 `--W`。

## 动态刷新区域

为减少 Pico LCD 刷新数据量，表盘被拆分为独立脏矩形：

| 区域键 | 坐标与尺寸 | 内容 |
| --- | --- | --- |
| `cpu` | `(2, 2, 100, 69)` | CPU 信息和趋势图 |
| `memory` | `(2, 75, 100, 48)` | 内存信息 |
| `network` | `(2, 127, 100, 82)` | 网络信息和趋势图 |
| `storage_summary` | `(106, 2, 212, 43)` | 磁盘总体统计 |
| `disk_row_0` | `(106, 49, 212, 48)` | 第一行磁盘卡片 |
| `disk_row_1` | `(106, 101, 212, 48)` | 第二行磁盘卡片 |
| `disk_row_2` | `(106, 153, 212, 48)` | 第三行磁盘卡片 |
| `footer` | `(2, 213, 316, 25)` | 底部状态栏 |

首次绘制时，渲染器按当前条带与各区域的交集绘制完整表盘；后续刷新只重绘发生变化的区域。

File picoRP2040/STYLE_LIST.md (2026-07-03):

# LCD 样式列表

本文档简述系统内置 LCD 样式。Monitor 可通过命令行参数选择样式：

```powershell
python pico_monitor.py --lcd-style simple
```

也可以设置环境变量 `PICO_MONITOR_LCD_STYLE`。Pico 未连接 Monitor 时，使用
`config.py` 中的 `LCD_STYLE` 默认值。

## 样式总览

| 选择名称 | 源文件 | 方向与分辨率 | 字体 | 主要用途 |
| --- | --- | --- | --- | --- |
| `default` | `style_default.py` | 竖屏 240×320 | 原生字体 | 通用系统概览 |
| `disk` | `style_disk.py` | 竖屏 240×320 | 原生字体 | 突出磁盘总容量和网络趋势 |
| `horizontal_disk` | `style_horizontal_disk.py` | 横屏 320×240 | 二寸屏字体 | 高密度显示最多九块磁盘 |
| `horizontal_disk4x` | `style_horizontal_disk4x.py` | 横屏 320×240 | 紧凑字体 | 清晰显示最多四块磁盘 |
| `horizontal_disk4x_qb` | `style_horizontal_disk4x_qb.py` | 横屏 320×240 | 紧凑字体 | 四磁盘与 qBittorrent 状态 |
| `horizontal_disk6x` | `style_horizontal_disk6x.py` | 横屏 320×240 | 紧凑字体 | 均衡显示最多六块磁盘 |
| `simple` | `style_simple.py` | 横屏 320×240 | 紧凑字体 | 健康优先的三磁盘简洁视图 |

## default

项目的基础竖屏仪表盘，依次显示 CPU、内存、磁盘、网络和底部状态信息。
CPU、内存和磁盘均提供当前值、详细数值及历史趋势，适合需要完整系统概览且
不强调单块物理磁盘的场景。

## disk

以磁盘总容量和总体占用率为视觉重点，同时显示 CPU、内存、上下行网络速率、
历史趋势、时间和运行时长。布局比 `default` 更突出存储使用情况，适合竖屏设备。

## horizontal_disk

横屏高密度磁盘仪表盘。左侧显示 CPU、内存和网络，右侧显示磁盘总览及三行三列
的物理磁盘卡片，最多显示九块磁盘。磁盘卡片包含容量、占用率、温度和健康告警，
适合磁盘数量较多的主机。

## horizontal_disk4x

横屏双列磁盘仪表盘，最多显示四块物理磁盘。相比九磁盘样式，单块磁盘拥有更大
的显示空间，可展示容量、占用率、温度、读写速率和健康状态；剩余区域用于网络、
GPU 等扩展信息。

## horizontal_disk4x_qb

在 `horizontal_disk4x` 布局基础上加入 qBittorrent 面板。最多显示四块物理磁盘，
并展示 qBittorrent 在线状态、上传下载速度及相关统计。适合同时承担下载任务的
NAS 或家庭服务器。

## horizontal_disk6x

横屏双列三行布局，最多显示六块物理磁盘。信息密度介于四磁盘和九磁盘样式之间，
磁盘卡片包含容量、占用率、温度、实时读写速率和健康告警，适合中等磁盘数量的主机。

## simple

横屏简洁样式，最多显示三块物理磁盘，并按照 `health` 从差到好优先展示。左侧显示
CPU、内存、GPU、网络及网络延迟，右侧显示磁盘总览和磁盘读写信息。CPU、内存、GPU、
网络及磁盘读写历史使用低开销实心渐变面积图。磁盘卡片显示占用率、已用/总容量、
H0 至 H5 健康等级、温度和实时读写速率，适合优先观察异常磁盘及快速刷新。

## 健康等级

物理磁盘健康值含义如下：

| 等级 | 含义 |
| --- | --- |
| `H0` | 未知 |
| `H1` | 健康 |
| `H2` | 注意 |
| `H3` | 警告 |
| `H4` | 严重 |
| `H5` | 失败 |

横屏磁盘样式会使用状态色显示健康告警；达到较高告警等级时，会通过变色或闪烁增强提示。

## 新增样式

新增样式时使用 `style_<名称>.py` 命名，并在模块末尾调用 `register_style()` 注册。
完整插件接口和脏区域刷新约定请参阅 `STYLE_PLUGIN.md`。若样式需要由 Monitor 命令行选择，
还需将选择名称加入 `monitor/pico_monitor.py` 的 `BUILTIN_LCD_STYLES`。

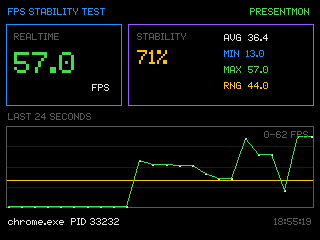
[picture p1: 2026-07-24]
monitor/win/ui-web/assert/style/fpstest.png

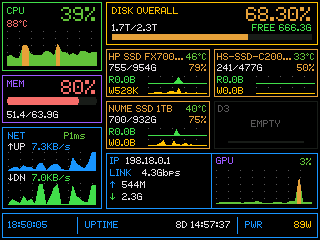
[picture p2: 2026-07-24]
monitor/win/ui-web/assert/style/horizontal_disk4x.png

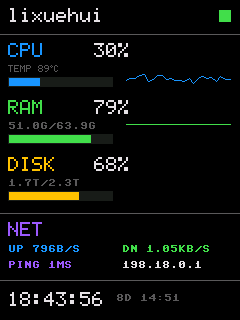
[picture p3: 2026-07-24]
monitor/win/ui-web/assert/style/default.png

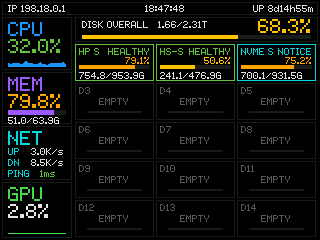
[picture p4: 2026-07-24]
monitor/win/ui-web/assert/style/diskv4.png

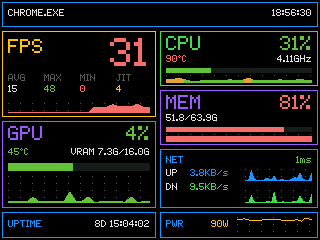
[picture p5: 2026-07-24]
monitor/win/ui-web/assert/style/game2.png

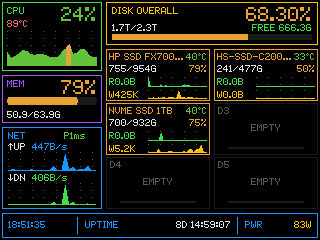
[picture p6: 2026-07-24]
monitor/win/ui-web/assert/style/horizontal_disk6x.png

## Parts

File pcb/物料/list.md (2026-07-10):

 V3 20 × 14 mm MOSFET PWM 板需要以下元件：

位号	元件	封装	数量	下单关键词
Q1	AO3400A N 沟道 MOSFET	SOT-23	1	AO3400A SOT-23
R1	100Ω 电阻，1%	0805	1	0805 100Ω 1%
R2	10kΩ 电阻，1%	0805	1	0805 10K 1%
J1	2Pin 接口	2.54mm 直插	1	2.54mm 单排针 1×2
J2	2Pin 接口	2.54mm 直插	1	2.54mm 单排针 1×2

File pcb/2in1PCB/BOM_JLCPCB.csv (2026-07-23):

Comment | Designator | Footprint | LCSC Part # | Manufacturer Part | Description | Qty
522711079 | J2 | Molex_52271-1079_1x10_P1.00mm_BottomContact | C293625 | 522711079 | 10-pin 1.0 mm bottom-contact ZIF FPC connector | 1
ME6211C30M5G-N | U1 | SOT-23-5 | C403651 | ME6211C30M5G-N | 3.0 V low-noise LDO; CE tied to VIN | 1
CN5711 | U2 | HSOP-8-1EP_P1.27mm | C35634 | CN5711 | Low-dropout constant-current LED driver, 79.6 mA setpoint | 1
22R | R1 | R_0603_1608Metric | C23345 | 0603WAF220JT5E | SCL source termination 22 ohm | 1
22R | R2 | R_0603_1608Metric | C23345 | 0603WAF220JT5E | SDA source termination 22 ohm | 1
33R | R3 | R_0603_1608Metric | C23140 | 0603WAF330JT5E | RESET series resistor 33 ohm | 1
33R | R4 | R_0603_1608Metric | C23140 | 0603WAF330JT5E | DC series resistor 33 ohm | 1
33R | R5 | R_0603_1608Metric | C23140 | 0603WAF330JT5E | CS series resistor 33 ohm | 1
100R | R6 | R_0603_1608Metric | C105588 | RC0603FR-07100RL | BL/PWM input series resistor 100 ohm | 1
10K | R7 | R_0603_1608Metric | C25804 | 0603WAF1002T5E | RESET pull-up | 1
100K | R8 | R_0603_1608Metric | C14675 | RC0603FR-07100KL | CS pull-down | 1
100K | R9 | R_0603_1608Metric | C14675 | RC0603FR-07100KL | Backlight default-off pull-down | 1
22.6K | R10 | R_0603_1608Metric | C185349 | RC0603FR-0722K6L | CN5711 current set: 1800/22600=79.6mA | 1
4.7uF 10V | C1 | C_0805_2012Metric | C380341 | TCC0805X5R475K100FT | LDO input bulk capacitor | 1
100nF 50V | C2 | C_0603_1608Metric | C14663 | CC0603KRX7R9BB104 | LDO input high-frequency bypass | 1
1uF 50V | C3 | C_0603_1608Metric | C15849 | CL10A105KB8NNNC | LDO output capacitor | 1
100nF 50V | C4 | C_0603_1608Metric | C14663 | CC0603KRX7R9BB104 | LCD local high-frequency bypass | 1
100nF 50V | C5 | C_0603_1608Metric | C14663 | CC0603KRX7R9BB104 | Power-on reset capacitor | 1
1uF 50V | C6 | C_0603_1608Metric | C15849 | CL10A105KB8NNNC | CN5711 local input capacitor | 1

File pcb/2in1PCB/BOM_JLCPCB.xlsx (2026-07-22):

Comment | Designator | Footprint | LCSC Part # | Manufacturer Part | Description | Qty | pice | buy qty | 1pice price
522711079 | J2 | Molex_52271-1079_1x10_P1.00mm_BottomContact | C293625 | 522711079 | 10-pin 1.0 mm bottom-contact ZIF FPC connector | 1 | 0.7 | 1 | 0.7
ME6211C30M5G-N | U1 | SOT-23-5 | C403651 | ME6211C30M5G-N | 3.0 V low-noise LDO; CE tied to VIN | 1 | 0.25 | 1 | 0.25
CN5711 | U2 | HSOP-8-1EP_P1.27mm | C35634 | CN5711 | Low-dropout constant-current LED driver, 79.6 mA setpoint | 1 | 0.56 | 1 | 0.56
22R | R1 | R_0603_1608Metric | C23345 | 0603WAF220JT5E | SCL source termination 22 ohm | 1 | 4.5 | 200 | 0.0225
22R | R2 | R_0603_1608Metric | C23345 | 0603WAF220JT5E | SDA source termination 22 ohm | 1 | 4.5 | 200 | 0.0225
33R | R3 | R_0603_1608Metric | C23140 | 0603WAF330JT5E | RESET series resistor 33 ohm | 1 | 1.76 | 50 | 0.0352
33R | R4 | R_0603_1608Metric | C23140 | 0603WAF330JT5E | DC series resistor 33 ohm | 1 | 1.76 | 50 | 0.0352
33R | R5 | R_0603_1608Metric | C23140 | 0603WAF330JT5E | CS series resistor 33 ohm | 1 | 1.76 | 50 | 0.0352
100R | R6 | R_0603_1608Metric | C105588 | RC0603FR-07100RL | BL/PWM input series resistor 100 ohm | 1 | 4.5 | 200 | 0.0225
10K | R7 | R_0603_1608Metric | C25804 | 0603WAF1002T5E | RESET pull-up | 1 | 4.5 | 200 | 0.0225
100K | R8 | R_0603_1608Metric | C14675 | RC0603FR-07100KL | CS pull-down | 1 | 1.76 | 50 | 0.0352
100K | R9 | R_0603_1608Metric | C14675 | RC0603FR-07100KL | Backlight default-off pull-down | 1 | 1.76 | 50 | 0.0352
22.6K | R10 | R_0603_1608Metric | C185349 | RC0603FR-0722K6L | CN5711 current set: 1800/22600=79.6mA | 1 | 2.42 | 50 | 0.0484
4.7uF 10V | C1 | C_0805_2012Metric | C380341 | TCC0805X5R475K100FT | LDO input bulk capacitor | 1 | 10 | 50 | 0.2
100nF 50V | C2 | C_0603_1608Metric | C14663 | CC0603KRX7R9BB104 | LDO input high-frequency bypass | 1 | 5 | 50 | 0.1
1uF 50V | C3 | C_0603_1608Metric | C15849 | CL10A105KB8NNNC | LDO output capacitor | 1 | 5.5 | 50 | 0.11
100nF 50V | C4 | C_0603_1608Metric | C14663 | CC0603KRX7R9BB104 | LCD local high-frequency bypass | 1 | 5 | 50 | 0.1
100nF 50V | C5 | C_0603_1608Metric | C14663 | CC0603KRX7R9BB104 | Power-on reset capacitor | 1 | 5 | 50 | 0.1
1uF 50V | C6 | C_0603_1608Metric | C15849 | CL10A105KB8NNNC | CN5711 local input capacitor | 1 | 5.5 | 50 | 0.11
 |  |  |  |  |  |  |  |  | 2.5444
PCB |  |  |  |  |  | 1 | 35 | 10 | 3.5
LCD 240*320 IPS 10PIN
ESP32-S3 R16N8 |  |  |  |  |  | 1 | 26.6 | 2 | 13.3 | 屏幕+ PCB +ESP32-S3 成本
 |  |  |  |  |  | 1 | 22.6 | 1 | 22.6 | 41.9444
 |  |  |  |  |  |  |  |  |  | 利润35% 售价为
 |  |  |  |  |  |  |  |  |  | 56.62494

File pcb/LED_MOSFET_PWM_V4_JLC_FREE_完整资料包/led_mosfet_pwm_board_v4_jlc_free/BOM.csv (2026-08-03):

Comment | Designator | Footprint | Qty | Suggested Part
100R | R1 | 0805 | 1 | 0805 1% 100Ω
10K | R2 | 0805 | 1 | 0805 1% 10kΩ
AO3400A | Q1 | SOT-23 | 1 | AO3400A, pin 1=G 2=S 3=D
1x2 2.54mm | J1,J2 | PTH-2.54-1x2 | 2 | Pin header or solder wires directly

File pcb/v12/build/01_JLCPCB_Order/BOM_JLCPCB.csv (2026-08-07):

Comment | Designator | Footprint | LCSC Part # | Manufacturer Part | Qty | Assembly | Notes
10P 1.0mm FPC Bottom Contact, edge-facing | J1 | F-FPC1M10P-C310 | C132509 | F-FPC1M10P-C310 | 1 | SMT | 0.3mm FPC, bottom contact; cable entry faces board edge; 0.45x2.30mm signal pads; enlarged 2.8x2.8mm anchor copper
AO3400A | Q1 | SOT-23 | C20917 | AO3400A | 1 | SMT | Low-side LED- PWM MOSFET; FPC pin 1
100R | R1 | 0603 | C22775 | 0603WAF1000T5E | 1 | SMT | MOSFET gate series resistor
10K | R2 | 0603 | C25804 | 0603WAF1002T5E | 1 | SMT | Gate pulldown, default off
25R | R3 | 0603 | DNP | Generic 25 ohm 0603 | 1 | Hand solder | Series resistor between FPC pin 2 and LEDA breakout; select 25 ohm
2x5 2.54mm header | J2 | PinHeader_2x05_P2.54mm | DNP | Generic | 1 | Hand solder | 10-pin 1:1 breakout
1x2 2.54mm header | J3 | PinHeader_1x02_P2.54mm | DNP | Generic | 1 | Hand solder | PWM + GND input

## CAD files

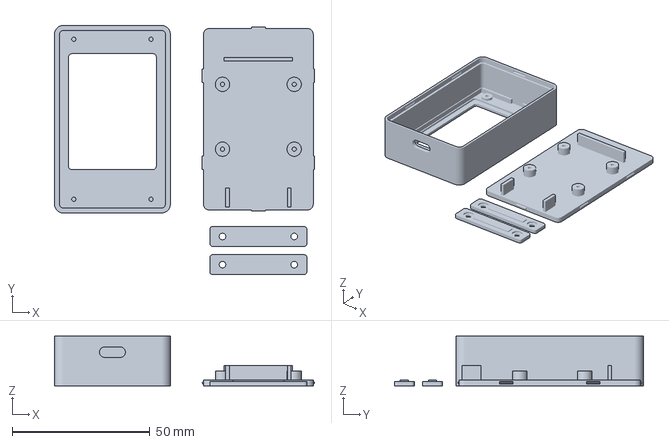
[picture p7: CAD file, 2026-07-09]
3d/2in1/2p/verify-v7/3mf/2英寸间距调整2026-7-9 v7版本.3mf
94.2 x 90.3 x 18.0 mm

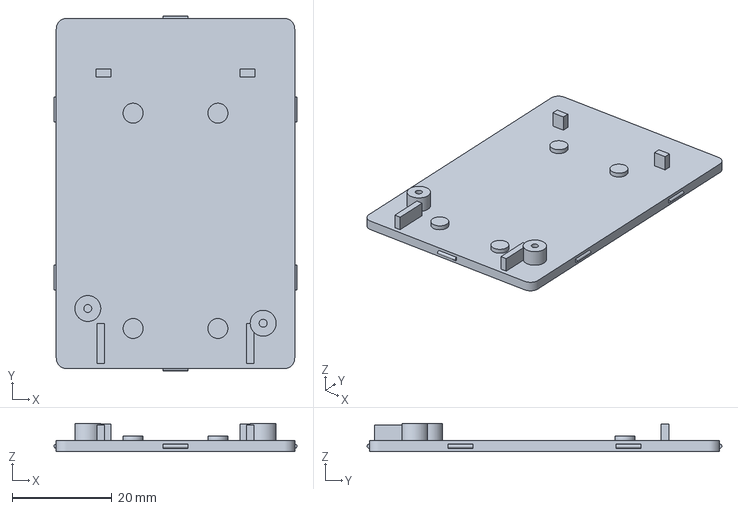
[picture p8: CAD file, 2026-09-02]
3d/2in1/2p4-10pin/verify-v11/02_back_cover.3mf
48.7 x 71.1 x 5.70 mm

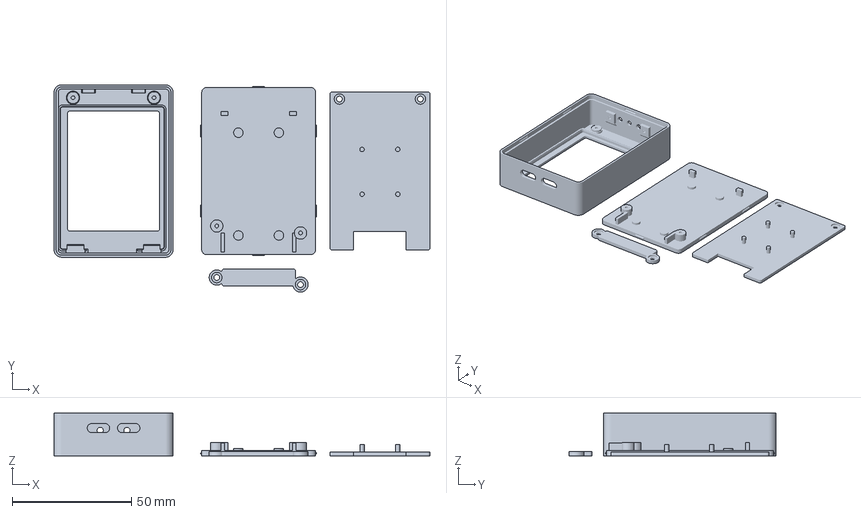
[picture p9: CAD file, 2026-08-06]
3d/2in1/2p4-10pin/verify-v11/3mf/外壳_V16_2026-8.3mf
157.8 x 87.0 x 18.0 mm

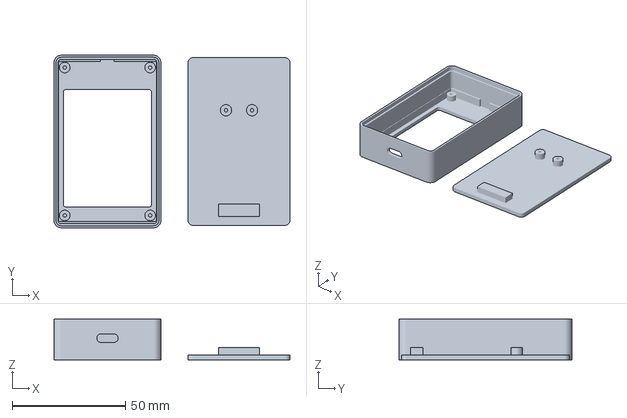
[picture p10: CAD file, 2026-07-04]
3d/2in1/2p4/pico_typec_aligned_cover-v1.3mf
104.2 x 76.2 x 18.0 mm

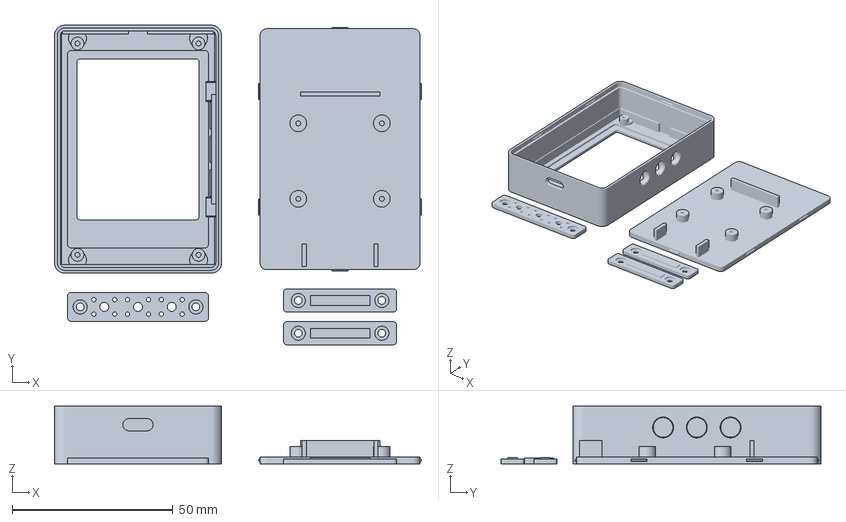
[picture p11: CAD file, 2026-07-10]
3d/2in1/2p4/verify-v5/3mf/2.4寸_右侧三按键_屏幕螺柱避让开窗优化版.3mf
114.2 x 99.5 x 18.0 mm

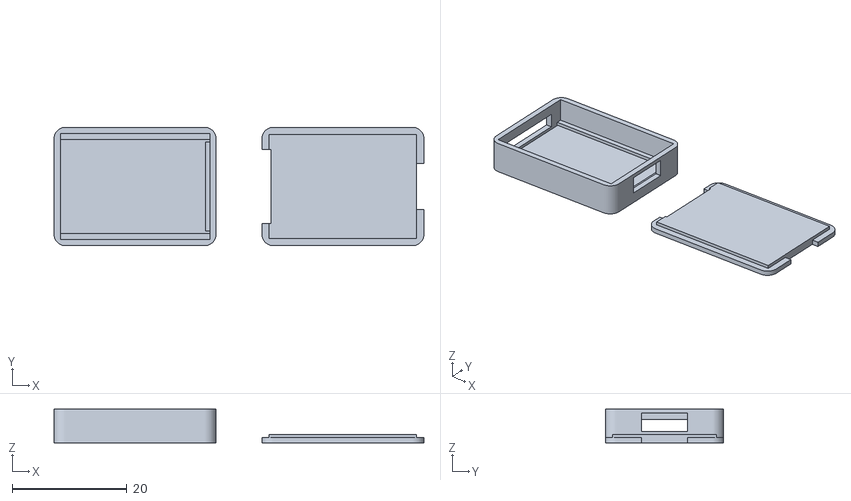
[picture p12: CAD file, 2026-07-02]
3d/usb_rp2040_4m_dongle_case_v2.stl
64.6 x 20.7 x 5.90

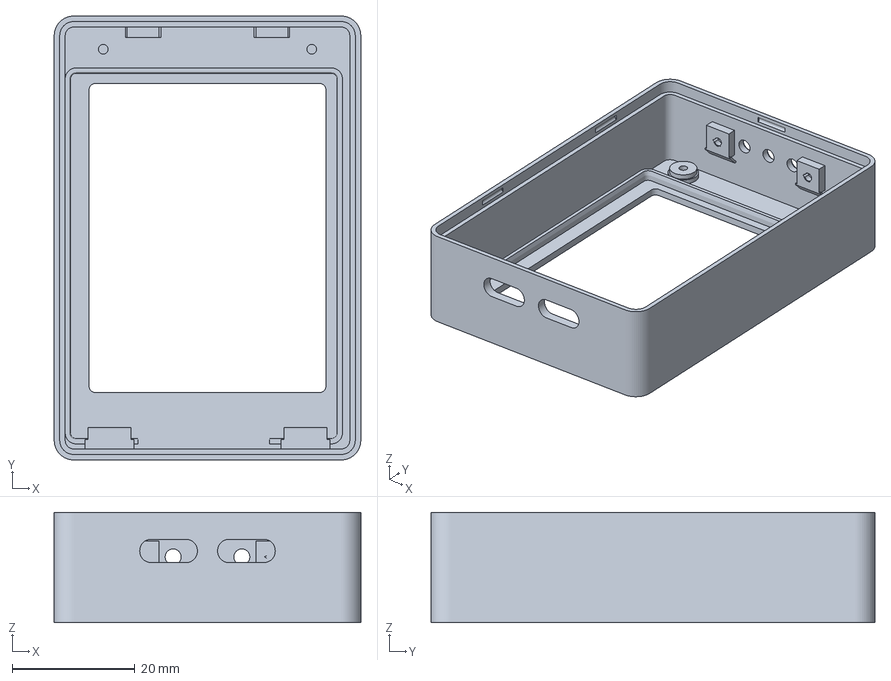
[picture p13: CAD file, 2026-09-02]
3d/2in1/2p4-10pin/verify-v11/01_front_shell.3mf
50.0 x 72.4 x 18.0 mm

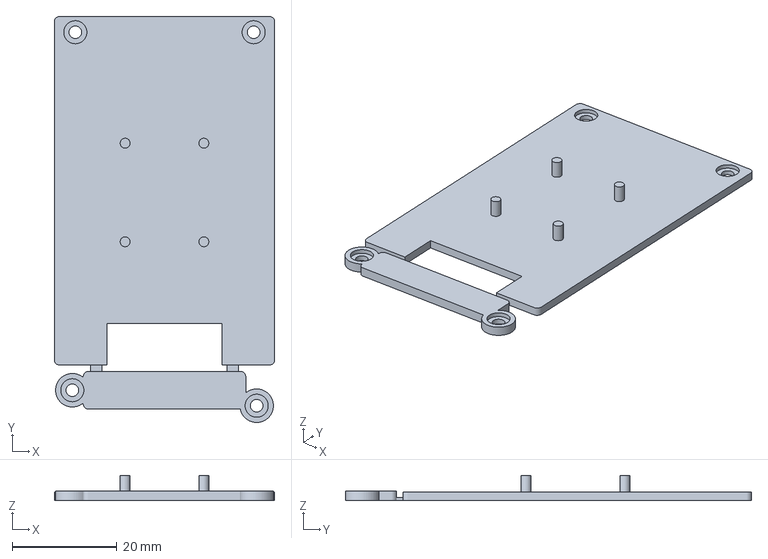
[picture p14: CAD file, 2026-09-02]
3d/2in1/2p4-10pin/verify-v11/oem/03_04_screen_esp32_breakaway.3mf
42.0 x 77.4 x 4.80 mm

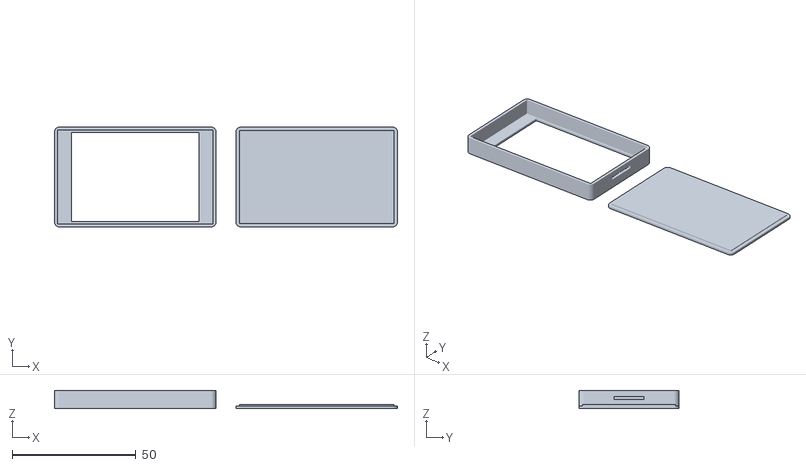
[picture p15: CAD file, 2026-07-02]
3d/pico_2inch_tft_minimal_landscape_case.stl
138.4 x 40.3 x 7.40

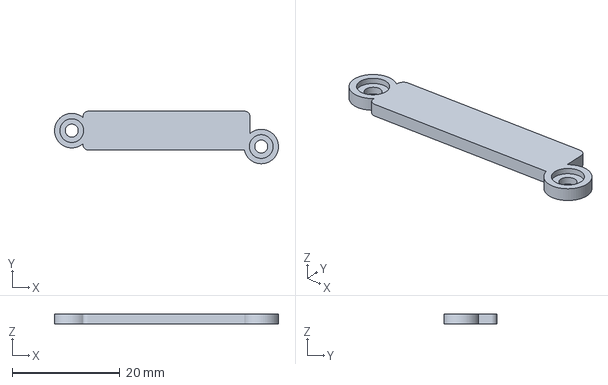
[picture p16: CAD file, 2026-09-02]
3d/2in1/2p4-10pin/verify-v11/04_esp32_usb_clamp_bar.3mf
41.5 x 9.75 x 1.80 mm

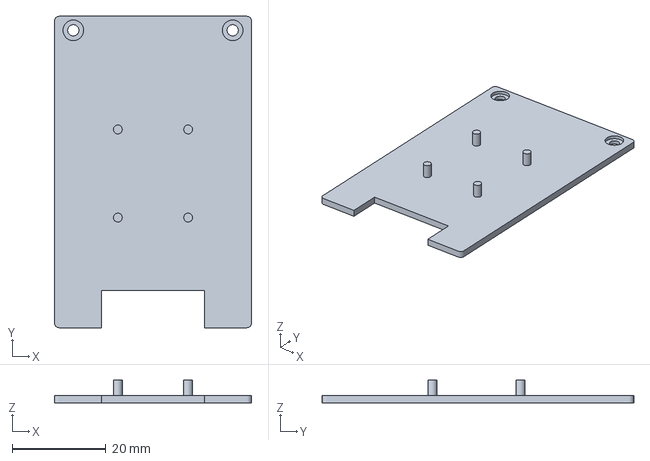
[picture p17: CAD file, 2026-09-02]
3d/2in1/2p4-10pin/verify-v11/03_screen_clamp_bar.3mf
42.0 x 66.4 x 4.80 mm

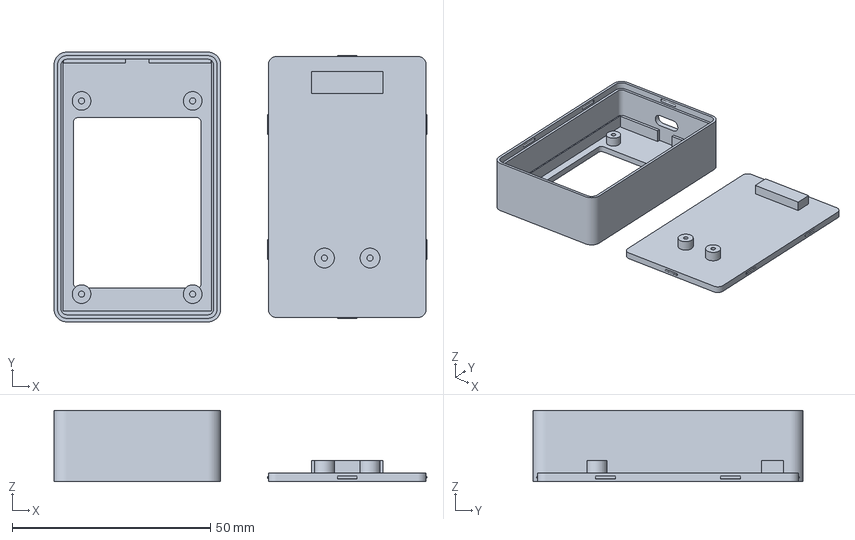
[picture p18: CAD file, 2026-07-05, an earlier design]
3d/2in1/2p/verify-v1/3mf/pico_case_2inch_st7789_arc_bead_typec_opposite.3mf
94.0 x 68.0 x 18.0 mm

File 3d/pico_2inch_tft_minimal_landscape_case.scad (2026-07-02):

/*
Minimal landscape enclosure for 2.0" 240x320 TFT module
Based on supplied drawing:
- PCB: 37.10 ±0.20 x 62.00 ±0.20 mm
- PCB thickness: 1.20 mm
- Module max thickness: 6.00 mm
- BL/view area: 35.70 x 51.20 mm
- Cable slot: 12 x 1 mm

Orientation: landscape, so PCB becomes 62.0 W x 37.1 H.

Print note:
- For FDM 0.4 mm nozzle, 1.2 mm wall = 3 perimeters.
- Print front_shell face-down.
- First print a 1-layer test ring if your printer tolerance is unknown.
*/

$fn = 36;

// ---------- Parameters ----------
pcb_w_portrait = 37.10;
pcb_h_portrait = 62.00;
pcb_tol = 0.20;          // datasheet tolerance
fit_clearance = 0.30;    // clearance per side for 3D printing

// Landscape PCB maximum envelope
pcb_w = pcb_h_portrait + pcb_tol;   // 62.20
pcb_h = pcb_w_portrait + pcb_tol;   // 37.30

inner_w = pcb_w + fit_clearance * 2; // 62.80
inner_h = pcb_h + fit_clearance * 2; // 37.90

wall = 1.20;
front_lip = 1.00;
module_depth = 6.00;
depth_clearance = 0.40;

front_shell_z = front_lip + module_depth + depth_clearance; // 7.40
back_cover_z = 1.00;
total_z = front_shell_z + back_cover_z; // 8.40 if cover installed

outer_w = inner_w + wall * 2; // 65.20
outer_h = inner_h + wall * 2; // 40.30
corner_r = 2.00;

// Full BL/view window, rotated landscape.
// If you want only active AA area exposed, use 41.2 x 31.0 instead.
window_w = 51.20 + 0.40; // 51.60
window_h = 35.70 + 0.40; // 36.10

// Cable outlet on the connector side.
// Right side by default for landscape orientation; mirror model if your cable exits left.
cable_slot_len = 12.00;
cable_slot_h = 1.20;     // nominal 1 mm, enlarged to print reliably
cable_slot_z = 3.80;     // vertical position on side wall

// Optional cover fit
cover_inset_clearance = 0.20;
cover_inset_h = 0.60;

// ---------- Helpers ----------
module rounded_box(w, h, z, r) {
    hull() {
        translate([ r,  r, 0]) cylinder(h=z, r=r);
        translate([w-r, r, 0]) cylinder(h=z, r=r);
        translate([w-r, h-r, 0]) cylinder(h=z, r=r);
        translate([r, h-r, 0]) cylinder(h=z, r=r);
    }
}

// ---------- Parts ----------
module front_shell() {
    difference() {
        rounded_box(outer_w, outer_h, front_shell_z, corner_r);

        // Rear cavity for PCB/module, open from back
        translate([wall, wall, front_lip])
            cube([inner_w, inner_h, front_shell_z + 0.2], center=false);

        // Front display window
        translate([(outer_w-window_w)/2, (outer_h-window_h)/2, -0.1])
            cube([window_w, window_h, front_lip + 0.3], center=false);

        // Cable ribbon slot, 12 x ~1 mm, through right side wall
        translate([outer_w - wall - 0.2, (outer_h-cable_slot_len)/2, cable_slot_z])
            cube([wall + 0.6, cable_slot_len, cable_slot_h], center=false);
    }
}

module back_cover() {
    // Thin removable back cover with shallow inset lip
    union() {
        difference() {
            rounded_box(outer_w, outer_h, back_cover_z, corner_r);
            // tiny corner relief to avoid elephant-foot interference
        }
        translate([wall + cover_inset_clearance, wall + cover_inset_clearance, back_cover_z])
            cube([inner_w - cover_inset_clearance*2, inner_h - cover_inset_clearance*2, cover_inset_h], center=false);
    }
}

// Layout: front shell and cover side-by-side for export/printing.
// Export one module at a time if your slicer prefers separate STLs.
front_shell();

translate([outer_w + 8, 0, 0])
    back_cover();

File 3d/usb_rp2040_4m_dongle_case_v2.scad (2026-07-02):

/*
USB RP2040 (4M) dongle-style board enclosure - v2
Based on user's reference drawing.

Unit: mm

Reference dimensions read from the image:
- Main PCB body: 25.40 x 17.78 mm
- USB plug/tongue section length: 12.70 mm
- USB plug/tongue section width: 12.19 mm
- Total board length: 38.10 mm
- Pin row span shown: 20.32 mm

Design goal:
- Small and thin enclosure.
- Front USB plug area is considered: USB tongue is exposed, shell starts behind it.
- Rear wire harness exit hole is reserved.
- Two-piece shell: bottom tray + top cover.

Important:
Different USB RP2040 4M clones may vary slightly. First print a test ring or print at low height
to verify USB cutout and board fit before final printing.
*/

$fn = 48;

// ======================================================
// 1. Board parameters from image
// ======================================================
main_len = 25.40;          // right/main rounded PCB length
main_w   = 17.78;          // main PCB width
usb_len  = 12.70;          // left USB plug section length
usb_w    = 12.19;          // left USB plug section width
board_thick = 1.20;

// FDM clearance
fit_clearance = 0.35;      // per side
z_clearance = 0.25;

// ======================================================
// 2. Case dimensions
// ======================================================
wall = 1.10;               // minimum practical FDM wall, 0.4 nozzle ~3 lines
bottom_thick = 0.90;
top_thick = 0.90;
corner_r = 2.00;

// board vertical spaces
bottom_air = 0.70;
top_air = 3.10;            // room for chips / connector / solder
tray_z = bottom_thick + bottom_air + board_thick + top_air;   // ~5.9
cover_lip_z = 0.60;
total_z = tray_z + top_thick;                                 // ~6.8

// Shell only covers the main PCB body. USB plug stays exposed.
inner_len = main_len + fit_clearance * 2;
inner_w   = main_w + fit_clearance * 2;

outer_len = inner_len + wall * 2;     // ~29.0
outer_w   = inner_w + wall * 2;       // ~20.7

// USB-front opening. The case front wall has a notch for the 12.19 mm wide USB tongue.
usb_notch_w = usb_w + 0.80;
usb_notch_h = 2.60;                   // vertical opening near PCB plane
usb_notch_z = bottom_thick + bottom_air - 0.15;

// Rear wiring harness slot.
// If the actual cable is thicker, increase harness_slot_w / h.
harness_slot_w = 8.00;
harness_slot_h = 3.20;
harness_slot_z = bottom_thick + bottom_air + 0.40;

// Optional top connector window for wiring/soldering access.
top_wire_window = true;
top_window_len = 9.50;
top_window_w = 8.00;

// Optional small side relief slots for GPIO/soldered side wires.
side_wire_slots = false;
side_slot_len = 16.00;
side_slot_h = 2.20;
side_slot_z = bottom_thick + bottom_air + board_thick + 0.30;

// ======================================================
// 3. Helpers
// ======================================================
module rounded_box(l, w, z, r) {
    hull() {
        translate([r, r, 0]) cylinder(h=z, r=r);
        translate([l-r, r, 0]) cylinder(h=z, r=r);
        translate([l-r, w-r, 0]) cylinder(h=z, r=r);
        translate([r, w-r, 0]) cylinder(h=z, r=r);
    }
}

module usb_tongue_reference() {
    // Pure reference only, not printed unless enabled at bottom.
    color([0.02,0.02,0.02,0.35])
    translate([-usb_len, (outer_w-usb_w)/2, bottom_thick + bottom_air])
        cube([usb_len, usb_w, board_thick]);
}

module main_board_reference() {
    color([0,0.45,0.1,0.35])
    translate([wall + fit_clearance, wall + fit_clearance, bottom_thick + bottom_air])
        cube([main_len, main_w, board_thick]);
}

// ======================================================
// 4. Bottom tray
// ======================================================
module bottom_tray() {
    difference() {
        rounded_box(outer_len, outer_w, tray_z, corner_r);

        // Main board cavity, open from top
        translate([wall, wall, bottom_thick])
            cube([inner_len, inner_w, tray_z + 0.30]);

        // Front USB notch/opening at x=0.
        // This allows the exposed USB tongue to leave the enclosure.
        translate([-0.20, (outer_w-usb_notch_w)/2, usb_notch_z])
            cube([wall + 0.70, usb_notch_w, usb_notch_h]);

        // Rear wire harness outlet at x=outer_len.
        translate([outer_len - wall - 0.20, (outer_w-harness_slot_w)/2, harness_slot_z])
            cube([wall + 0.70, harness_slot_w, harness_slot_h]);

        // Optional long-side wire exits
        if (side_wire_slots) {
            translate([(outer_len-side_slot_len)/2, -0.20, side_slot_z])
                cube([side_slot_len, wall + 0.60, side_slot_h]);

            translate([(outer_len-side_slot_len)/2, outer_w-wall-0.30, side_slot_z])
                cube([side_slot_len, wall + 0.70, side_slot_h]);
        }
    }

    // Minimal board support ledges instead of screw posts to save space.
    // These avoid blocking parts on tiny boards.
    ledge_w = 1.00;
    ledge_h = 0.60;
    ledge_z = bottom_thick + bottom_air - ledge_h;

    translate([wall, wall, ledge_z])
        cube([inner_len, ledge_w, ledge_h]);

    translate([wall, wall + inner_w - ledge_w, ledge_z])
        cube([inner_len, ledge_w, ledge_h]);

    // Small rear stop to stop board sliding backward
    translate([outer_len - wall - 0.75, wall + 1.5, ledge_z])
        cube([0.75, inner_w - 3.0, ledge_h]);
}

// ======================================================
// 5. Top cover
// ======================================================
module top_cover() {
    lip_clearance = 0.18;

    difference() {
        union() {
            rounded_box(outer_len, outer_w, top_thick, corner_r);

            // Inset lip into tray
            translate([wall + lip_clearance, wall + lip_clearance, top_thick])
                cube([
                    inner_len - lip_clearance * 2,
                    inner_w   - lip_clearance * 2,
                    cover_lip_z
                ]);
        }

        // Front USB relief mirrored on cover
        translate([-0.20, (outer_w-usb_notch_w)/2, -0.10])
            cube([wall + 0.70, usb_notch_w, top_thick + cover_lip_z + 0.30]);

        // Rear wiring relief mirrored on cover
        translate([outer_len - wall - 0.20, (outer_w-harness_slot_w)/2, -0.10])
            cube([wall + 0.70, harness_slot_w, top_thick + cover_lip_z + 0.30]);

        // Optional top access window for rear connector / wire solder area
        if (top_wire_window) {
            translate([outer_len - top_window_len - 2.2, (outer_w-top_window_w)/2, -0.10])
                cube([top_window_len, top_window_w, top_thick + 0.30]);
        }
    }
}

// ======================================================
// 6. Print layout
// ======================================================
// Left: bottom tray
// Right: top cover
bottom_tray();

translate([outer_len + 8, 0, 0])
    top_cover();

// Uncomment for reference preview only:
// usb_tongue_reference();
// main_board_reference();

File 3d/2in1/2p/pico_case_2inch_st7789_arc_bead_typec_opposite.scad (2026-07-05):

/*
 如果打印后发现屏幕显示区上下偏一点，优先调这个参数：

screen_window_y_offset = -4.00;

数值更负，开窗往屏幕下方移动；数值变大，开窗往排针那边移动。

  Simple adhesive rear-cover enclosure for Raspberry Pi Pico RP2040 USB-C + 2.0 inch ST7789 240x320 TFT
  Variant: arc bead + closed arc scoop only, no guide-slot entrance
  Unit: mm

  Revision:
    - No middle separator.
    - Screen module is inserted from the rear and fixed to the front shell by the screen's four PCB screw holes.
    - Rear cover has NO screws and NO rigid snap tabs. It uses tiny arc-shaped locating beads plus matching closed shallow arc scoops.
    - Rear edge of the front shell is half-thickness recessed, forming a simple rabbet/lap seat for the cover.
    - Rear cover drops into that half-wall recess and can be glued around the edge.
    - Rear cover carries the Pico, fixed only by the Pico tail two screw holes.
    - Shell opposite short side has a rounded USB Type-C opening.
    - Front border is kept narrow by removing rear-cover screw posts and snap structures.
    - No guide-slot entrance is used; only arc beads on the rear cover and closed arc scoops in the front-shell rear lip.

  Coordinate system:
    X = screen width
    Y = screen height; positive Y is the USB-C side in this variant
    Z = front -> rear

  Export:
    Change `part` below to:
      "print_plate" : front_shell and back_cover laid flat side-by-side on the same Z=0 print plane
      "front_shell" : front frame/tray, screen four bosses, Type-C opening, half-thickness rear rabbet
      "back_cover"  : glue-in rear cover with Pico tail two-screw standoffs
      "assembly"    : preview only
      "exploded"    : preview only

  Print suggestion:
    - FDM: 0.2 mm layer, 3 walls, 15~25% infill.
    - `print_plate` puts both printable parts on the same Z=0 plane.
    - front_shell is placed with the screen face on the bed.
    - back_cover is placed with the outside/back face on the bed, Pico standoffs upward.
    - Rear cover adds tiny arc beads and the front shell has matching closed shallow arc scoops; no guide-slot entrance is added.
    - Use thin double-sided tape / silicone / small hot-glue dots around the rear rabbet edge if you still want extra security.
    - Avoid 502 near the display and USB-C connector.
*/

$fn = 56;
part = "print_plate";    // "print_plate", "front_shell", "back_cover", "assembly", "exploded"

// ---------- 3D printing / fit ----------
wall = 1.80;               // slim but still printable side wall
front_thick = 2.00;        // front face / bezel thickness
corner_r = 3.20;
fit_clearance = 0.40;      // screen PCB locator clearance
cover_clearance = 0.40;    // total XY clearance for the glue-in rear cover
plate_gap = 12.00;          // gap between front shell and back cover in print_plate mode

// ---------- Screen module, from your 2.0 inch ST7789 drawing ----------
// Drawing values used:
//   PCB: 37.10 x 62.00 x 1.20
//   Four mounting holes: diameter 2.50, X spacing 28.00
//   Hole X offset from left edge: 4.50
//   Top-hole Y from top edge: 9.30; bottom-hole Y from top edge: 58.00
//   Active area AA: 30.60 x 40.80
//   Black lens/BL reference: 35.70 x 51.20
screen_pcb_w = 37.10;
screen_pcb_h = 62.00;
screen_pcb_t = 1.20;
screen_hole_d = 2.50;

// This 2.0 inch PCB's four holes are not vertically symmetric around the PCB center,
// so the positions are defined from the PCB top/left edges instead of only using dx/dy.
screen_hole_x_from_left = 4.50;
screen_hole_x_spacing = 28.00;
screen_hole_top_y_from_top = 9.30;
screen_hole_bottom_y_from_top = 58.00;

// Visible opening. Slightly larger than AA, but smaller than the black lens/BL outline.
screen_va_w = 30.60;
screen_va_h = 40.80;
screen_window_w = screen_va_w + 1.60;   // 32.20
screen_window_h = screen_va_h + 2.20;   // 43.00
screen_window_y_offset = -4.00;         // active area is lower than the PCB/header center; tune after test print if needed
screen_window_r = 1.20;

// Screen screw bosses in the front shell. Screen is screwed from the rear into these bosses.
screen_boss_od = 4.70;
screen_boss_h = 3.00;
screen_boss_pilot_d = 1.55;         // M2 self-tapping pilot; change to 2.20 for through-hole

// Simple solid screen PCB locator lips. No tiny decorative grooves.
screen_lip_t = 1.20;
screen_lip_h = screen_boss_h + 1.10;

// ---------- Enclosure size ----------
// Kept close to the screen PCB size to reduce the visual border.
body_w = 42.00;
body_h = 68.00;
shell_depth = 18.00;       // enough for screen PCB + wiring + Pico on rear cover

// ---------- Recessed adhesive rear cover ----------
cover_t = 2.20;

// Rear-cover rabbet / lap joint:
// the rear edge of the front shell is thinned to about 1/2 wall thickness.
// The cover sits into this larger rear recess instead of only fitting inside the full inner cavity.
// This avoids card扣/螺丝 and keeps the visible frame slim.
rear_edge_wall = wall / 2;        // remaining rear rim thickness after cutting the shell edge thinner
rear_rebate_depth = cover_t;      // depth of the cover seat; normally equal to cover thickness

inner_w = body_w - 2*wall;
inner_h = body_h - 2*wall;
rear_rebate_w = body_w - 2*rear_edge_wall;
rear_rebate_h = body_h - 2*rear_edge_wall;
cover_w = rear_rebate_w - cover_clearance;
cover_h = rear_rebate_h - cover_clearance;

// ---------- Arc locating beads / closed matching shallow scoops ----------
// No guide-slot entrance: only tiny arc beads on the rear cover edge + closed arc scoops in the front-shell rear lip.
// With cover_clearance = 0.40, nominal side clearance is about 0.20 mm per side.
// detent_bead_out = 0.20 mm is set to roughly match that clearance, so it should act as a soft locator rather than a hard press-fit.
// For looser/no-click assembly use 0.16~0.18; for a slight snap feel use 0.22~0.25.
enable_arc_detents = true;
detent_bead_out = 0.20;          // protrusion beyond rear-cover edge; keep <= 0.20 for minimum deformation on this model
detent_bead_r = 0.42;            // cylinder radius; larger than out value so the visible protrusion is smooth/arc-shaped
detent_bead_len = 5.00;          // length of each bead along the edge
detent_pocket_depth = 0.34;      // closed shallow arc scoop depth in the front-shell rear lip
detent_pocket_extra = 1.20;      // scoop is slightly longer than bead for easy alignment
detent_pocket_r_extra = 0.08;    // scoop radius clearance over bead radius
detent_side_overlap = 0.04;      // tiny overlap with rabbet cavity to avoid coplanar artifacts

// Positions of the two beads on each long side, expressed as a fraction of cover height.
detent_long_y_frac = 0.24;

// One bead on each short side, centered. Set false if you only want the two long-side pairs.
enable_short_edge_detents = true;

// ---------- Raspberry Pi Pico RP2040 USB-C, from your Pico drawing ----------
pico_pcb_w = 21.00;
pico_pcb_h = 51.00;
pico_pcb_t = 1.30;
pico_hole_dx = 11.50;
pico_hole_dy = 47.00;       // please measure your actual Pico board if possible
pico_hole_d = 2.10;

// Pico placement on the rear cover.
// USB-C side is controlled by pico_usb_side_y.
//   1  = Type-C on positive-Y short side / opposite side in this variant
//  -1  = Type-C on original negative-Y short side
// IMPORTANT:
// Keep the Type-C opening derived from the Pico position on the rear cover.
// Do not tune the shell opening independently, otherwise the port may not align after the Pico is screwed to the cover.
pico_usb_edge_inset = 1.10;
pico_usb_side_y = 1;  // 1 = Type-C moved to opposite side, -1 = original side
pico_usb_edge_y = pico_usb_side_y * (body_h/2 - wall - pico_usb_edge_inset);
pico_center_y = pico_usb_edge_y - pico_usb_side_y * pico_pcb_h/2;
pico_center_x = 0;

// Pico tail screw standoffs on the rear cover.
pico_standoff_od = 5.00;
pico_standoff_h = 3.20;
pico_standoff_pilot_d = 1.55;       // M2 self-tapping pilot

// Broad support pad near Pico USB side. This prevents the USB side from floating.
// It is intentionally a solid pad, not a thin rail.
enable_pico_usb_support_pad = true;
pico_usb_pad_w = 18.00;
pico_usb_pad_h = 5.50;
pico_usb_pad_z = pico_standoff_h;

// ---------- USB-C opening ----------
// Rounded Type-C shaped side opening, not a square hole.
// The opening position is calculated from the Pico mounted on the rear cover,
// so changing cover_t / pico_standoff_h / pico_usb_edge_inset will move the opening together.
typec_open_w = 9.40;
typec_open_h = 3.80;
typec_open_r = typec_open_h/2 - 0.05;
typec_cut_depth = wall + 4.50;

// Type-C connector mouth position relative to the Pico PCB USB-side edge.
// Positive value means the connector mouth protrudes past the Pico PCB USB edge toward the selected short side.
typec_mouth_from_pico_usb_edge = 1.20;
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

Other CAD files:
3d/2in1/2p4-10pin/verify-v11/oem/02_back_cover.3mf
3d/2in1/2p4-10pin/verify-v11/oem/01_front_shell.3mf
3d/2in1/2p/verify-v2/3mf/2寸卡扣版本-2026-07-06 v2.3mf
3d/2in1/2p/verify-v3/3mf/2英寸-2026-07-5 v3版本.3mf
3d/2in1/2p/verify-v4/3mf/2英寸螺柱降低版2026-7-6 v4.3mf
3d/2in1/2p/verify-v5/3mf/2英寸PCB压紧版本 2026-7-7v5.3mf
3d/2in1/2p4-button/pico_case_2.4inch_rear_3buttons_cn.scad
3d/2in1/2p/verify-v2/3mf/pico_case_2inch_st7789_arc_bead_typec_opposite.3mf
3d/2in1/2p/verify-v2/pico_case_2inch_st7789_arc_bead_typec_opposite.scad
3d/2in1/2p/verify-v3/3mf/pico_case_2inch_tft_58x28_verified_cn.3mf
3d/2in1/2p/verify-v3/pico_case_2inch_tft_58x28_verified_cn.scad
3d/2in1/2p/verify-v4/3mf/pico_case_2inch_tft_lcd_support1_boss3_typec_opposite.3mf
3d/2in1/2p/verify-v4/pico_case_2inch_tft_lcd_support1_boss3_typec_opposite.scad
3d/2in1/2p/verify-v5/pico_case_2inch_back_cover_bar_54mm_with_two_existing_boss_covers.scad
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

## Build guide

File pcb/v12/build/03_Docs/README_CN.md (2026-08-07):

# FPC10 + PWM 20×30 mm 转接板 V12

## V12：修正 Q1 栅极与源极焊盘
- 修正 Q1 同侧 1 脚（GATE）与 2 脚（SOURCE/GND）的物理焊盘位置。
- 使用两个过孔和一段底层走线完成 GATE 交叉，避免顶层短路或飞线。
- Q1 仍采用 AO3400A 标准电气编号：1=G、2=S、3=D。

## 延续 V11：适度加宽 FPC 10个信号焊盘

- FPC 顶视图从左往右固定为 **1～10脚**。
- 10个信号焊盘由 **0.35×2.30 mm** 适度加宽为 **0.45×2.30 mm**。
- 1.00 mm 脚距下，相邻信号焊盘铜间距仍为 **0.55 mm**，兼顾手工焊接与防连锡。
- FPC 信号焊盘钢网开口约为 **0.42×2.27 mm**，减少回流焊锡量。
- **FPC 1脚 = LED- / LEDK**，并连接 AO3400A 的漏极。
- **FPC 3脚 = GND**，对应原小板 LED- 旁边的 GND。
- J2 两排编号也按顶视图从左往右排列：上排 1～5，下排 6～10。
- 保留 FPC 第2脚串联 R3=25Ω。
- Q1、R1、R2、R3 分区布置，器件与走线之间留出更大空隙。
- FPC 两侧机械固定焊脚铜箔/阻焊开窗加大到 2.8×2.8 mm，钢网开口控制为 2.2×2.2 mm。
- SDO、SDA 与 6～10脚信号更多使用底层独立通道，减少顶层拥挤。
- PWM 电路仍只有 Q1、R1、R2；R3 属于 LEDA 串联电阻，不改变 PWM 栅极电路。

## 结构

- 板框：**20.00 × 30.00 mm**，双层。
- 固定孔：4 × **M2.2 非金属化孔**。
- J1：10P、1.0 mm、下接触 FPC，插入口朝 20 mm 板边；两侧固定焊脚为 2.8×2.8 mm。
- J2：2×5、2.54 mm 通孔，10 路按编号一一引出。
- J3：独立 `PWM / GND` 两针控制口。
- PWM 元件仍为：Q1=AO3400A、R1=100 Ω、R2=10 kΩ。
- LEDA 串联元件：R3=25 Ω（0603）。

## 引脚定义

| Pin | 名称 | 说明 |
|---:|---|---|
| 1 | LEDK / LED- | 背光负极，同时接 AO3400A 漏极 |
| 2 | LEDA | 背光正极，经 R3=25 Ω 后连接 J2 第2脚 |
| 3 | GND | 地，位于 LED- 旁边 |
| 4 | SDO | 屏幕串行输出，可不接 |
| 5 | SDA | SPI MOSI |
| 6 | CS | 片选 |
| 7 | DC | 数据/命令 |
| 8 | SCL | SPI 时钟 |
| 9 | RST | 复位 |
| 10 | VDD | 屏幕逻辑电源，按 3.3 V 使用 |

J3-1 为 3.3 V PWM 输入，J3-2 为 GND。

## 下单前检查

1. 在嘉立创顶层预览中确认 FPC 左端标记为 1，右端标记为 10。
2. 确认排线从板框上边插入，FPC 插座为 10P、1.0 mm、下接触。
3. 本板在 LEDA 上串联 R3=25 Ω，但它不等同于完整恒流驱动；首次上电仍建议使用限流电源并确认背光额定电流。
4. 建议首次只下单 5 片样板并限流上电。

## 文件

- `01_JLCPCB_Order/FPC10_PWM_20x30_V12_GERBER.zip`：嘉立创下单文件。
- `01_JLCPCB_Order/BOM_JLCPCB.csv`：SMT BOM。
- `01_JLCPCB_Order/CPL_JLCPCB.csv`：贴片坐标。
- `02_Source/FPC10_PWM_20x30_V12.kicad_pcb`：KiCad PCB 源文件。
- `03_Docs/preview_top.png`：顶层走线与正常方向丝印。
- `03_Docs/preview_bottom.png`：底层走线。
- `03_Docs/gerber_orientation_check.png`：Gerber CAM 顶视图检查。

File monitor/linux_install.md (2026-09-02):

# Linux 一键安装

本文提供 Pico Monitor 在常见 Linux 发行版上的一键安装命令。安装脚本来自 GitHub `master` 分支的 Raw URL，会自动识别当前系统使用的包管理器、安装运行依赖，并注册 `pico-monitor.service`。

> 安装过程需要写入 `/opt`、`/usr/local/bin` 和 `/etc`，请使用具有 `sudo` 权限的账号执行。生产环境建议先查看 [`install-linux.sh`](install-linux.sh) 内容，再运行远程脚本。

## Debian、Ubuntu、Linux Mint、Raspberry Pi OS

```sh
sudo apt-get update && sudo apt-get install -y curl && curl -fsSL https://raw.githubusercontent.com/tokyohost/pico-vision/master/monitor/install-linux.sh | sudo sh
```

## Fedora

```sh
sudo dnf install -y curl && curl -fsSL https://raw.githubusercontent.com/tokyohost/pico-vision/master/monitor/install-linux.sh | sudo sh
```

## RHEL、Rocky Linux、AlmaLinux

```sh
sudo dnf install -y curl && curl -fsSL https://raw.githubusercontent.com/tokyohost/pico-vision/master/monitor/install-linux.sh | sudo sh
```

## openSUSE Leap、Tumbleweed

```sh
sudo zypper --non-interactive install curl && curl -fsSL https://raw.githubusercontent.com/tokyohost/pico-vision/master/monitor/install-linux.sh | sudo sh
```

## Arch Linux、Manjaro

```sh
sudo pacman -Syu --needed --noconfirm curl && curl -fsSL https://raw.githubusercontent.com/tokyohost/pico-vision/master/monitor/install-linux.sh | sudo sh
```

## 使用 wget 安装

系统未安装 `curl`、但已安装 `wget` 时，可以执行：

```sh
wget -qO- https://raw.githubusercontent.com/tokyohost/pico-vision/master/monitor/install-linux.sh | sudo sh
```

## 安装验证

安装完成后执行：

```sh
pico-monitor --version
sudo systemctl status pico-monitor
```

实时查看运行日志：

```sh
sudo journalctl -u pico-monitor -f
```

配置文件位于 `/etc/pico-monitor.conf`。修改配置后执行以下命令使配置生效：

```sh
sudo systemctl restart pico-monitor
```

如果当前系统不使用 systemd，安装脚本只部署程序文件，不会注册开机服务。此时可以手动启动：

```sh
sudo pico-monitor --config /etc/pico-monitor.conf
```

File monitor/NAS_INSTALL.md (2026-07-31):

# OmniWatch NAS 安装说明

本文说明群晖、威联通和 TrueNAS 的支持版本、发布包选择、安装步骤与限制。

## 支持范围

| NAS 系统 | 支持版本 | 发布包 | 安装方式 |
|---|---|---|---|
| 群晖 DSM | DSM 7.2 及以上 | `OmniWatch-synology-noarch-v<版本>.tar.gz` | SSH 解压安装 |
| QNAP QTS | QTS 5.1 及以上 | `OmniWatch-qnap-noarch-v<版本>.tar.gz` | SSH 解压安装 |
| QNAP QuTS hero | h5.1 及以上 | `OmniWatch-qnap-noarch-v<版本>.tar.gz` | SSH 解压安装 |
| TrueNAS SCALE | 24.10 及以上 | `OmniWatch-truenas-noarch-v<版本>.tar.gz` | 自定义 Docker App 优先；宿主机安装仅用于测试 |
| TrueNAS CORE | 13.3 | 采集代码兼容 FreeBSD | 不提供生产安装包 |

发布包是与 CPU 架构无关的 Python 源码包，安装时在 NAS 本机创建虚拟环境。使用前应先从厂商应用中心安装 Python 3，并确保 `python3 --version` 为 3.10 或更高版本。

TrueNAS CORE 13.3 已把 Plugin、Jail 和虚拟机标记为停用且不再提供支持，因此不把 Jail 安装作为生产方案。需要长期运行时应迁移到 TrueNAS SCALE。

## 校验版本与摘要

下载与 NAS 对应的压缩包和 `OmniWatch-SHA256SUMS-nas.txt`，然后执行：

```sh
sha256sum -c OmniWatch-SHA256SUMS-nas.txt --ignore-missing
tar -xzf OmniWatch-synology-noarch-v1.0.0.tar.gz
cd OmniWatch-synology-noarch-v1.0.0
cat nas-package.json
```

`nas-package.json` 中的 `version` 是 Monitor 版本，`format` 是 NAS 包格式版本。运行版本可在安装后通过 `pico-monitor --version` 查看。

## 群晖 DSM

在“控制面板 → 终端机和 SNMP”中临时开启 SSH，通过管理员账号登录并切换为 root：

```sh
sudo -i
cd /volume1/下载目录/OmniWatch-synology-noarch-v1.0.0
chmod 0755 install-linux.sh
./install-linux.sh
```

DSM 提供 systemd 时安装脚本会注册并启动 `pico-monitor.service`。查看状态：

```sh
systemctl status pico-monitor
journalctl -u pico-monitor -f
```

安装完成并确认服务正常后，建议关闭 DSM SSH。系统大版本升级后应复查服务状态。

## QNAP QTS 与 QuTS hero

在“控制台 → 网络和文件服务 → Telnet/SSH”中临时开启 SSH，然后执行：

```sh
sudo -i
cd /share/Public/OmniWatch-qnap-noarch-v1.0.0
chmod 0755 install-linux.sh
./install-linux.sh
```

部分 QNAP 固件没有 systemd。此时脚本只安装程序，不修改 QNAP 的 `qpkg.conf` 或厂商启动配置，以免系统升级后产生无效配置。可先手动验证：

```sh
pico-monitor --version
pico-monitor --config /etc/pico-monitor.conf
```

需要开机启动时，应通过 QNAP App Center 支持的自动运行机制或管理员维护的启动脚本调用上述命令。升级 QTS/QuTS hero 后应重新确认 Python、USB 权限和启动项。

## TrueNAS SCALE

TrueNAS SCALE 24.10 及以上推荐通过“Apps → Discover → Custom App”运行第三方容器，不建议直接修改只读或由升级管理的宿主系统。容器需要：

- 使用 Host Network；
- 映射 `/dev` 中实际使用的 Pico USB 设备；
- 只读映射宿主 `/proc` 和 `/sys` 才能采集宿主指标；
- 为配置和运行数据挂载持久化数据集；
- 使用与发布版本一致的镜像标签或源码包版本。

直接运行 `install-linux.sh` 仅用于开发测试，而且 TrueNAS 升级可能清除宿主机改动。生产环境应制作基于该发布包的固定版本容器镜像，再通过 Custom App 安装。

## 配置与排错

配置文件位于 `/etc/pico-monitor.conf`。建议优先使用 Wi-Fi WebSocket 连接 Pico；USB 连接需要确认 NAS 能看到设备：

```sh
ls -l /dev/ttyACM* /dev/ttyUSB* 2>/dev/null
pico-monitor --version
pico-monitor --dev
```

CPU 温度、SMART 和 USB 串口通常需要 root 或等效设备权限。群晖、QNAP、TrueNAS 的系统升级都可能改变传感器路径或设备权限，升级后应检查日志和采集字段。

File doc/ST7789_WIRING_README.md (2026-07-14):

# RP2040、ESP32-S3 与 ST7789 LCD 完整接线说明

本文档分别说明八针 ST7789 屏、十针 ST7789 屏以及三枚公共按键的接线。
屏幕使用 SPI0 单向传输，不读取屏幕数据，因此无需连接 MISO。接线前必须先断开
Pico 的 USB 和外部电源。

## 屏幕方案选择

`picoRP2040/config.py` 只使用 `LCD_DEVICE_TYPE` 选择屏幕方案：

```python
# 二英寸八针屏
LCD_DEVICE_TYPE = "st7789-2inch-8pin-a"

# 二点四英寸八针屏
LCD_DEVICE_TYPE = "st7789-2.4inch-8pin-b"

# 二点四英寸十针屏
LCD_DEVICE_TYPE = "st7789-2.4inch-10pin-a"
```

每个屏幕的 GPIO、排针顺序、分辨率、色彩和背光方案均定义在
`picoRP2040/lcd` 目录下对应的屏幕档案中。

## 公共按键接线

三枚按钮固定使用 GP1、GP2、GP3。这组 GPIO 与当前所有八针屏、十针屏以及
GP22/GP25 板载状态灯均不冲突。

| 按键功能 | Pico GPIO | Pico 实体针脚 | 按键另一端 | 配置项 |
| --- | ---: | ---: | --- | --- |
| 上一样式 | GP1 | 2 | GND，可使用实体针脚 3 | `PIN_BUTTON_STYLE_PREVIOUS = 1` |
| 下一样式 | GP2 | 4 | GND，可使用实体针脚 3 | `PIN_BUTTON_STYLE_NEXT = 2` |
| 预留功能 | GP3 | 5 | GND，可使用实体针脚 3 | `PIN_BUTTON_FUNCTION = 3` |

按键输入使用内部上拉和低电平有效方式。未按下时 GPIO 为高电平，按下时按钮将
GPIO 接到 GND。三个按钮可以共用同一根 GND 线，不需要额外上拉电阻。

```text
Pico GP1（实体针脚 2） ---- 按钮：上一样式 ----+
Pico GP2（实体针脚 4） ---- 按钮：下一样式 ----+---- Pico GND（实体针脚 3）
Pico GP3（实体针脚 5） ---- 按钮：预留功能 ----+
```

## 八针屏接线

适用方案：

- `st7789-2inch-8pin-a`
- `st7789-2.4inch-8pin-b`

两种八针方案使用相同 GPIO，典型排针顺序为：

```text
GND, VCC, SCL, SDA, RES, DC, CS, BL
```

### 八针屏接线对照表

| 屏幕针脚 | 功能 | Pico 接口 | Pico 实体针脚 | 说明 |
| --- | --- | --- | ---: | --- |
| `GND` | 屏幕电源地 | GND | 例如 8、13、18、23、28、38 | 必须与 Pico 共地 |
| `VCC` | 屏幕电源 | `3V3(OUT)` | 36 | 默认按 3.3V 屏幕连接 |
| `SCL`/`SCK`/`CLK` | SPI0 时钟 | GP6 | 9 | 档案中的 `sck=6` |
| `SDA`/`MOSI`/`DIN` | SPI0 数据输出 | GP7 | 10 | 档案中的 `mosi=7`，不是 I²C SDA |
| `RES`/`RST` | 硬件复位 | GP15 | 20 | 档案中的 `rst=15` |
| `DC`/`A0` | 数据/命令选择 | GP14 | 19 | 档案中的 `dc=14` |
| `CS` | SPI 片选 | GP8 | 11 | 档案中的 `cs=8` |
| `BL`/`BLK` | 背光 PWM | GP26 | 31 | 高电平有效，支持亮度调节 |

### 八针屏完整接线图

```text
Raspberry Pi Pico                         八针 ST7789

GND，实体针脚 38       ----------------> GND
3V3(OUT)，实体针脚 36  ----------------> VCC
GP6，实体针脚 9        ----------------> SCL / SCK / CLK
GP7，实体针脚 10       ----------------> SDA / MOSI / DIN
GP15，实体针脚 20      ----------------> RES / RST
GP14，实体针脚 19      ----------------> DC / A0
GP8，实体针脚 11       ----------------> CS
GP26，实体针脚 31      ----------------> BL / BLK

GP1，实体针脚 2        ---- 上一样式按钮 ---- GND
GP2，实体针脚 4        ---- 下一样式按钮 ---- GND
GP3，实体针脚 5        ---- 预留功能按钮 ---- GND
```

八针屏背光档案会按照 `BOARD_MODEL` 自动选择。RP2040 在 GP26 输出 1 kHz PWM，
ESP32-S3 在 GPIO13 输出 1 kHz PWM，并将 Monitor 设置的一至一百亮度转换为占空比。

### ESP32-S3 八针屏接线

当 `BOARD_MODEL = "ESP32-S3"` 时，两种八针屏自动切换到 MicroPython `SPI(2)` 脚位：

| 屏幕针脚 | ESP32-S3 接口 | 档案字段 | 说明 |
| --- | --- | --- | --- |
| `GND` | GND | — | 必须与开发板共地 |
| `VCC` | 3V3 | — | 默认按 3.3V 屏幕连接 |
| `SCL`/`SCK`/`CLK` | GPIO12 | `spi_id=2, sck=12` | SPI 时钟 |
| `SDA`/`MOSI`/`DIN` | GPIO11 | `mosi=11` | SPI 数据输出，不是 I²C SDA |
| `RES`/`RST` | GPIO14 | `rst=14` | 硬件复位 |
| `DC`/`A0` | GPIO9 | `dc=9` | 数据/命令选择 |
| `CS` | GPIO10 | `cs=10` | SPI 片选 |
| `BL`/`BLK` | GPIO13 | `bl=13` | 高电平有效 PWM 背光 |
| 不连接屏幕 | GPIO15 | `miso=15` | 仅用于隔离旧版固件的默认 MISO，不接 LCD |

```text
ESP32-S3 DevKit                         八针 ST7789

GND                 ----------------> GND
3V3                 ----------------> VCC
GPIO12              ----------------> SCL / SCK / CLK
GPIO11              ----------------> SDA / MOSI / DIN
GPIO14              ----------------> RES / RST
GPIO9               ----------------> DC / A0
GPIO10              ----------------> CS
GPIO13              ----------------> BL / BLK
GPIO15              - - - - - - - - > 不连接屏幕，仅保留给 SPI MISO
```

ESP32-S3 档案默认使用 10 MHz SPI，以适配旧版 MicroPython 和杜邦线接线。GPIO15
必须保持悬空，不要与屏幕或其他外设连接。

这组映射避开 GPIO19/20 原生 USB、GPIO48 板载 WS2812，以及项目默认使用的
GPIO1/2/3 按键。若开发板未引出这些 GPIO，应在
`picoRP2040/lcd/profiles.py` 的 `create_eight_pin_board_profiles()` 中按实际板卡修改，
不能直接套用本表。

## 十针屏接线

适用方案：`st7789-2.4inch-10pin-a`。

十针屏排针顺序为：

```text
GND, RS, CS, SCL, SDA, RESET, VDD, GND, LED+, LED-
```

`RS` 等同于八针屏的 `DC`，`SCL` 等同于 SPI `SCK`，`SDA` 等同于 SPI
`MOSI`。两个 GND 都是电源地，建议都连接到 Pico GND。

### 十针屏接线对照表

| 排针序号 | 屏幕针脚 | 功能 | Pico 接口 | Pico 实体针脚 | 说明 |
| ---: | --- | --- | --- | ---: | --- |
| 1 | `GND` | 屏幕电源地 | GND | 例如 23 | 第一组地线 |
| 2 | `RS` | 数据/命令选择 | GP16 | 21 | 驱动内部映射为 `dc=16` |
| 3 | `CS` | SPI 片选 | GP17 | 22 | 档案中的 `cs=17` |
| 4 | `SCL` | SPI0 时钟 | GP18 | 24 | 档案中的 `sck=18` |
| 5 | `SDA` | SPI0 数据输出 | GP19 | 25 | 档案中的 `mosi=19` |
| 6 | `RESET` | 硬件复位 | GP20 | 26 | 档案中的 `rst=20` |
| 7 | `VDD` | 屏幕电源 | `3V3(OUT)` | 36 | 默认按 3.3V 屏幕连接 |
| 8 | `GND` | 屏幕电源地 | GND | 例如 28 | 第二组地线 |
| 9 | `LED+` | 裸背光正极 | 限流/恒流后的背光电源 | — | 电压和电流必须按屏幕规格确定 |
| 10 | `LED-` | 裸背光负极 | 外部 N-MOSFET 的 D 极 | — | 由 MOSFET 低端 PWM 调光 |

### 十针屏完整接线图

```text
Raspberry Pi Pico                         十针 ST7789

GND，实体针脚 23       ----------------> 1  GND
GP16，实体针脚 21      ----------------> 2  RS
GP17，实体针脚 22      ----------------> 3  CS
GP18，实体针脚 24      ----------------> 4  SCL
GP19，实体针脚 25      ----------------> 5  SDA
GP20，实体针脚 26      ----------------> 6  RESET
3V3(OUT)，实体针脚 36  ----------------> 7  VDD
GND，实体针脚 28       ----------------> 8  GND
限流/恒流背光电源       ----------------> 9  LED+
外部 N-MOSFET 的 D 极   ----------------> 10 LED-

GP1，实体针脚 2        ---- 上一样式按钮 ---- GND
GP2，实体针脚 4        ---- 下一样式按钮 ---- GND
GP3，实体针脚 5        ---- 预留功能按钮 ---- GND
```

十针裸背光档案使用 `LcdBacklightProfile.external_low_side(21)`。公共驱动仍在
GP21 输出 1 kHz PWM，但 GP21 只控制外部 MOSFET 的栅极，不连接 LED+ 或 LED-，
也不承担背光电流。Monitor 仍可使用与八针屏相同的亮度百分比接口。

### 十针裸背光 MOSFET 接线

建议使用可在 3.3V 栅极电压下可靠导通的逻辑电平 N-MOSFET，并按以下方式连接：

```text
                         按屏幕规格选择的限流/恒流电源
                                      |
                                      +----------> LED+

Pico GP21 PWM ---- 100~330Ω ----> G（栅极）
                                  |
                                 10kΩ
                                  |
                                 GND

屏幕 LED- ----------------------> D（漏极）
Pico GND ------------------------> S（源极）
Pico GND、屏幕 GND、背光电源 GND 必须共地
```

这里的 100～330Ω 是 MOSFET 栅极串联电阻，10kΩ 是栅极下拉电阻，用于确保 Pico
复位或尚未初始化时背光保持关闭。背光限流不能由这两个电阻代替。

### 十针裸背光采购清单

以下物料可以直接下单，数量包含少量焊接和损坏余量：

| 物料 | 建议规格 | 建议数量 | 购物平台搜索词 | 用途 |
| --- | --- | ---: | --- | --- |
| N 沟道 MOSFET | AO3400A，SOT-23，`RDS(on)` 明确支持 `VGS=2.5V` | 5 个 | `AO3400A 原装 SOT23` | 背光低端 PWM 开关 |
| SOT-23 转接板 | SOT-23 转 DIP，2.54mm | 2～5 个 | `SOT23 转直插 转接板` | 方便手工焊接和洞洞板安装 |
| 栅极串联电阻 | 220Ω、1/4W、1% | 10 个 | `220欧 1/4W 1% 电阻` | GP21 到 MOSFET G 极 |
| 栅极下拉电阻 | 10kΩ、1/4W、1% | 10 个 | `10K 1/4W 1% 电阻` | MOSFET G 极到 GND |
| 电阻包 | 1Ω～1kΩ、1/4W、1% 常用阻值包 | 1 包 | `1% 金属膜电阻包 1欧到1K` | 确认参数后选背光限流电阻 |
| 洞洞板 | 2.54mm 单面或双面 | 2～5 片 | `2.54 洞洞板` | 固定 MOSFET 和电阻 |
| 排针/端子 | 2.54mm 排针或螺丝端子 | 若干 | `2.54 排针 螺丝端子` | 连接 Pico 与屏幕 |
| 导线 | 细软硅胶线或杜邦线 | 1 组 | `杜邦线 硅胶线 26AWG` | 信号与电源连接 |
| 去耦电容 | 100nF 陶瓷 + 10µF 电解/陶瓷 | 各 5 个 | `100nF 10uF 电容包` | 放在背光驱动电源附近 |
| 万用表 | 带直流电流档 | 1 台 | `数字万用表 毫安档` | 测量背光电压和电流 |
| 可调恒流电源 | 具有 CC 模式，能从小电流起调 | 1 台 | `可调直流稳压电源 恒流 CC` | 首次点亮和确认额定电流 |

AO3400A 的生产商规格在 `VGS=2.5V` 时给出了最大导通电阻，因此适合由 Pico 的
3.3V GPIO 控制。若购买现成 MOSFET 模块，必须确认模块支持 3.3V 逻辑输入，并能
明确找到 G/D/S 或信号、负载和地端子；不要购买只标注“5V 触发”的模块。

如果不方便焊接 SOT-23，可以直接购买已经焊好 AO3400A 的小模块，但接线仍应是
GP21 控制 MOSFET、LED- 走负载端，而不是让模块从 GP21 获取背光电流。

以下物料暂时不要根据猜测下单：固定阻值的背光限流电阻、固定电流 LED 驱动器、
升压 LED 驱动器和背光电源。应先取得屏幕的背光额定电流、LED 总正向压降和串并联
结构。若卖家只能提供额定电压和额定电流，也足以继续选择驱动方案。

裸背光的供电电压、正向压降和额定电流必须从屏幕规格书获取：

```text
串联限流电阻 R ≈ (背光电源电压 - LED 总正向压降 - MOSFET 压降) / 目标电流
```

如果不知道 LED 串并联结构、总正向压降或额定电流，不要猜电阻值，也不要直接接
3.3V 或 5V；应使用可调恒流 LED 驱动器，从较小电流开始，并取得屏幕规格后再确定
最终电流。

## GPIO 占用汇总

| 功能 | 八针屏 | 十针屏 |
| --- | --- | --- |
| SPI 时钟 | GP6 | GP18 |
| SPI 数据 | GP7 | GP19 |
| 片选 | GP8 | GP17 |
| 数据/命令 | GP14 | GP16 |
| 复位 | GP15 | GP20 |
| 背光 PWM | GP26 直接控制模块 BL | GP21 仅控制外部 MOSFET 栅极 |
| 上一样式按钮 | GP1 | GP1 |
| 下一样式按钮 | GP2 | GP2 |
| 预留功能按钮 | GP3 | GP3 |

两套方案均不会占用 GP22 和 GP25，因此兼容 `rp2040_usb` 的 GP22 WS2812 状态灯，
也兼容 `rp2040_typec` 的 GP25 单色状态灯。

## 建议接线顺序

1. 断开 Pico USB 和所有外部电源。
2. 对照屏幕实际丝印确认八针或十针方案，不要只按照排针数量猜测。
3. 先连接屏幕 GND 和 VCC/VDD，确认屏幕要求为 3.3V。
4. 连接 SCL、SDA、CS、DC/RS 和 RESET。
5. 八针模块连接 BL；十针裸背光必须先完成限流/恒流与 MOSFET 驱动电路。
6. 将三个按钮分别连接 GP1、GP2、GP3，按钮另一端共接 GND。
7. 检查无短路、无错接后再连接 USB 上电。

## 常见问题

### 背光亮但没有图像

检查 SCL、SDA、CS、DC/RS 和 RESET。`SDA` 在这类 SPI 屏幕上表示 MOSI，不是
I²C SDA；驱动不需要 MISO。

### 屏幕完全不亮

八针屏检查 VCC、GND 和 BL；十针屏检查 VDD、两组 GND、LED+、LED-、限流/恒流
电路以及 MOSFET 的 G/D/S 方向，还要确认 GP21 PWM 与所有电源已经共地。

### 按钮没有响应

确认按钮使用 GP1、GP2、GP3，另一端接 GND。项目使用内部上拉，不应把按钮另一端
接到 3.3V。若 Pico 根目录已有旧的 `runtime_config.json`，还需确认其中没有保存旧的
按钮 GPIO 覆盖值。

### 图像闪烁或花屏

缩短 SPI 连接线并确保共地。必要时在对应屏幕档案的 `LcdPinProfile` 中把
`baudrate` 从 40 MHz 临时降低到 20 MHz 排查。

### 图像偏移或颜色不正确

显存偏移、RGB/BGR 顺序和反色模式均属于屏幕档案参数，不应通过改接 GPIO 解决。
应检查所选 `LCD_DEVICE_TYPE` 是否与实际屏幕批次一致。

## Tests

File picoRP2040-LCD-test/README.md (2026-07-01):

# RP2040 LCD 全屏刷新测试

将 `main.py` 复制到 Pico 根目录并重启。程序会在红色和蓝色之间持续切换，每次使用预生成条带写满完整的 240×320 RGB565 屏幕。

串口日志示例：

```text
LCD_FRAME:10:TIME=32120US:AVG=32205US:MIN=32098US:MAX=32411US:FPS=31.13
```

计时只包含设置全屏窗口和 SPI 写入 153,600 字节像素，不包含颜色生成、垃圾回收及日志输出。测试仅占用两个 40 行条带缓冲区，避免完整帧导致 RP2040 内存不足。

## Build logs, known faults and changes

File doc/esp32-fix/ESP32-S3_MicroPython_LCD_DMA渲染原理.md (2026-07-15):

# ESP32-S3 MicroPython LCD DMA 渲染原理

## 1. 设计目标

本方案保持 Python Style 是唯一界面扩展入口。开发者继续使用 `canvas.text()`、
`canvas.fill_rect()`、`canvas.line()` 等接口编写布局，不需要理解 ESP-IDF、DMA
描述符或 ST7789 SPI 事务。

原生代码只负责用户无需感知的像素搬运，不负责布局、数据格式化、脏区选择和
Style 生命周期。这样可以同时满足以下目标：

- 保留 MicroPython 界面开发的简单性。
- 保留现有内置和自定义 Style 的兼容性。
- 让 MicroPython 始终面对完整 RAM 画布，不再为每个条带重复执行样式绘制。
- 由 C 固件自动检测、记录和合并脏区，样式无需维护手工脏区清单。
- 使用两块内部 SRAM 条带缓冲提取非连续矩形，避免热路径动态分配。
- 避免 Python 渲染线程在每个 SPI 分块完成后重新竞争 GIL。
- 允许通过配置立即切回升级前的标准 `machine.SPI.write()` 路径。

## 2. 分层边界

```mermaid
flowchart TD
    STYLE["Python Style<br/>布局、格式化、脏区"] --> CANVAS["Canvas 公共接口"]
    CANVAS --> PY["Python Canvas 兼容实现"]
    CANVAS --> CC["fn_canvas C 图元加速"]
    PY --> BUFFER["完整 RGB565 RAM 画布<br/>240×320×2 字节"]
    CC --> BUFFER
    BUFFER --> RENDERER["Python DashboardRenderer<br/>每帧提交完整画布"]
    RENDERER --> SWITCH{"LCD_TRANSFER_BACKEND"}
    SWITCH -->|legacy| LEGACY["machine.SPI.write"]
    SWITCH -->|native_dma| DIRTY["C 瓦片哈希比较<br/>脏矩形合并"]
    DIRTY --> STRIP["内部 SRAM 条带 A/B<br/>交替提取矩形行"]
    STRIP --> DMAA["DMA 缓冲 A"]
    STRIP --> DMAB["DMA 缓冲 B"]
    DMAA --> SPI["SPI2 / ST7789"]
    DMAB --> SPI
    LEGACY --> SPI
```

以下部分继续使用 Python：

- Style 插件发现、加载和切换；
- 数据格式化和显示文本生成；
- Canvas 公共 API；
- 完整画布绘制、帧发布和性能统计；
- LCD 初始化、旋转、背光和截图流程。

以下部分由 `fn_lcd` 原生模块完成：

- 初始化时接收分辨率、显存偏移、SPI 和 GPIO 脚位方案；
- 分配两块内部 DMA RAM 和两块内部 SRAM 条带缓冲；
- 按瓦片比较完整画布，并记录、横向合并和纵向合并脏矩形；
- 从完整 Canvas 按行提取脏矩形，交替使用两块条带缓冲；
- 使用现有 `machine.SPI` 的设备句柄排队 DMA 事务；
- 等待事务完成并维护累计字节数与事务数。

## 3. 为什么不把 Style 改成 C

Style 的核心价值是表达界面意图，而不是搬运像素。把 Style 改成 C 会增加编译、
烧录和内存生命周期管理成本，也会破坏运行期插件能力。

当前性能数据中 Canvas 绘制约为几十至一百毫秒，而 LCD 路径曾达到一秒以上。
因此优化边界应停在 Canvas 图元和 LCD 传输后端，不应侵入 Style 层。

## 4. 旧传输路径

`legacy` 后端保留原有代码语义：

```python
self.spi.write(pixels)
```

ESP32 MicroPython 的硬件 SPI 驱动会把较大的缓冲区拆成最多 4092 字节的事务。
等待每笔事务完成时，驱动会释放 GIL；存在两个 Python 线程时，通信线程可能先
获得 GIL，使渲染线程在一次 `show_region()` 内反复等待。当前性能统计包围整个
`show_region()`，所以这些 GIL 等待也会累计到 `LCD_US`。

该路径的价值是兼容标准固件和提供可靠回退，不作为 ESP32-S3 的目标性能路径。

## 5. 原生 DMA 传输路径

`native_dma` 后端初始化两块 4092 字节内部 DMA 缓冲区和两块
`逻辑宽度 × LCD_STRIP_HEIGHT × 2` 的内部 SRAM 条带缓冲。4092 与当前
`machine.SPI` 总线默认单笔事务上限一致，不修改屏幕接线和 SPI 时钟。C 固件
另外在 PSRAM 保存已显示与待提交瓦片哈希，以及固定容量脏矩形表。

一次区域写入按以下顺序执行：

1. MicroPython 在完整 RGB565 画布上执行一次 `draw_visible()`。
2. `fn_lcd.dirty_regions()` 比较瓦片哈希并返回合并后的脏矩形。
3. Python 只为这些矩形设置 ST7789 列窗口、行窗口和显存写入命令。
4. C 固件从完整画布按行复制到条带 A/B，两块条带循环交替使用。
5. 每块条带再由 DMA 缓冲 A/B 分块排队；DMA 发送当前块时 CPU 准备下一块。
6. 所有矩形发送成功后提交待定哈希；任一事务失败则丢弃待定哈希，下一帧重试。

原生函数执行期间不调用 `MP_THREAD_GIL_EXIT`。这样能够保证一个区域内的 DMA
事务连续完成，不会在每个 4092 字节边界让另一个 Python 线程长期抢占。底层
FreeRTOS、Wi-Fi、USB 和中断任务不依赖 MicroPython GIL，仍可由系统调度。

## 6. 后端开关

`config.py` 提供：

```python
LCD_TRANSFER_BACKEND = "auto"
LCD_DMA_CHUNK_SIZE = 4092
LCD_STRIP_HEIGHT = 40
LCD_DIRTY_TILE_WIDTH = 16
LCD_DIRTY_TILE_HEIGHT = 8
RENDER_FRAME_POLICY = "latest"  # 也可设为 "block"
```

支持三种模式：

| 配置 | 行为 | 适用场景 |
| --- | --- | --- |
| `legacy` | 始终使用标准 `machine.SPI.write()` | 对照测试和紧急回退 |
| `native_dma` | 强制使用 `fn_lcd`，模块或内存异常直接报错 | 固件能力验收 |
| `auto` | 优先使用 `fn_lcd`，不可用时回退 `legacy` | 默认部署 |

也可以在设备根目录的 `runtime_config.json` 中覆盖：

```json
{
  "LCD_TRANSFER_BACKEND": "legacy"
}
```

切换后需要软重启，因为 DMA 缓冲和 LCD 设备在启动阶段创建。

`RENDER_FRAME_POLICY=latest` 会覆盖尚未消费的旧快照，只保留最新帧；`block` 在
待处理槽占用时阻塞发布者，保证不丢帧。同步回退模式天然阻塞。两种策略都不会
允许通信线程与渲染线程同时修改同一完整画布。

## 7. 启动与性能日志

启动时输出实际后端：

```text
BOOT:LCD_TRANSFER_BACKEND:NATIVE_DMA
```

开发模式帧日志增加：

```text
LCD_BACKEND=NATIVE_DMA
```

`auto` 回退后会显示 `LEGACY`，因此测试时应以日志中的实际值为准，而不是只看
配置文件。

## 8. 推荐对照测试

固定同一块屏幕、同一 Style、同一 Monitor 数据和 40 MHz SPI，分别采集至少
二十个稳定帧：

1. `legacy + SYNC`；
2. `native_dma + SYNC`；
3. `legacy + THREAD`；
4. `native_dma + THREAD`。

记录以下指标的平均值、P95 和最大值：

- `TOTAL`；
- `CANVAS`；
- `LCD`；
- `SCHEDULE`；
- `SLOWEST_REGION`；
- `DROPPED_FRAMES` 的增量。

如果 `native_dma` 生效，预期 `CANVAS` 基本不变，`LCD` 和
`SLOWEST_REGION` 显著下降。若 `LCD` 仍接近一秒，应继续核对实际 SPI 时钟、
供电、接线、区域字节数以及是否发生 `auto` 回退。

## 9. 约束与后续方向

- 当前 DMA 双缓冲容量受既有 SPI 总线 4092 字节单笔上限约束。
- 脏区精度由瓦片尺寸决定；默认十六乘八像素，在区域数量和额外传输间折中。
- 原生后端当前同步等待一个区域完成，不是完整的 CPU0 原生渲染任务。
- Style 中大量逐像素 Python 循环仍会反映在 `CANVAS_US`，应优先使用批量 Canvas API。
- 如果后续需要更大的 DMA 事务，应统一调整 SPI 总线 `max_transfer_sz`、内部 RAM
  预算和压力测试，不能只放大 Python 配置值。
- 不计划把 Style 改写为 C；后续优化仍应保持 Python Style API 稳定。

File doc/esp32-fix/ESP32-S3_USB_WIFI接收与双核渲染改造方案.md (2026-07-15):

# ESP32-S3 USB/WIFI 接收与双核渲染改造方案

## 1. 文档目标

本文面向 ESP32-S3 N8R8（8 MiB Flash、8 MiB Octal PSRAM）运行方案，目标是在保持 USB 优先、WIFI 自动接管和现有样式插件兼容的前提下，降低通信与 LCD 渲染相互阻塞造成的画面卡顿。

重点目标如下：

- USB/WIFI 接收和协议解析持续高效运行。
- LCD 渲染不再长时间占用通信主循环。
- 充分利用 ESP32-S3 双核、SPI DMA 和 8 MiB PSRAM。
- 时间显示按绝对秒边界稳定推进，降低 `15:57:37` 直接跳到 `15:57:39` 的概率。
- 渲染积压时优先显示最新状态，不回放已经过期的帧。
- RP2040 继续使用原有单循环方案，ESP32-S3 通过板型能力选择优化后端。

## 2. 当前实现分析

当前应用由一个 MicroPython 主循环协作推进以下工作：

1. 轮询 USB CDC 或 WIFI WebSocket。
2. 解析 PV1 和 JSON 数据。
3. 合并系统快照并推进本地时间。
4. 选择样式和脏矩形。
5. 绘制 Canvas 条带。
6. 通过 SPI 将条带写入 ST7789。
7. 每帧完成后执行垃圾回收。

当前方案已经采用接收优先和分片渲染，但仍存在以下抖动来源：

- ESP32-S3 每个主循环渲染批次允许占用约 50 ms，期间 Python 层接收轮询会暂停。
- 默认 `disk` 样式没有差异脏区选择器，只有时间变化时仍会刷新全部动态区域。
- 未收到新数据时使用强制刷新，绕过已有样式的差异脏区选择器。
- 下一次刷新时间按“本次提交时间加一秒”计算，延迟会逐次累积。
- 每帧结束立即执行 `gc.collect()`，垃圾回收停顿可能落在整秒边界附近。
- 渲染器只对快照根字典做浅拷贝，不适合未来直接在线程之间共享可变对象。

## 3. MicroPython 多线程约束

当前 ESP32 固件配置启用了 `MICROPY_PY_THREAD_GIL`。同时，`mpthreadport.c` 使用 `xTaskCreatePinnedToCore(..., MP_TASK_COREID)` 创建所有 MicroPython 线程，而 ESP32-S3 的 `MP_TASK_COREID` 为 CPU1。

因此，仅调用 `_thread.start_new_thread()` 存在以下限制：

- 主线程和渲染线程仍固定在 CPU1。
- Python 字节码受 GIL 约束，Canvas 的 Python 调度不能在两颗核心真正并行。
- 大块 SPI DMA 等待期间驱动会释放 GIL，可以获得一定的接收与写屏重叠，但不能视为完整双核渲染。

结论：Python 渲染线程适合验证任务边界和缓冲区所有权；真正利用另一颗核心，需要 ESP32-S3 专用原生 C 渲染任务。

## 4. 目标架构

```mermaid
flowchart LR
    USB[USB CDC] --> MAIN[CPU1：MicroPython 主线程]
    WIFI[WIFI/WebSocket] --> MAIN
    MAIN --> RX[PV1 与 JSON 解析]
    RX --> MODEL[双槽最新渲染模型]
    CLOCK[单调时钟] --> CLOCKBOX[高优先级时钟请求]
    MODEL --> WORKER[CPU0：原生渲染任务]
    CLOCKBOX --> WORKER
    WORKER --> PSRAM[PSRAM 帧缓存与静态缓存]
    PSRAM --> DMA[内部 RAM 双 DMA 缓冲]
    DMA --> LCD[SPI DMA 与 ST7789]
```

### 4.1 CPU1 通信主线程

通信主线程负责：

- USB/WIFI 通道选择、USB 抢占和断线恢复。
- 非阻塞读取、PV1 解包、JSON 解析和命令处理。
- 合并最新系统快照并维护版本号。
- 将不可变的扁平渲染模型发布到双槽邮箱。
- 处理按键、配置、升级、ACK 和性能数据。

通信主线程不直接访问 LCD、SPI、Canvas 和渲染缓冲区。

### 4.2 CPU0 原生渲染任务

原生渲染任务负责：

- 独占 LCD、SPI 和全部渲染状态。
- 执行样式显示命令、脏区合成和 RGB565 输出。
- 使用双 DMA 缓冲重叠“准备下一块”和“发送当前块”。
- 优先处理时钟脏区，在普通区域之间插入最新时钟刷新。
- 统计排队、Canvas、SPI、GC、丢帧和时钟延迟。

CPU0 同时承担 ESP-IDF WIFI 系统任务，渲染任务优先级必须低于 WIFI/LwIP 关键任务，禁止使用无让步的忙循环。

## 5. 时间刷新策略

### 5.1 使用绝对刷新边界

下一次刷新点必须根据校准时钟基准计算：

```text
下一次刷新点 = 校准 ticks + (已经过周期数 + 1) × 刷新周期
```

不能在每次提交后简单使用：

```text
下一次刷新点 = 当前 ticks + 1000 ms
```

绝对边界可以防止一次 30 ms 延迟永久叠加到后续每一秒。

### 5.2 时间区域独立为高优先级脏区

建议将请求划分为三个等级：

1. 时钟或页脚区域：最高显示优先级。
2. 最新系统快照：普通优先级。
3. 全屏刷新、静态背景重建：最低运行优先级。

时钟请求只保留最新一项。渲染任务不得依次回放过期秒数；当前区域或 SPI 事务完成后，应先处理最新时钟区域。

### 5.3 尽量在实际绘制前取时

主线程保存校准时间、校准 `ticks_ms` 和时区后缀。渲染任务在开始绘制时钟区域前计算当前 `HH:MM:SS`，避免队列等待后仍绘制旧时间。

## 6. 队列和缓冲区所有权

### 6.1 固定容量策略

- 系统快照使用两个固定渲染模型槽，采用 `latest wins`。
- 时钟请求使用一个固定槽，新请求覆盖旧请求。
- 样式切换、旋转和截图使用 4 至 8 项不可静默丢弃的控制队列。
- SPI 使用两个固定 DMA 缓冲区。

### 6.2 所有权状态

缓冲区状态统一为：

```text
FREE -> WRITING -> READY -> READING -> FREE
```

锁只保护槽位索引、状态和版本号。禁止在持锁状态下执行 Python 绘制、内存复制、SPI 等待或垃圾回收。

### 6.3 快照发布

线程之间不共享可变 Python 字典。主线程应把样式需要的数据复制到预分配的扁平模型，或编码为原生任务可直接消费的二进制显示命令。

## 7. PSRAM 与内部 RAM 规划

240 × 320 RGB565 完整帧占用 153,600 字节。建议内存规划如下：

| 用途 | 存放位置 | 建议容量 |
| --- | --- | ---: |
| 工作帧缓冲 | PSRAM | 153,600 B |
| 已显示参考帧 | PSRAM | 153,600 B |
| 当前样式静态背景 | PSRAM | 153,600 B |
| 常用样式静态背景缓存 | PSRAM | 0.5～1.5 MiB |
| 字形和文本位图缓存 | PSRAM | 256～512 KiB |
| 双槽渲染模型 | PSRAM | 32～128 KiB |
| USB 环形接收缓冲 | 内部 RAM 或 PSRAM | 64 KiB |
| WIFI 解帧环形缓冲 | PSRAM | 128 KiB |
| SPI DMA 双缓冲 | 内部 DMA RAM | 2 × 16/32 KiB |
| DMA 描述符和任务栈 | 内部 RAM | 按固件实测保留 |

应用主动缓存建议控制在 2～4 MiB PSRAM。空间换时间的重点是保存静态背景、完整帧、字形和预计算结果，不是占满全部 PSRAM。

第一版不直接从普通 MicroPython PSRAM 对象启动 DMA，而是使用“PSRAM 帧缓存 -> 内部 DMA 缓冲 -> SPI”的稳定路径。固件升级或 Flash 写入前必须暂停渲染并排空 DMA，因为 Flash 缓存关闭期间 PSRAM 可能不可访问。

## 8. 分阶段实施计划

### 第一阶段：单循环低风险优化

本阶段不引入线程，先消除已经确认的主要跳秒来源：

1. 为默认 `disk` 样式增加差异脏区选择器。
2. 空闲时钟刷新不再强制刷新全部动态区域。
3. 根据时间校准基准计算下一次绝对刷新点。
4. 将每帧强制 GC 改为带最小间隔和整秒保护窗口的安全 GC。
5. 保留现有接收优先、区域预算和异常回退机制。
6. 补充时钟边界、脏区选择和 GC 调度单元测试。

预期效果：默认样式每秒通常只发送页脚约 11,200 字节。40 MHz SPI 的理论传输时间约 2.24 ms，明显低于完整帧约 30.72 ms 的理论传输时间。

### 第二阶段：建立渲染服务边界

1. 引入 `RenderService` 和固定双槽邮箱。
2. LCD、SPI、Canvas 和样式状态由渲染服务单独持有。
3. 可先通过 Python `_thread` 验证生命周期、覆盖策略和异常恢复。
4. 利用 SPI DMA 等待期间释放 GIL，使通信主线程能够继续运行。

本阶段用于验证架构，不宣称实现 Python 绘制的真正双核并行。

#### 第二阶段实际实现

ESP32-S3 独有代码库已完成以下实现：

- 新增 `render_service.py`，由 `RenderService` 统一代理原有渲染器接口。
- 新增两个固定快照槽，主线程发布前递归复制字典、列表和元组，避免共享可变容器。
- 尚未消费的普通快照采用 `latest wins`，覆盖次数通过 `DROPPED_FRAMES` 上报。
- 新增八项固定控制队列，样式、旋转、背光、截图和渲染中止在渲染所有者线程同步执行。
- `DashboardRenderer`、Canvas、LCD 和 SPI 在工作线程创建或访问，主循环不再直接修改运行期 LCD 状态。
- 工作线程每轮只推进一个区域，以便及时处理控制命令并在 SPI DMA 等待时让通信主线程运行。
- 渲染完成通知携带原始快照版本，避免队列存在待处理帧时 ACK 错报较新的版本号。
- `_thread` 不可用或创建失败时自动建立同步渲染器，保持相同服务接口和现有异常恢复流程。
- 启动日志增加实际渲染模式，开发模式帧 ACK 增加 `RENDER_MODE` 和 `DROPPED_FRAMES`。

第二阶段仍属于 Python 线程架构验证。它能够隔离状态所有权并重叠部分 SPI 等待时间，但不改变 MicroPython GIL 和线程固定 CPU1 的固件约束。

### 第三阶段：ESP32-S3 原生双核渲染

1. 新增 ESP32-S3 用户 C 模块。
2. 使用 `xTaskCreatePinnedToCore()` 将原生渲染任务固定到 CPU0。
3. 实现固定邮箱、双 DMA 缓冲和 PSRAM 能力分配器。
4. 先迁移时钟文字、矩形、位图和 RGB565 复制等热点。
5. 将 Python 样式逐步转换为原生任务可执行的显示命令列表。
6. RP2040 保留现有后端，按板型选择渲染服务。

### 第四阶段：传输缓冲与长期稳定性

1. USB 和 WebSocket 改为预分配环形缓冲。
2. 消除 WebSocket 热路径的 `bytearray` 重建和切片复制。
3. 增加内部 RAM、PSRAM、最大连续块和任务栈余量监控。
4. 完成 USB/WIFI 切换、升级、截图和样式切换压力测试。

## 9. 验收指标

- 连续运行 1 小时，稳定场景下时间不出现加两秒跳变。
- 时钟区域提交相对绝对秒边界：P99 不超过 50 ms，最大不超过 150 ms。
- USB 持续传输时接收轮询间隔：P99 不超过 5 ms，最大不超过 20 ms。
- WIFI 持续传输时接收轮询间隔：P99 不超过 10 ms，最大不超过 30 ms。
- 40 MHz SPI 下时钟区域完整刷新小于 8 ms，全屏像素发送小于 60 ms。
- 连续运行 24 小时无 JSON 丢包、无持续队列增长和非预期 WebSocket 断线。
- WIFI 启用后内部 RAM 最大连续空闲块不少于 64 KiB。
- 性能日志至少包含 `RX_GAP`、`CLOCK_LATE`、`QUEUE_WAIT`、`CANVAS`、`SPI`、`GC` 和 `DROPPED_FRAME`。

## 10. 风险与回退

- 第一阶段只修改调度和脏区规则，可通过恢复原有强制刷新行为快速回退。
- Python `_thread` 不作为最终双核实现，避免依赖实验性线程行为。
- 原生任务不得直接持有未固定生命周期的 Python 对象。
- 样式切换、屏幕旋转和截图必须通过控制队列建立渲染屏障。
- 当原生渲染初始化失败时，应自动回退当前单循环 `DashboardRenderer`。
- 所有新增源码保持 UTF-8 无 BOM，类和方法必须提供规范中文注释。

## 11. 当前实施状态

- [x] 完成现状分析和阶段方案整理。
- [x] 开始实施第一阶段单循环低风险优化。
- [x] 建立 Python 渲染服务边界。
- [ ] 实现 ESP32-S3 原生双核渲染任务。
- [ ] 完成 USB/WIFI 长期压力测试和实机指标验收。

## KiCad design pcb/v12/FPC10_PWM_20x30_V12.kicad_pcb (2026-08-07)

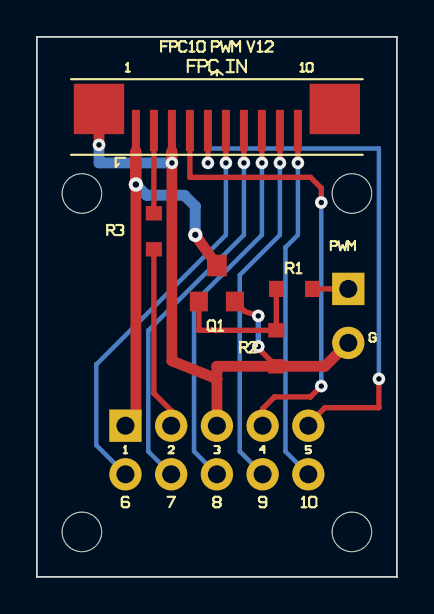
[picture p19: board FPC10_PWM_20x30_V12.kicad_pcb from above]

Board: 2 copper layers, 20.0 x 30.0 mm, 11 parts (0 on the bottom side), 13 nets.

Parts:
H1: M2.2; H1
H2: M2.2; H2
H3: M2.2; H3
H4: M2.2; H4
J1: F-FPC1M10P-C310; J1
J2: 2x5 2.54mm Breakout; J2
J3: PWM/GND; J3
Q1: AO3400A; Q1
R1: 100R; R1
R2: 10K; R2
R3: 25R; R3

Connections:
CS: J1.6, J2.6
DC: J1.7, J2.7
GATE: Q1.1, R1.2, R2.1
GND: J1.3, J1.MP1, J2.3, J3.2, Q1.2, R2.2
LEDA: J2.2, R3.2
LEDA_FPC: J1.2, R3.1
LEDK: J1.1, J2.1, Q1.3
PWM: J3.1, R1.1
RST: J1.9, J2.9
SCL: J1.8, J2.8
SDA: J1.5, J2.5
SDO: J1.4, J2.4
VDD: J1.10, J2.10

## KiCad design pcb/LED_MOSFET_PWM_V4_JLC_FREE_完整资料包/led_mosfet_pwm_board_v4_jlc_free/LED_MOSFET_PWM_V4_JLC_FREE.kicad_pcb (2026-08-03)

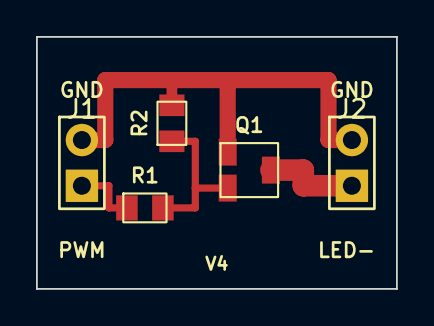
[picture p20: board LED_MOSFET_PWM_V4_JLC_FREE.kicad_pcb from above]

Board: 2 copper layers, 20.0 x 14.0 mm, 5 parts (0 on the bottom side), 4 nets.

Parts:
J1: CTRL; PinHeader_1x02_P2.54mm_Vertical
J2: LOAD; PinHeader_1x02_P2.54mm_Vertical
Q1: AO3400A; SOT-23
R1: 100R; R_0805_2012Metric
R2: 10K; R_0805_2012Metric

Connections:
GATE: Q1.1, R1.2, R2.1
GND: J1.2, J2.2, Q1.2, R2.2
LED_MINUS: J2.1, Q1.3
PWM: J1.1, R1.1

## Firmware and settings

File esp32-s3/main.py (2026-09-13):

#  Copyright (c) 2026 xuehui_li
#
#  Licensed under the Custom Non-Commercial Copyleft License.
#  Commercial use is prohibited without prior written permission.
#
#  Any project, software, or derivative work that uses, modifies, links to,
#  or incorporates this software must make its complete source code publicly
#  available under the same license.
#
#  This software is provided "as is", without warranty of any kind.



"""启动状态灯、多传输 JSON 接收和 LCD 异步刷新服务。"""


import gc
import sys
import time

try:
    import ujson as json
except ImportError:
    import json

from config import (
    CLOCK_REFRESH_INTERVAL_MS,
    GC_ALLOCATION_THRESHOLD,
    GC_CLOCK_GUARD_MS,
    GC_MIN_FREE_BYTES,
    GC_MIN_INTERVAL_MS,
    LCD_BOOT_PRELOAD_STYLES,
    LCD_STYLE,
    MONITOR_TIMEOUT_INTERVALS,
    RENDER_MAX_REGIONS,
    RENDER_TIME_BUDGET_US,
    STYLE_FRAME_WARNING_MS,
)
from protocol import JsonProtocol
from fatal_policy import CANVAS_CAPACITY_ERROR, should_restart_after_fatal


def memory_usage():
    """返回 MicroPython 堆内存的已占用字节数和总字节数。"""
    allocated = gc.mem_alloc()
    free = gc.mem_free()
    return allocated, allocated + free


def collect_memory_error_ram_status():
    """记录内存异常现场，并返回垃圾回收前后的 RAM 使用情况。"""
    allocated_before_gc = gc.mem_alloc()
    free_before_gc = gc.mem_free()
    total = allocated_before_gc + free_before_gc
    gc.collect()
    return (
        allocated_before_gc,
        free_before_gc,
        gc.mem_free(),
        total,
    )


def configure_garbage_collection():
    """关闭累计分配量触发的全堆回收，由应用按空闲内存水位调度。"""
    gc.collect()
    threshold = getattr(gc, "threshold", None)
    if callable(threshold):
        threshold(GC_ALLOCATION_THRESHOLD)
        return GC_ALLOCATION_THRESHOLD
    return None


class Application:
    """以通信主循环编排接收，并把 LCD 刷新委托给渲染服务。"""

    def __init__(self, protocol, transport=None, sdk_bootloader=None):
        """按通信、LED、LCD 的顺序初始化各组件。"""
        gc_threshold = configure_garbage_collection()
        from dashboard import DashboardRenderer
        from data_receiver import DataReceiver, SnapshotCache
        from lcd import create_lcd_device
        from render_service import RenderService
        from button_controller import ButtonController
        from buttonCommand import ButtonCommandDispatcher
        from led import create_led_controller

        self._protocol = protocol
        self._transport = transport
        self._sdk_bootloader = sdk_bootloader
        self._protocol.write(b"BOOT:PROTOCOL_READY\n")
        if gc_threshold is not None:
            self._protocol.write(
                "BOOT:GC_THRESHOLD:{}\n".format(gc_threshold).encode()
            )
        self._render_max_regions = RENDER_MAX_REGIONS
        self._render_time_budget_us = RENDER_TIME_BUDGET_US
        self._led = create_led_controller()
        self._led.start()
        self._protocol.write(
            "BOOT:BOARD_MODEL:{}\n".format(
                "esp32-s3"
            ).encode()
        )
        self._protocol.write(b"BOOT:LED_READY\n")
        self._lcd = create_lcd_device()
        self._lcd.initialize()
        self._protocol.write(
            "BOOT:LCD_DEVICE_TYPE:{}\n".format(
                self._lcd.device_type()
            ).encode()
        )
        self._protocol.write(
            "BOOT:LCD_COLOR_PROFILE:{}\n".format(
                self._lcd.color_profile_name()
            ).encode()
        )
        self._protocol.write(
            "BOOT:LCD_TRANSFER_BACKEND:{}\n".format(
                self._lcd.transfer_backend_name().upper()
            ).encode()
        )
        self._protocol.write(b"BOOT:LCD_READY\n")
        self._failed_custom_style = None
        self._renderer = RenderService(
            self._lcd,
            DashboardRenderer,
            style_name="boot",
        )
        render_threaded = self._renderer.start()
        self._protocol.write(
            "BOOT:RENDER_SERVICE:{}\n".format(
                "THREAD" if render_threaded else "SYNC_FALLBACK"
            ).encode()
        )
        self._protocol.write(
            "BOOT:RENDER_FRAME_POLICY:{}\n".format(
                self._renderer.frame_policy().upper()
            ).encode()
        )
        self._buttons = ButtonController()
        self._button_commands = ButtonCommandDispatcher()
        self._protocol.set_command_services({"renderer": self._renderer})
        self._boot_frame = 0
        self._boot_logs = []
        self._next_boot_animation = time.ticks_ms()
        self._show_boot(72, "BOOT:LCD_READY", "loading...", flush=True)
        self._preload_boot_styles()
        self._cache = SnapshotCache()
        self._show_boot(84, "BOOT:CACHE_READY", "loading...", flush=True)
        self._receiver = DataReceiver(self._protocol, self._cache, self._led)
        # 渲染控制等待期间也要持续消费 CDC 输入，防止主机在样式切换时
        # 把下一笔 JSON 分片写满 USB OUT 端点后永久背压。
        self._renderer.set_progress_callback(self._pump_protocol)
        self._show_boot(94, "BOOT:RECEIVER_READY", "loading...", flush=True)
        self._rendering_version = -1
        now = time.ticks_ms()
        self._next_clock_render = time.ticks_add(
            now, CLOCK_REFRESH_INTERVAL_MS
        )
        self._next_gc = time.ticks_add(now, GC_MIN_INTERVAL_MS)
        self._monitor_interval_ms = 500
        self._monitor_connected = False
        self._idle_enabled = True
        self._idle_style = "idle"
        self._idle_timeout_ms = 30000
        self._idle_active = False
        self._idle_wait_started_ms = now
        self._dev_mode = False
        self._button_style_override = None
        self._button_brightness_override = None
        self._button_brightness_dirty = False
        self._button_rotation_override = None
        self._button_network_unit_override = None
        self._last_display_style = LCD_STYLE
        self._last_display_brightness = None
        self._last_display_rotation = None
        self._last_display_network_unit = None
        self._button_hint_until_ms = None
        self._button_hint_snapshot = None
        self._button_hint_label = None

    def _pump_protocol(self):
        """在渲染控制等待期间轮询协议并缓存已收齐的最新快照。"""
        # 启动阶段的 _show_boot 可能早于 DataReceiver 创建；此时只推进渲染，
        # 不能因为通信泵浦尚未就绪而打断启动流程。
        receiver = getattr(self, "_receiver", None)
        if receiver is not None and receiver.update():
            self._idle_active = False

    def _preload_boot_styles(self):
        """在启动页阶段预加载大型样式，避免连接后首次编译造成内存峰值。"""
        preload_style = getattr(self._renderer, "preload_style", None)
        if not callable(preload_style):
            return
        style_count = len(LCD_BOOT_PRELOAD_STYLES)
        for style_index, style_name in enumerate(LCD_BOOT_PRELOAD_STYLES, 1):
            loading_log = "STYLE:LOADING:{}/{}:{}".format(
                style_index, style_count, style_name
            )
            try:
                self._protocol.write(
                    "BOOT:{}\n".format(loading_log).encode()
                )
                self._show_boot(
                    76,
                    loading_log,
                    "loading {}/{}...".format(style_index, style_count),
                    flush=True,
                )
                preload_style(style_name)
                self._protocol.write(
                    "BOOT:STYLE_PRELOADED:{}\n".format(style_name).encode()
                )
                self._show_boot(
                    80,
                    "STYLE:LOADED:{}".format(style_name),
                    "style ready {}/{}".format(style_index, style_count),
                    flush=True,
                )
            except (ImportError, MemoryError, TypeError, ValueError) as error:
                gc.collect()
                self._protocol.write(
                    "BOOT:STYLE_PRELOAD_ERROR:{}:{}\n".format(
                        style_name, error
                    ).encode("utf-8")
                )
                self._show_boot(
                    80,
                    "STYLE:FAILED:{}".format(style_name),
                    "style failed {}/{}".format(style_index, style_count),
                    flush=True,
                )

    def _write_custom_style_log(self, message):
        """向 Monitor 输出自定义样式启动加载结果。"""
        self._protocol.write(message.encode("utf-8"))

    def _show_boot(self, progress, log, status, flush=False):
        """提交启动画面，并可选择立即刷新其全部条带。"""
        if log and (not self._boot_logs or self._boot_logs[-1] != log):
            self._boot_logs.append(log)
            self._boot_logs = self._boot_logs[-4:]
        boot_snapshot = {
            "boot": {
                "progress": progress,
                "logs": self._boot_logs,
                "status": status,
                "wifi": self._boot_wifi_status(),
            }
        }
        self._renderer.request_render(boot_snapshot, force=True)
        if flush:
            while self._renderer.is_rendering():
                # flush 等待可能覆盖一次完整 LCD 刷新。即使只是等待渲染线程，
                # 主线程也必须持续进入 DataReceiver -> mp_usbd_task，
                # 否则 TinyUSB CDC OUT FIFO 会被填满并让主机 WriteFile 阻塞。
                self._pump_protocol()
                self._update_renderer_with_fallback(boot_snapshot)

    def show_application_error(self, error):
        """切换到错误页面，并把未处理异常的类型和信息直接显示到 LCD。"""
        error_type = type(error).__name__
        error_message = str(error) or "未知错误"
        self._renderer.abort_render(release_snapshot=True)
        self._renderer.set_style("boot")
        self._boot_logs = [
            "APPLICATION ERROR",
            "TYPE:{}".format(error_type),
            "MESSAGE:",
            error_message,
        ]
        self._show_boot(
            100,
            None,
            "ERROR - CHECK LOG",
            flush=True,
        )

    def _boot_wifi_status(self):
        """返回系统启动页固定展示的 Wi-Fi 状态。"""
        transport = getattr(self, "_transport", None)
        provider = getattr(transport, "wifi_status", None)
        if not callable(provider):
            return {"enabled": False}
        try:
            return provider()
        except (OSError, RuntimeError, ValueError) as error:
            return {
                "enabled": True,
                "available": False,
                "connected": False,
                "error": str(error),
            }

    def _set_style_after_system_boot(self, style_name):
        """先切换到系统启动页整理内存，再尝试加载指定样式。"""
        current_style = self._renderer.style_name()
        if style_name == current_style:
            return False
        from styles.style_plugins import style_exists
        if not style_exists(style_name):
            raise ValueError("STYLE_NOT_FOUND:" + str(style_name))
        if style_name == "boot":
            return self._renderer.set_style(style_name)
        self._renderer.set_style("boot")
        self._protocol.write(
            "CONFIG:LCD_STYLE_PREPARE:{}\n".format(style_name).encode("utf-8")
        )
        self._show_boot(
            100,
            "STYLE:PREPARE:{}".format(style_name),
            "loading style...",
            flush=True,
        )
        # 先释放上一样式和启动页刷新产生的短命对象，再导入可能较大的目标样式。
        gc.collect()
        changed = self._renderer.set_style(style_name)
        gc.collect()
        return changed or current_style != self._renderer.style_name()

    def _style_switch_candidates(self):
        """返回按键可循环切换的样式名称列表。"""
        try:
            from styles.style_plugins import style_catalog

            names = [
                item.get("name")
                for item in style_catalog()
                if isinstance(item, dict) and item.get("name") and not item.get("idle", False)
            ]
        except Exception:
            names = []
        if LCD_STYLE not in names:
            names.insert(0, LCD_STYLE)
        current_style = self._renderer.style_name()
        if current_style != "boot" and current_style not in names:
            names.insert(0, current_style)
        return tuple(name for name in names if name != "boot")

    def _neighbor_style_name(self, direction):
        """按方向返回当前样式在样式清单中的上一个或下一个名称。"""
        names = self._style_switch_candidates()
        if not names:
            return LCD_STYLE
        current_style = self._renderer.style_name()
        try:
            index = names.index(current_style)
        except ValueError:
            try:
                index = names.index(self._button_style_override)
            except ValueError:
                index = 0
        return names[(index + direction) % len(names)]

    def _apply_button_style(self, style_name, snapshot):
        """应用按键选择的样式，并强制下一帧完整刷新。"""
        if snapshot is None:
            self._protocol.write(b"BUTTON:LCD_STYLE_IGNORED:NO_SNAPSHOT\n")
            return
        try:
            changed = self._set_style_after_system_boot(style_name)
        except (ImportError, MemoryError, TypeError, ValueError) as error:
            if isinstance(error, MemoryError):
                self._failed_custom_style = style_name
                gc.collect()
            self._protocol.write(
                "BUTTON:LCD_STYLE_ERROR:{}:{}\n".format(
                    style_name, error
                ).encode("utf-8")
            )
            return
        self._button_style_override = self._renderer.style_name()
        self._rendering_version = -1
        self._renderer.request_render(snapshot or {}, force=True)
        if changed:
            self._emit_config_change(
                "lcd_style", self._renderer.style_name()
            )

    def _handle_button_actions(self, actions, snapshot):
        """使用命令分派器处理按下、长按和连发事件。"""
        self._button_commands.dispatch(actions, self, snapshot)

    def notify_style_button_event(self, button, event_type, snapshot):
        """向当前主题透传按键事件，并在主题消费事件后请求完整刷新。"""
        try:
            handled = self._renderer.dispatch_button_event(
                button, event_type, snapshot
            )
        except Exception as error:
            # 自定义主题监听器异常不能阻断按键默认命令和设备通信主循环。
            self._protocol.write(
                "BUTTON:STYLE_EVENT_ERROR:{}:{}:{}\n".format(
                    button, event_type, error
                ).encode("utf-8")
            )
            return False
        if handled:
            self._rendering_version = -1
            self._renderer.request_render(snapshot or {}, force=True)
        return handled

    def _emit_config_change(self, key, value):
        """通过通用 configChange 事件向 Monitor 同步配置变化。"""
        payload = json.dumps({"key": key, "value": value})
        self._protocol.write(
            "configChange:{}\n".format(payload).encode("utf-8")
        )

    def show_button_mode(self, label, snapshot):
        """显示功能键刚切换到的按键命令模式。"""
        self._show_button_hint("模式：{}".format(label), snapshot)

    def execute_style_command(self, direction, snapshot):
        """执行样式方向命令并显示切换结果。"""
        self._apply_button_style(
            self._neighbor_style_name(direction), snapshot
        )
        self._show_button_hint(
            "上一样式" if direction < 0 else "下一样式", snapshot
        )

    def execute_brightness_command(self, direction, snapshot):
        """按一个百分点步长调节本机背光，并记录待同步状态。"""
        current = self._renderer.backlight_brightness()
        brightness = max(1, min(100, int(current) + direction))
        changed = self._renderer.set_backlight_brightness(brightness)
        self._button_brightness_override = brightness
        if changed:
            self._button_brightness_dirty = True
        self._show_button_hint("亮度 {}%".format(brightness), snapshot)

    def commit_brightness_command(self):
        """在亮度按键释放后向 Monitor 同步一次最终亮度。"""
        if not self._button_brightness_dirty:
            return
        self._button_brightness_dirty = False
        self._emit_config_change(
            "lcd_brightness", self._renderer.backlight_brightness()
        )

    def execute_rotation_command(self, direction, snapshot):
        """上一键选择零度，下一键选择一百八十度。"""
        rotation = 0 if direction < 0 else 180
        self._renderer.set_rotation(rotation)
        self._button_rotation_override = rotation
        self._emit_config_change("screen_rotation", rotation)
        self._show_button_hint("旋转 {}°".format(rotation), snapshot)

    def execute_network_unit_command(self, direction, snapshot):
        """上一键选择 MB，下一键选择 Mbps 网络速率单位。"""
        unit = "MB" if direction < 0 else "Mbps"
        self._button_network_unit_override = unit
        self._emit_config_change("network_unit", unit)
        self._show_button_hint("网络单位 {}".format(unit), snapshot)

    def _show_button_hint(self, label, snapshot):
        """提交带按键名称的快照，并从本次按下起显示一秒。"""
        self._button_hint_snapshot = dict(snapshot or {})
        self._button_hint_label = label
        self._button_hint_until_ms = time.ticks_add(time.ticks_ms(), 1000)
        self._renderer.request_render(
            self._with_button_hint(snapshot), force=True
        )

    def _with_button_hint(self, snapshot):
        """为当前页面补充设备状态、按键配置覆盖和有效期内的提示。"""
        # 待机页的所有渲染入口都必须使用设备实时 Wi-Fi 状态。主循环除整秒
        # 待机刷新外还会提交普通快照；若直接使用上位机中的旧状态，两种快照
        # 会交替覆盖右上角连接标识，造成实际已连接却反复显示未连接。
        source_snapshot = (
            self._idle_snapshot(snapshot)
            if self._idle_active
            else snapshot
        )
        hint_snapshot = dict(source_snapshot or {})
        display = dict(hint_snapshot.get("display") or {})
        if self._button_network_unit_override is not None:
            display["network_unit"] = self._button_network_unit_override
        if display:
            hint_snapshot["display"] = display
        if self._button_hint_until_ms is not None and self._button_hint_label:
            hint_snapshot["button_hint"] = self._button_hint_label
        return hint_snapshot

    def _clear_button_hint_if_due(self, now, snapshot):
        """按键提示到期后重绘原始快照并清除提示状态。"""
        deadline = self._button_hint_until_ms
        if deadline is None or time.ticks_diff(now, deadline) < 0:
            return False
        restore_snapshot = snapshot
        if restore_snapshot is None:
            restore_snapshot = self._button_hint_snapshot
        self._button_hint_until_ms = None
        self._button_hint_snapshot = None
        self._button_hint_label = None
        self._renderer.request_render(
            self._with_button_hint(restore_snapshot), force=True
        )
        return True

    def _update_renderer_with_fallback(self, snapshot, receiver_busy=False):
        """按板型预算刷新区域，并在可恢复的渲染异常时降级。"""
        try:
            # 半包接收期间仍允许推进一个区域，避免残留半包长期饿死渲染；
            # 正常空闲时 ESP32-S3 使用软时间预算批量刷新以缩短整帧墙钟时间。
            max_regions = 1 if receiver_busy else getattr(
                self, "_render_max_regions", 1
            )
            time_budget_us = None if receiver_busy else getattr(
                self, "_render_time_budget_us", None
            )
            if time_budget_us is None:
                return self._renderer.update_pending(max_regions=max_regions)
            return self._renderer.update_pending(
                max_regions=max_regions,
                time_budget_us=time_budget_us,
            )
        except MemoryError as error:
            failed_style = self._renderer.style_name()
            self._protocol.write(
                "MEMORY:RENDER_RECOVERY:{}:{}\n".format(
                    failed_style, error,
                ).encode("utf-8")
            )
            # 放弃当前复杂帧，先释放其快照、脏区和字形缓存；显示启动页虽会
            # 变慢，但可继续处理 USB 数据，避免直接触发整机硬复位。
            self._renderer.abort_render(release_snapshot=True)
            gc.collect()
            self._renderer.set_style("boot")
            self._boot_logs = ["MEMORY:RECOVERED", "STYLE:{}".format(failed_style)]
            self._show_boot(100, None, "freeing memory...", flush=False)
            self._rendering_version = -1
            return False
        except ValueError as error:
            if (
                str(error) != CANVAS_CAPACITY_ERROR
                or self._renderer.style_type() != "custom"
            ):
                raise
            failed_style = self._renderer.style_name()
            self._failed_custom_style = failed_style
            self._protocol.write(
                "CUSTOM_STYLE:RENDER_FAILED:{}:{}\n".format(
                    failed_style, error,
                ).encode("utf-8")
            )
            self._renderer.set_style("default")
            self._renderer.request_render(snapshot, force=True)
            self._protocol.write(
                "CONFIG:LCD_STYLE_FALLBACK:{}:default\n".format(
                    failed_style,
                ).encode("utf-8")
            )
            return False
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

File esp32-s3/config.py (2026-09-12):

#  Copyright (c) 2026 xuehui_li
#
#  Licensed under the Custom Non-Commercial Copyleft License.
#  Commercial use is prohibited without prior written permission.
#
#  Any project, software, or derivative work that uses, modifies, links to,
#  or incorporates this software must make its complete source code publicly
#  available under the same license.
#
#  This software is provided "as is", without warranty of any kind.



"""集中定义 ESP32-S3 固件运行方案和通信协议参数。"""


# 固件仅面向 ESP32-S3，不允许通过运行配置切换为其他开发板。
BOARD_MODEL = "ESP32-S3"
# 开发源码使用 development；正式升级包由打包工具写入发布版本。
FIRMWARE_VERSION = "development"
# LCD 屏幕方案：具体分辨率、色彩、显存偏移和 GPIO 均由 lcd 目录中的档案定义。
LCD_DEVICE_TYPE = "st7789-2.4inch-10pin-a"


# LCD 通用刷新参数。
WIDTH = 240
HEIGHT = 320
# LCD 像素传输后端：auto 优先使用原生 DMA，旧固件缺少模块时自动回退 legacy。
LCD_TRANSFER_BACKEND = "auto"
# ESP32 machine.SPI 默认单笔事务上限为 4092 字节，原生后端使用等大的双缓冲。
LCD_DMA_CHUNK_SIZE = 4092
# C 固件使用两块内部 SRAM 条带缓冲交替整理完整画布中的脏矩形。
LCD_STRIP_HEIGHT = 40
# C 固件按瓦片检测完整画布变化，再把相邻瓦片合并为待发送脏矩形。
LCD_DIRTY_TILE_WIDTH = 16
LCD_DIRTY_TILE_HEIGHT = 8
# 新帧背压策略：latest 覆盖未消费旧帧，block 等待待处理槽释放。
RENDER_FRAME_POLICY = "latest"
# 未收到新 JSON 时仍使用缓存快照主动刷新的最大间隔，保证至少一帧每秒。
RENDER_INTERVAL_MS = 1000
# 单帧样式计算超过该阈值时输出 WARNING 性能日志。
STYLE_FRAME_WARNING_MS = 200
# 本地时间显示的固定刷新周期，独立于监控数据采集周期。
CLOCK_REFRESH_INTERVAL_MS = 1000
# 垃圾回收检查的最小间隔；有充足空闲内存时只检查水位，不扫描全堆。
GC_MIN_INTERVAL_MS = 5000
# Monitor 活跃期间仅在空闲内存低于此水位时回收，避免 8 MiB PSRAM
# 全堆扫描周期性阻塞协议解析和 JSON ACK。
GC_MIN_FREE_BYTES = 512 * 1024
# 距离下一次时钟刷新小于该窗口时延后主动垃圾回收。
GC_CLOCK_GUARD_MS = 100
# 每轮最多刷新的区域数，防止单次主循环长期占用通信处理。
RENDER_MAX_REGIONS = 16
# 每轮渲染的软时间预算；单个区域完成后才检查，因此允许少量超时。
RENDER_TIME_BUDGET_US = 50 * 1000
# 是否启用第二阶段 Python 渲染工作线程；失败时自动回退同步服务。
RENDER_SERVICE_THREAD_ENABLED = True
# 渲染线程每轮只推进一个区域，及时检查控制队列和最新快照。
RENDER_WORKER_MAX_REGIONS = 5
# 渲染线程栈需覆盖样式插件、字体和 Canvas 的较深调用链。
RENDER_WORKER_STACK_SIZE = 32 * 1024
# 样式切换、旋转和截图等不可丢弃控制命令的固定队列容量。
RENDER_CONTROL_QUEUE_CAPACITY = 8
# 渲染线程启动和同步控制命令的最长等待时间。
RENDER_SERVICE_START_TIMEOUT_MS = 5000
RENDER_CONTROL_TIMEOUT_MS = 15000
LCD_STYLE = "disk"
# 禁止按累计分配量自动触发不可预测的全堆 GC；应用按内存水位选择安全时机，
# 分配失败时 MicroPython 仍会执行一次兜底回收。
GC_ALLOCATION_THRESHOLD = -1
# 在系统启动页阶段预编译大型内置样式，避免连接后在碎片化堆上首次导入。
LCD_BOOT_PRELOAD_STYLES = ("horizontal_disk4x_qb",)


# JSON 数据包限制与单次读取预算。
MAX_JSON_SIZE = 16 * 1024
SERIAL_READ_BUDGET = 4096

# 后盖三按键使用 GP1、GP2、GP3，避开全部八针/十针 LCD 与两种板载状态灯。
# 按键默认一端接 GPIO、另一端共接 GND，并使用 ESP32-S3 内部上拉。
PIN_BUTTON_STYLE_PREVIOUS = 1
PIN_BUTTON_STYLE_NEXT = 2
PIN_BUTTON_FUNCTION = 3
BUTTON_ACTIVE_LOW = True
BUTTON_DEBOUNCE_MS = 0
BUTTON_LONG_PRESS_MS = 500
BUTTON_REPEAT_INTERVAL_MS = 60

# 板载状态灯公共时序参数。
LED_PIN = 48
LED_COUNT = 1
LED_BRIGHTNESS = 10
LED_ON_DURATION_MS = 200
LED_OFF_DURATION_MS = 1500
LED_DATA_PULSE_DURATION_MS = 100

# USB 串口协议参数。
DEVICE_NAME = "ESP32_S3_LCD"
LCD_DRIVER = "ST7789"
PIXEL_FORMAT = "RGB565"
MAX_UPGRADE_LINE_SIZE = 1024
# 内置 USB 控制台连续无活动达到该时长后释放当前会话。
USB_SESSION_TIMEOUT_MS = 5000
# 是否在原生 USB OTG 上注册保留 REPL 的独立 PV1 数据 CDC。
USB_DEDICATED_CDC_ENABLED = True
# 独立数据 CDC 的发送与接收环形缓冲区容量。
USB_CDC_TX_BUFFER_SIZE = 1024
# ESP-IDF 的 CDC 示例会及时读空 TinyUSB FIFO并投递到应用队列。这里的纯 Python
# CDC 也必须为业务解析、样式切换和渲染期间的突发数据保留至少两个最大 PV1 帧。
USB_CDC_RX_BUFFER_SIZE = 2 * (MAX_JSON_SIZE + 64)
# 是否启用 Wi-Fi 与 WebSocket 传输；设为 False 时完全不初始化无线网卡。
WIFI_ENABLED = True
# Wi-Fi WebSocket 服务参数；Monitor 默认连接 ws://设备IP:8765/pv1。
WEBSOCKET_PORT = 8765
WEBSOCKET_PATH = "/pv1"
# ESP32 主动发现公告参数：同时发送 UDP 组播与受限广播。
WIFI_DISCOVERY_ANNOUNCEMENT_ENABLED = True
WIFI_DISCOVERY_PORT = 37856
WIFI_DISCOVERY_MULTICAST_GROUP = "239.255.77.77"
WIFI_DISCOVERY_INTERVAL_MS = 2000
# 连续缺失多少个 Monitor 采集周期后返回系统启动等待页。
MONITOR_TIMEOUT_INTERVALS = 10
# 每接收多少份 Monitor 快照，使用主机时间重新校准一次本地推进基准。
TIME_CALIBRATION_SNAPSHOTS = 20
# 设备推进时间与主机运行时间的允许误差；误差不超过该值时保持原基准。
TIME_CALIBRATION_TOLERANCE_SECONDS = 2

# RGB565 调色板。
BLACK = 0x0000
WHITE = 0xE71C
GRAY = 0x5ACB
DARK = 0x18E3
BLUE = 0x1CBF
GREEN = 0x46E9
YELLOW = 0xFE00
PURPLE = 0x9ADF
RED = 0xF9C7
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

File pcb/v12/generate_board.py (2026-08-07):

from __future__ import annotations
import math, os, csv, json, shutil, zipfile
from dataclasses import dataclass
from pathlib import Path
from typing import List, Tuple, Dict, Optional

from shapely.geometry import Point, LineString, box
from shapely.ops import unary_union
import matplotlib.pyplot as plt
from matplotlib.patches import Rectangle, Circle

OUT = Path(__file__).resolve().parent / 'build'
GERBER_DIR = OUT / '01_JLCPCB_Order' / 'Gerber'
ORDER_DIR = OUT / '01_JLCPCB_Order'
SRC_DIR = OUT / '02_Source'
DOC_DIR = OUT / '03_Docs'
for d in [GERBER_DIR, ORDER_DIR, SRC_DIR, DOC_DIR]:
    d.mkdir(parents=True, exist_ok=True)

BOARD_W, BOARD_H = 20.0, 30.0
CLEARANCE = 0.20
EDGE_CLEARANCE = 0.25

NETS = {
    'GND': 1, 'LEDA': 2, 'LEDK': 3, 'SDO': 4, 'SDA': 5,
    'CS': 6, 'DC': 7, 'SCL': 8, 'RST': 9, 'VDD': 10,
    'PWM': 11, 'GATE': 12, 'LEDA_FPC': 13,
}

@dataclass
class Pad:
    ref: str
    num: str
    x: float
    y: float
    sx: float
    sy: float
    shape: str  # rect/circle
    net: Optional[str]
    kind: str   # smd/pth/npth/via
    drill: float = 0.0
    layers: Tuple[str, ...] = ('F.Cu',)
    paste: bool = False
    mask: bool = True

@dataclass
class Track:
    net: str
    layer: str
    width: float
    pts: List[Tuple[float,float]]

pads: List[Pad] = []
tracks: List[Track] = []

# ---- Board mechanical ----
# Fixed mechanical definition retained from V10.
HOLE_CENTERS = [(2.5,8.7),(17.5,8.7),(2.5,27.5),(17.5,27.5)]
for i,(x,y) in enumerate(HOLE_CENTERS,1):
    pads.append(Pad(f'H{i}','',x,y,2.2,2.2,'circle',None,'npth',2.2,('F.Cu','B.Cu'),False,True))

# ---- J1: 10P 1.0mm bottom-contact FPC ----
# Finished top view is explicitly left-to-right Pin 1 ... Pin 10.
fpc_nets = ['LEDK','LEDA_FPC','GND','SDO','SDA','CS','DC','SCL','RST','VDD']
for i,net in enumerate(fpc_nets):
    x = 5.5 + i
    pads.append(Pad('J1',str(i+1),x,5.20,0.45,2.30,'rect',net,'smd',0,('F.Cu',),True,True))
# Enlarged exposed copper anchor tabs for easier hand soldering.
# Copper/mask = 2.8 x 2.8 mm; paste is reduced separately to 2.2 x 2.2 mm.
pads.append(Pad('J1','MP1',3.45,4.00,2.80,2.80,'rect','GND','smd',0,('F.Cu',),True,True))
pads.append(Pad('J1','MP2',16.55,4.00,2.80,2.80,'rect',None,'smd',0,('F.Cu',),True,True))

# ---- J2: 2x5 2.54mm breakout ----
xs = [4.92,7.46,10.00,12.54,15.08]
for i,x in enumerate(xs,1):
    pads.append(Pad('J2',str(i),x,21.60,1.80,1.80,'rect' if i==1 else 'circle',
                    ['LEDK','LEDA','GND','SDO','SDA'][i-1],'pth',1.0,('F.Cu','B.Cu'),False,True))
for i,x in enumerate(xs,6):
    pads.append(Pad('J2',str(i),x,24.30,1.80,1.80,'circle',
                    ['CS','DC','SCL','RST','VDD'][i-6],'pth',1.0,('F.Cu','B.Cu'),False,True))

# ---- J3: independent PWM + GND input, using the right-side free area ----
pads.append(Pad('J3','1',17.30,14.00,1.80,1.80,'rect','PWM','pth',1.0,('F.Cu','B.Cu'),False,True))
pads.append(Pad('J3','2',17.30,17.00,1.80,1.80,'circle','GND','pth',1.0,('F.Cu','B.Cu'),False,True))

# ---- PWM and LED components, spread over the centre/right free area ----
# Q1 AO3400A: 1=G, 2=S/GND, 3=D/LED-.  V12 swaps the two
# same-side copper pads to match the verified physical device orientation.
pads.append(Pad('Q1','1',9.00,14.70,1.00,1.10,'rect','GATE','smd',0,('F.Cu',),True,True))
pads.append(Pad('Q1','2',11.00,14.70,1.00,1.10,'rect','GND','smd',0,('F.Cu',),True,True))
pads.append(Pad('Q1','3',10.00,12.70,1.10,1.20,'rect','LEDK','smd',0,('F.Cu',),True,True))
# R1 is separated from Q1 and J3, with a straight PWM path.
pads.append(Pad('R1','1',15.30,14.00,0.80,0.90,'rect','PWM','smd',0,('F.Cu',),True,True))
pads.append(Pad('R1','2',13.30,14.00,0.80,0.90,'rect','GATE','smd',0,('F.Cu',),True,True))
# R2 is vertical and clearly separated from R1/Q1.
pads.append(Pad('R2','1',13.30,16.30,0.90,0.80,'rect','GATE','smd',0,('F.Cu',),True,True))
pads.append(Pad('R2','2',13.30,18.30,0.90,0.80,'rect','GND','smd',0,('F.Cu',),True,True))
# R3=25R directly in the FPC Pin-2 LEDA path, using the left-centre corridor.
pads.append(Pad('R3','1',6.50,9.80,0.90,0.80,'rect','LEDA_FPC','smd',0,('F.Cu',),True,True))
pads.append(Pad('R3','2',6.50,11.80,0.90,0.80,'rect','LEDA','smd',0,('F.Cu',),True,True))

# ---- Vias ----
# LED- branch to Q1 drain goes on B.Cu, keeping it away from R3/GND routing.
pads.append(Pad('VL1','',5.50,8.20,0.80,0.80,'circle','LEDK','via',0.35,('F.Cu','B.Cu'),False,False))
pads.append(Pad('VL2','',8.80,11.00,0.80,0.80,'circle','LEDK','via',0.35,('F.Cu','B.Cu'),False,False))
# SDO changes layer near the right upper hole; SDA uses the far-right edge corridor.
pads.append(Pad('VSDO1','',15.80,9.20,0.70,0.70,'circle','SDO','via',0.30,('F.Cu','B.Cu'),False,False))
pads.append(Pad('VSDO2','',15.80,19.40,0.70,0.70,'circle','SDO','via',0.30,('F.Cu','B.Cu'),False,False))
pads.append(Pad('VSDA1','',9.50,7.00,0.70,0.70,'circle','SDA','via',0.30,('F.Cu','B.Cu'),False,False))
pads.append(Pad('VSDA2','',19.00,19.00,0.70,0.70,'circle','SDA','via',0.30,('F.Cu','B.Cu'),False,False))
pads.append(Pad('VGMP1','',3.45,6.00,0.70,0.70,'circle','GND','via',0.30,('F.Cu','B.Cu'),False,False))
pads.append(Pad('VGMP2','',7.50,7.00,0.70,0.70,'circle','GND','via',0.30,('F.Cu','B.Cu'),False,False))
# V12 source crossover: GATE stays entirely on F.Cu; a short local GND
# bridge on B.Cu lets Q1 pin 2 reach R2/J3 ground without crossing GATE.
pads.append(Pad('VQ1S1','',12.30,15.50,0.70,0.70,'circle','GND','via',0.30,('F.Cu','B.Cu'),False,False))
pads.append(Pad('VQ1S2','',12.30,17.20,0.70,0.70,'circle','GND','via',0.30,('F.Cu','B.Cu'),False,False))
# FPC pins 6..10 fan out to ordered bottom-layer corridors.
for idx, (x,net) in enumerate(zip([10.5,11.5,12.5,13.5,14.5], ['CS','DC','SCL','RST','VDD'])):
    pads.append(Pad(f'V{idx+1}','',x,7.00,0.70,0.70,'circle',net,'via',0.30,('F.Cu','B.Cu'),False,False))
    tracks.append(Track(net,'F.Cu',0.30,[(x,6.35),(x,7.00)]))
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

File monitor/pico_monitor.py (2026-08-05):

#!/usr/bin/env python3
"""Pico LCD 跨平台系统硬件监控程序兼容入口。"""

# Copyright (c) 2026 xuehui_li
#
# Licensed under the Custom Non-Commercial Copyleft License.
# Commercial use is prohibited without prior written permission.

import argparse
import ctypes
import logging
import signal
import sys
import runpy
from pathlib import Path

from build_info import GITHUB_REPOSITORY, MONITOR_VERSION
from monitor_update import LinuxDebUpdater
from monitor_core import arguments as _arguments
from monitor_core.arguments import (
    parse_monitor_arguments,
    validate_arguments,
)
from monitor_core.config import (
    config_flag,
    config_value,
    environment_flag,
    load_monitor_config,
    parse_collection_task_intervals,
)
from monitor_core.console import (
    _configure_standard_streams,
    _write_version_to_console,
    configure_logging,
)
from monitor_core.device import format_pico_information
from monitor_core.service import BUILTIN_LCD_STYLES, MonitorService
from monitor_core.tray_commands import start_tray_command_listener
from pico_client import PicoJsonClient

LOGGER = logging.getLogger("pico-monitor")


class MonitorVersionAction(argparse.Action):
    """输出兼容入口当前构建版本后结束命令行程序。"""

    def __call__(self, parser, namespace, values, option_string=None):
        """打印构建版本，并以成功状态退出参数解析。"""
        del namespace, values, option_string
        _write_version_to_console("pico-monitor {}".format(MONITOR_VERSION))
        parser.exit()
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

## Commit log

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2026-07-01 fix: 修复RP2040串口响应判断逻辑，优化LCD条带缓冲配置与数据接收
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2026-07-01 fix: 更新Linux构建流程，完善产物匹配与发布逻辑
2026-07-02 fix: 更新ST7789引脚配置，适配新硬件布局
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2026-07-02 fix: 移除横屏LCD样式支持，优化动态刷新与磁盘容量格式化逻辑
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2026-07-02 fix: 优化横屏样式逻辑，完善磁盘容量、温度与占用率渲染
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2026-07-02 fix: 增加上下箭头字符支持，优化网络速率与历史渲染逻辑，完善横屏样式文档
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2026-07-02 fix: 优化 LCD 显示切换逻辑，完善方向切换流程，修复区域刷新条件判定问题
    [dashboard.py, main.py, pico_monitor.py]
2026-07-02 fix: 优化动态区域刷新逻辑，修复差异检测与渲染完成状态更新问题
2026-07-02 fix: 优化 JSON 传输协议块逻辑，完善快照刷新与串口通信性能，增加大 JSON 支持与相关测试
    [config.py, dashboard.py, main.py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]
2026-07-02 fix: 优化网络速率字符限制逻辑，完善单位处理与超限显示方案，调整上下行显示布局
2026-07-02 fix: 修正横屏磁盘样式标题文本，由 "STORAGE OVERALL" 改为 "DISK OVERALL"
2026-07-02 fix: 增加版本标签校验逻辑，修正 Debian 版本生成方案，完善错误提示
2026-07-02 fix: 优化开发模式逻辑，停止串口重试，完善 JSON 输出与采集间隔配置
    [pico_monitor.py]
2026-07-02 fix: 修复能耗目录遍历逻辑，避免重复计数并完善符号链接支持，更新相关测试
2026-07-02 fix: 优化 Linux 磁盘与温度采集逻辑，完善物理磁盘解析与 SMART 支持，更新相关测试和文档
    [pico_2inch_tft_minimal_landscape_case.scad, pico_2inch_tft_minimal_landscape_case.stl, usb_rp2040_4m_dongle_case_v2.scad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]
2026-07-03 fix: 增加网络总流量统计字段，完善实时速率计算逻辑，更新相关文档与测试
2026-07-03 fix: 增加磁盘读写速率与历史统计，完善名称压缩逻辑，更新相关文档与测试
2026-07-03 fix: 增加紧凑点阵字体支持，完善横屏六磁盘样式与步进逻辑，更新相关文档与测试
2026-07-03 fix: 增加多边形填充支持，优化趋势图填充逻辑，完善横屏六磁盘样式
2026-07-03 fix: 优化多边形填充逻辑，增加失败回退处理，完善画布内存管理
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2026-07-03 fix: 增加磁盘 SMART 健康检查功能，完善 Linux/Windows 系统支持，更新文档与测试
    [system_monitor.py]
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2026-07-03 fix: 增加磁盘热插拔检测功能，重置 SMART 与健康缓存逻辑，更新相关文档与测试
    [system_monitor.py]
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2026-07-03 fix: 增加 GPU 监控与采样功能，完善横屏四磁盘样式与健康告警逻辑，更新相关文档与测试
    [pico_monitor.py, system_monitor.py]
2026-07-03 fix: 增加跨平台 GPU 使用率采集功能，优化监控后台采样逻辑，更新相关文档与测试
    [system_monitor.py]
2026-07-03 fix: 增加 qBittorrent 指标采集与状态汇总功能，完善横屏四磁盘样式，更新相关配置、文档与测试
    [pico_monitor.py, qbittorrent_monitor.py]
2026-07-03 fix: 增加 qBittorrent 连接状态支持，优化网络详情与趋势显示逻辑，更新相关配置、文档与测试
    [qbittorrent_monitor.py]
2026-07-03 fix: 增加 Pico 串口升级功能，更新相关构建、配置、文档与测试
    [config.py, main.py, pico_monitor.py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]
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2026-07-03 fix: 增加本地主动升级测试文档支持，优化 qBittorrent 参数默认值处理逻辑
    [pico_monitor.py]
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2026-07-03 fix: 增加 DEB 安装升级 Pico 支持，优化升级协议块处理与相关测试
    [pico_upgrade.py]
2026-07-03 fix: 增加 Linux DEB 自动更新功能，更新相关逻辑、测试、文档与构建配置
    [monitor_update.py, pico_monitor.py]
2026-07-03 fix: 添加自定义非商业 Copyleft 协议 LICENSE 与 LICENSE_ZH 文件
2026-07-03 fix: 添加项目源码文件版权声明，更新至自定义非商业 Copyleft 协议
    [canvas.py, config.py, dashboard.py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]
2026-07-03 fix: 添加简洁横屏 LCD 样式，更新样式注册、默认值配置与测试验证
    [pico_monitor.py]
2026-07-03 fix: 添加 LCD 样式文档，详述样式选项、注册与健康等级解释
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2026-07-03 fix: 添加高密度横屏磁盘样式 diskv3 和 diskv4、紧凑横屏样式 horizontal_diskv2，更新文档、样式注册与默认配置
    [pico_monitor.py]
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2026-07-03 fix: 修复 USB REPL sys.stdin 轮询兼容性问题，优化二进制读取逻辑
    [protocol.py]
2026-07-03 fix: 优化 USB 串口读取逻辑，避免 Linux USB CDC 阻塞并减少内存分配
    [protocol.py]
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2026-07-04 fix: 增加 ST7789 接线文档与屏幕色彩配置支持，优化 LCD 初始化逻辑
    [color_manager.py, config.py, main.py]
2026-07-04 fix: 重构 LED 控制逻辑，添加多开发板支持与状态灯策略模式，优化代码结构
    [board_manager.py, config.py, controller.py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]
2026-07-04 fix: 增加多开发板 LED 控制与屏幕配置支持，优化握手协议与升级逻辑
    [config.py, pico_client.py, pico_monitor.py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]
2026-07-04 fix: 增加 USB 端口变化检测逻辑，优化设备重连与异常处理
    [pico_client.py, pico_monitor.py]
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2026-07-04 fix: 针对 Linux CDC 调整： 逻辑 PING 包仍是完整 64 字节。 实际按 63 + 1 两次写入并分别刷新。 Linux 能获得短 USB 包边界。 Pico 的 readinto(64) 最终仍能读满，不会等待。 日志新增计划长度、实际长度、repr 和十六进制内容。
    [pico_client.py]
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2026-07-04 Revert "test: 1"
    This reverts commit 44449e8a703f92c8966e4da847b560050cc0bd35.
    [pico_client.py]
2026-07-04 test: fix memory allocation
    [config.py, main.py, pico_client.py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]
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2026-07-06 fix: 优化 USB CDC 注册逻辑，增加异常处理以避免通信通道不可用
    [2英寸螺柱降低版2026-7-6 v4.3mf, pico_case_2inch_tft_lcd_support1_boss3_typec_opposite.3mf]
2026-07-06 fix: 调整 SERIAL_WRITE_CHUNK_SIZE 值以修复潜在边界问题
    [pico_client.py]
2026-07-06 feat: 添加日志导出功能，支持导出最近 1 MB 日志并修正 UTF-8 截断问题
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2026-07-07 fix: 增强 GPU 数据采集逻辑，支持显存和温度读取；优化 CPU 频率显示，修复多个样式绘制边界问题
    [pico_monitor.py, system_monitor.py]
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2026-07-07 fix: 增强 CPU 频率显示逻辑，添加并行串口探测与设备管理，修复设备管理窗口响应问题，优化 Windows 窗口布局与样式
    [pico_client.py, pico_monitor.py, system_monitor.py]
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2026-07-07 fix: 同步构建制品到文档仓库，支持 Pico 升级包、Windows 制品和 Linux 制品
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2026-07-07 fix: 更新 GitHub Actions 自动发布文案，优化描述内容
2026-07-07 fix: 修复 JsonProtocol 测试缺少 dedicated_stream 属性的问题，完善测试用例
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2026-07-07 fix: 优化自动发布流程，添加完整 Git 提交日志生成支持
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2026-07-07 feat: 新增自定义数据管理功能，支持加载、校验、执行和结果缓存，完善 UI 操作入口与弹框逻辑 fix: 使用安装包替代直接替换 EXE 的更新方式，优化更新流程和日志记录 fix: 修改 Pico 升级包命名格式，将统一命名为 OmniWatch-*，完善发行说明与构建脚本 fix: 调整 Windows 安装包构建脚本，更新 README 和工作流说明
    [custom_data.py, monitor_update.py, pico_monitor.py]
2026-07-07 fix: 重命名 Windows 安装包为 OmniWatch-*-setup.exe，更新相关代码、文档和测试用例
    [pico_client.py, pico_monitor.py]
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2026-07-07 fix: 修复 Pico 串口关闭时的异常处理，改进安全性并完善相关测试用例
    [pico_client.py, pico_monitor.py]
2026-07-07 fix: 更新 Windows 安装包命名格式为带版本号形式，修改相关代码、测试用例、文档及构建脚本
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2026-07-08 fix: 修复开发模式切换逻辑，避免强制重启后台进程并支持即时生效
    [2英寸间距修复版2026-7-8 v6.3mf, pico_case_typec_forward_1mm_bosses_to_bar_5mm.3mf]
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2026-07-08 fix: 重构配置逻辑，切换为 YAML 配置格式并兼容旧版环境变量，优化任务标识与日志输出
    [pico_monitor.py]
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2026-07-08 fix: 优化错误日志处理逻辑，避免测试污染全局日志处理器 fix: 调整测试依赖加载顺序，防止伪依赖影响后续测试
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2026-07-08 fix: 调整 CPU 图绘制逻辑，支持按负载等级填充面积并修正测试预期
2026-07-08 fix: 修复 Pico JSON 缓存重连问题，完善 BAD_JSON 与内存错误测试案例
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2026-07-09 fix: 优化 Windows SensorHost 可用性检测与路径解析逻辑，添加缺失依赖原因提示并改进测试覆盖
2026-07-09 fix: 优化 SensorHost 优先级判定逻辑，新增指标可用性标记与状态缓存机制，改进启动延迟与预热期处理
    [system_monitor.py]
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2026-07-09 fix: 提升 SensorHost 版本检测优先级，优化可执行文件路径解析与管理员权限提示机制
    [pico_monitor.py]
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2026-07-09 fix: 优化硬件采集任务共享缓存与失败退避逻辑，新增 SensorHost 优先级判断及 Windows 磁盘相关任务
    [qbittorrent_monitor.py]
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2026-07-10 fix: 补全 CPU 频率获取逻辑，添加硬件传感器兜底支持及旧方法降级处理
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2026-07-10 fix: 调整 2.4 寸 IPS 屏幕外壳设计，优化屏幕螺柱避让结构及右侧三按键布局
    [2.4寸_ST7789_后盖三按键_配套8mm键帽版.scad, 2.4寸_右侧三按键_屏幕螺柱避让开窗优化版.3mf, 2.4寸_右侧三按键_屏幕螺柱避让开窗优化版.scad]
2026-07-10 fix: 移除 picoRP2040 LCD 驱动，添加 2.4 寸裸屏外壳 OpenSCAD 设计文件
    [pico_case_2.4inch_10pin_deeper_screen_recess_cn.scad, pico_case_2.4inch_single_side_clamp_equal_bezel_cn.3mf, pico_case_2.4inch_single_side_clamp_equal_bezel_c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]
2026-07-10 fix: 增加裸背光采购清单与 MOSFET PWM 板 BOM，补充相关文档与资料包
2026-07-10 fix: 添加 monitor 安装脚本文件补全与依赖更新，加强多平台任务支持
2026-07-10 fix: 优化 JSON ACK 逻辑与缓存淘汰机制，完善服务停止条件与按键控制模拟
2026-07-10 fix: 补全 Linux 安装清单与脚本中缺失的模块，新增相关测试验证
2026-07-10 fix: 支持自定义数据路径配置，调整 Linux 服务状态目录与环境变量，补充相关测试
    [custom_data.py]
2026-07-10 fix: 添加 Intel i915 GPU 性能指标采集支持，补充相关测试和文档修改
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2026-07-13 feat: 添加局域网 WebSocket 服务发现支持，优化设置项与多单元测试,修复windows 内存读取错误
    [canvas.py, canvasC.py, config.py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]
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2026-07-14 fix: 删除 Fusion Pixel 字库与相关脚本、测试 feat: 添加 WebSocket 与传输管理器测试, 新增日志控制选项优化任务日志
    [canvas.py, canvasC.py, config.py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]
2026-07-14 fix/feat: 添加 ESP32-S3 USB 传输优化及 CDC 框架功能，新增 JSON ACK 支持与超时处理逻辑
    [pico_client.py]
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2026-07-15 feat: 更新设备管理窗口及样式优化
    - 增加设备连接方式与连接地址的显示支持
    - 实现连接方式与地址的格式化工具函数
    - 优化设备探测逻辑，补充 Wi-Fi 属性支持
    - 更新游戏监控样式，拆分功耗显示及增加历史图
    - 修复 `_history` 方法填充逻辑，增强绘图灵活性
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2026-07-24 fix: 优化界面样式与语言描述，增强用户体验
    - 更新多处界面提示语，移除冗余信息，优化文案表述
    - 替换深色表格样式为主题化表格，提升可读性及一致性
    - 添加滚动条样式及加载组件的统一设计
    - 改进自定义数据插件管理，加入环境安装及依赖检测逻辑
    - 扩展设备 SDK 更新检查，支持多类别与资源匹配验证
    - 优化 `StylesPage` 样式详情功能，增加预览及键盘导航
2026-07-24 fix: 增强 ESP32-S3 待机界面样式及 MicroPython 兼容支持
    - 新增 MicroPython 原生代码装饰器的跨解释器兼容模块
    - 调整待机日志字体配置，统一引用 `LOG_FONT_NAME`
    - 优化日志文本样式，改为全大写提高可读性
2026-07-24 fix: 优化界面样式与功能，改善用户体验
    - 更新多处界面提示文案，精简描述，移除冗余信息
    - 添加自定义屏幕样式教程链接及样式滚动条主题
    - 调整表格及布局样式，提升表格可读性及排版一致性
    - 优化更新页面，新增固件和 SDK 更新确认提示及进度展示
    - 增强 Web UI 图标支持，统一加载及转换图标格式
2026-07-24 fix: 调整 ST7789 2.4 寸屏幕外壳设计及固定方案
    - 修正显示凹槽位置与裸屏中心偏移问题，偏移距离增加 1mm，总偏移 2.92mm
    - 优化对侧插片卡槽和 +Y 螺丝侧设计，增强屏幕固定稳定性
    - 更新 Type-C 开孔与接口压盖设计，改进限位和安装便捷性
    - 调整外壳整体尺寸至 50 x 72.4mm，改进边框对称性
    - 优化结构参数输出和设计校验逻辑
    [ST7789_2.4_ESP32S3_外壳_FPC侧槽位再移1mm.3mf, ST7789_2.4_ESP32S3_外壳_FPC侧槽位再移1mm.scad]
2026-07-24 fix: 添加强制 USB-CDC 支持，修复相关处理逻辑和界面适配
    - 增加 `--force-usb-cdc` 参数，支持强制使用 USB-CDC 连接并停止 WebSocket 搜索
    - 在配置文件和界面中新增 `force_usb_cdc` 设置项及持久化逻辑
    - 调整 WebSocket 连接逻辑，避免强制 USB-CDC 时重复扫描和探测
    - 优化设备更新界面，新增更新任务进度、状态和实时日志显示
    - 修复多处串口设备检测及任务重连过程中的细节问题
    [config.py, main.py]
2026-07-24 fix: 增加主动设备探测支持，优化连接保持及错误处理
    - 新增 `_request_device_probe` 方法，支持常驻监控主动探测设备并保留连接
    - 优化握手阶段逻辑，防止探测期间握手成功后触发意外重连
    - 更新设备探测相关测试，覆盖常驻进程交互及多连接场景
    - 简化独立探测逻辑，改为调用常驻工作进程以增强稳定性
2026-07-24 fix: 添加 SDK Bootloader 支持，优化主循环安全点切换逻辑
    - 引入 `SdkBootloaderController`，支持主循环安全点 USB 切换
    - 调整 Bootloader 相关命令逻辑，改为通过安全点控制释放
    - 优化主动探测逻辑，增强设备重连及错误处理能力
    - 添加多个测试，涵盖安全点切换及设备探测场景
    - 更新相关界面与日志提示，改进用户操作反馈
    [main.py]
2026-07-24 fix: 移除整秒同步逻辑，兼容旧接口并优化 DMA 刷新策略
    - 调整 `NATIVE_DMA_API_VERSION` 为 2，强化旧版本兼容性
    - 移除整秒帧同步路径，新增异常处理防止静默恢复
    - 更新相关测试逻辑，优化脏区域合并与连续 DMA 处理
    - 精简原生接口使用，移除未使用的异步任务及同步方法
2026-07-25 fix: 添加按键提示功能，优化界面交互与设备重连逻辑
    - 新增按键操作时的提示框逻辑，提升用户操作反馈
    - 调整设备重连条件，优化运行时配置热更新处理
    - 更新渲染逻辑，支持按键提示的动态显示
    - 添加 PCB Layout 文件 `FPC10_PWM_20x30_V8`，完善硬件设计
    [FPC10_PWM_20x30_V8.kicad_pcb, ST7789_ESP32S3_外壳_按键后移_取消尾部螺柱_PCB短边朝FPC_V4.scad]
2026-07-25 fix: 增强屏幕样式管理与按键事件处理逻辑
    - 更新按键去抖时间逻辑，支持禁用去抖并兼容更灵敏的按键触发
    - 新增设备样式切换事件处理，支持屏幕样式的实时同步与保存
    - 优化 Web 界面事件监听及样式更新逻辑，增强动态交互体验
    - 添加多项相关测试，覆盖按键事件处理与样式同步场景
    [button_controller.py, config.py, main.py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]
2026-07-25 fix: 增强按键交互与配置同步逻辑
    - 添加长按与连发事件支持，优化按键消抖与交互体验
    - 引入通用 `configChange` 事件，支持多键配置动态同步
    - 更新测试覆盖按键处理与配置同步场景
    - 修复远端文件拷贝逻辑，忽略无效文件及多层次测试目录
    - 添加硬件设计数据文件，完善开发资源
    [ST7789_ESP32S3_FPC_V4-2026-7-25.3mf, ST7789_ESP32S3_FPC_V4.3mf]
2026-07-27 fix: 添加按键命令分派与消抖测试支持
    - 新增按键命令模式和事件分派器实现，支持样式切换、亮度调节等命令
    - 实现 GPIO 按键测试与零消抖、长按连发事件验证
    - 增强测试覆盖，验证按键事件处理及模式循环行为
2026-07-27 fix: 重构 Web 界面逻辑，拆分 pywebview 生命周期及增强导航能力
    - 新增 `ui-web-api` 模块，拆分 Web 界面相关逻辑，提升代码可维护性
    - 实现统一的 pywebview 生命周期管理与界面导航支持
    - 优化窗口图标格式转换及跨模块重用能力
    - 更新 README，描述模块职责及结构
    [config.py]
2026-07-27 fix: 添加设备 UUID 支持并优化 WebView2 启动逻辑
    - 新增设备 UUID 支持，优化硬件信息采集及显示
    - 增强 WebView2 启动前环境校验，新增安装下载支持
    - 修复 Windows 托盘退出时的窗口销毁与图标清理问题
    - 更新亮度调节命令逻辑，支持释放时同步最终值
    - 新增待机页面 Wi-Fi 状态验证及设备 UUID 测试
    [button_controller.py, device_identity.py, main.py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]
2026-07-27 fix: 重构自定义数据逻辑，拆分生命周期管理并优化调度处理
    - 新增 `CustomDataServiceMixin`，封装自定义数据初始化、调度及资源释放
    - 移除旧版自定义数据管理代码，改用独立 Mixin 提升代码复用性
    - 优化运行时调度逻辑，对接新接口以增强任务动态调整能力
    - 更新相关函数实现，统一使用 Mixin 方法简化任务定义和采集流程
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2026-07-27 fix: 验证样式存在时抛出异常修复及同步逻辑优化
    - 添加 `style_exists` 方法，在样式不存在时抛出异常，提高样式切换稳定性
    - 优化 `style.delete` 命令，移除重启逻辑并返回样式目录更新结果
    - 更新样式清单返回字段，包含当前激活样式信息
    - 增强 Web 界面及后台样式管理逻辑，支持目录动态同步与操作反馈
    - 添加多项测试，验证异常处理、样式切换及清单同步
    [dashboard.py, main.py, pico_commands.py]
2026-07-29 fix: 重构自定义数据逻辑，拆分模块职责并优化兼容性
    - 调整 `custom_data.py`，拆分支持、调度和生命周期管理模块
    - 移除冗余实现，优化现有调用方的功能兼容性
    - 引入 `custom_data_support` 和其他模块，简化代码复用
    - 提升模块间隔离性，增强维护性和扩展性
    [custom_data.py]
2026-07-29 fix: 重构并新增自定义数据管理功能，支持插件启用状态及动作处理
    - 移除旧版 `custom_data.py` 和 `custom_data_runner.py`，改用新模块拆分职责
    - 新增插件协议 2 支持，包括动作按钮与卸载钩子逻辑
    - 引入 `runtime.py` 和 `support.py` 模块，优化插件隔离运行与调度
    - 更新配置解析及参数注入，支持插件启用状态 JSON 持久化
    - 增强 Web 界面动态交互，新增插件启用切换和动作执行功能
    - 添加详细文档说明 `custom_data_plugin_protocol_v2.md`
    [config.py]
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2026-07-30 fix: 增强插件管理与版本支持，优化通信及显示逻辑
    - 为 MarketPage 添加插件版本管理逻辑，支持安装插件后立即刷新 iframe 状态
    - 更新插件模板支持显式声明版本号，并增加版本格式校验
    - Web 界面自定义数据模块新增版本号显示及样式调整
    - 修复插件通信逻辑，确保版本信息准确传递
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2026-07-30 fix/feat: 优化 MarketPage 功能，增强插件管理与通信逻辑
    - 添加 `inventoryReady` 状态，确保插件数据加载完成后再初始化 iframe
    - 重构插件通信逻辑，注入已安装插件快照，提升数据传递安全性
    - 调整 iframe 加载逻辑，支持插件列表动态刷新和加载状态展示
    - 引入 `reconnecting-websocket` 依赖，增强通信稳定性
    - 优化 UI 展示，新增加载中提示和市场地址校验逻辑
    - 更新插件安装流程，支持安装完成后动态刷新插件列表
2026-07-30 fix/feat: 优化样式清单查询逻辑，支持去重与全量样式同步
    - 扩展样式清单查询功能，支持返回全部设备样式并按名称去重
    - 更新 `style.list` 命令逻辑，替换自定义样式扫描为全量样式扫描
    - 增强异常处理能力，避免样式数据格式无效时导致中断
    - 引入 `reconnecting-websocket` 依赖，优化通信稳定性
    - 更新测试用例，覆盖全量样式查询、去重逻辑与渲染器激活样式验证
2026-07-30 fix/feat: 增强样式上传完成逻辑，支持渲染器动态样式重载
    - 修改 `_finish` 方法，新增上下文支持以获取渲染器实例
    - 在样式正确加载后，动态重载与当前样式匹配的渲染器
    - 更新返回数据结构，包含样式是否成功重载的标识
    - 优化异常处理，确保样式验证失败时恢复备份
    - 添加新增逻辑的测试与验证
2026-07-30 fix/feat: 更新样式文件大小限制为 32KB 并添加新外壳模型
    - 提高 `upload_style.py` 和 `style_validator.py` 样式文件大小上限至 32KB，兼容复杂模板扩展
    - 增加全新 ESP32-S3 外壳模型文件：支持双 Type-C 接口，改进卡扣设计，优化屏幕压板结构
    - 新增多项校验，确保模型装配与设计参数严格一致
    - 详细优化屏幕与结构兼容性，提升打印与安装稳定性
    [ST7789_ESP32S3_外壳_V11_横压板平底.scad]
2026-07-30 fix/feat: 新增样式强制重载功能并扩展渲染服务支持
    - 添加 `reload_style` 方法，支持强制重载覆盖上传后的当前样式
    - 扩展渲染服务，新增 `reload_style` 操作逻辑及相关控制方法
    - 优化内部样式实例释放与重建流程，提高样式动态切换的稳定性
    [dashboard.py, render_service.py]
2026-07-31 fix/feat: 添加性能日志输出及新增错误页面功能
    - 在配置中添加 `STYLE_FRAME_WARNING_MS` 参数用于性能警告日志
    - 增强渲染器性能监测逻辑，输出样式计算延迟的警告消息
    - 新增 `show_application_error` 方法，用于切换至错误页面并显示异常信息
    - 调整主程序异常处理逻辑，支持调用错误页面并保证日志输出
    - 引入全新电路设计文件 `FPC10_PWM_20x30_V11.kicad_pcb`
    [FPC10_PWM_20x30_V11.kicad_pcb]
2026-07-31 fix/feat: 合并同轮询内 JSON 快照并新增快照合并逻辑
    - 优化 `_parse_lines` 方法，支持在同次轮询中合并多个 JSON 分片为完整快照
    - 添加 `_merge_parsed_snapshots` 辅助方法，用于递归合并 JSON 快照，确保分片数据完整性
    - 更新测试用例，验证 JSON 合并逻辑与完整快照生成
    [protocol.py]
2026-07-31 fix/feat: 添加设备注册与状态检查功能
    - 新增设备 UUID 复制功能，支持快速将设备 UUID 复制至剪贴板
    - 引入设备注册逻辑，支持粘贴 Base64 注册码并进行注册操作
    - 实现设备注册状态查询，支持实时同步设备注册信息
    - 更新界面显示，增加已注册状态提示和操作按钮
    - 扩展后端接口，支持注册状态查询与设备注册功能
    - 优化错误处理逻辑，提升注册服务交互的可靠性
2026-07-31 fix/feat: 引入操作系统采集策略注册与解析机制
    - 新增操作系统采集策略接口，定义 CPU 频率、温度等通用能力
    - 实现 Linux、Windows、QNAP、Synology 和 TrueNAS 的专用采集策略
    - 添加支持按优先级选择适用策略并动态解析当前系统策略
    - 为采集任务整合策略支持，优化平台适配与扩展能力
    - 补充测试用例，验证多系统环境的策略解析、注册与采集功能
2026-07-31 fix/feat: 支持群晖、QNAP 和 TrueNAS 安装，新增 NAS 发布包与安装脚本扩展
    - 更新安装脚本，支持群晖、QNAP 和 TrueNAS SCALE 的安装适配
    - 新增 NAS 发布包，覆盖 Synology DSM、QNAP QTS/QuTS 和 TrueNAS SCALE
    - 添加自定义数据 `custom_data` 和网络支持模块 `net`
    - 扩展 DEB 与通用脚本安装清单，包含 NAS 策略与数据模块
    - 优化测试用例，验证安装清单、NAS 发布包及策略目录完整性
2026-07-31 fix/feat: 添加 Web 界面构建步骤至 Linux DEB 打包流程
    - 新增构建 Web 界面任务，验证构建产物 `win/ui-web/dist/index.html` 的存在性
    - 更新打包工作流配置，保证 Web 界面在发布前完成构建
2026-07-31 fix/feat: 新增 NAS 安装说明与发布包生成脚本
    - 添加群晖、QNAP 和 TrueNAS 的 OmniWatch 安装说明文档 `NAS_INSTALL.md`
    - 开发 NAS 发布包构建脚本 `package_nas_release.py`，支持多平台适配
    - 定义支持范围、版本清单与发布包格式，优化跨平台部署体验
2026-07-31 fix/feat: 修复单元测试问题并优化 Windows x86 构建依赖
    - 修复 `test_windows_tray.py` 单元测试，mock `_set_tk_window_icon` 方法以提高测试稳定性
    - 优化 Windows x86 安装依赖，锁定 `cryptography` 至 46.0.7 版本，解决 x86 架构兼容性问题
    - 更新 `build-windows-exe.yml` 工作流配置，提高打包过程的可靠性
2026-07-31 fix: 删除 `test_windows_tray.py` 单元测试文件，移除废弃的 Windows 托盘配置测试
    [ST7789_ESP32S3_外壳_V11_横压板平底.3mf]
2026-07-31 fix: 替换测试中硬编码的 API 版本为常量，提高代码可维护性
2026-07-31 fix: 统一 ESP32-S3 屏幕使用 40 MHz SPI 并更新相关测试
2026-07-31 fix/feat: 修复 ESP32-S3 测试问题并优化 runtime reconnect 逻辑
    - 修复 ESP32-S3 测试中 `serial.write_calls` 和 `sleep.call_count` 的计数错误
    - 更新测试用例，调整握手与设备写入逻辑的计数验证
    - 优化 `MonitorService` runtime reconnect 实现，添加 `runtime_reconnect_requested` 标志与操作接口
    - 替换 `service.stopping.wait` 为 `_wait_for_runtime_interrupt`，改善中断处理逻辑
    - 补充必要的 mock 对象与信号处理器，完善开发模式下的功能覆盖
2026-07-31 fix: 修复 Windows Runner 路径解析问题，避免短路径与长路径混淆
2026-07-31 fix: 修复测试中跨平台模拟 `os.uname` 的问题，避免 MicroPython 环境下的测试失败
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2026-07-31 fix/feat: 修复插件安装逻辑，完善市场样式支持与自定义验证
    - 优化 Market 插件安装流程，新增样式资源类型区分并动态调整消息提示
    - 补充 plugin.json 类型验证，限制自定义数据类型为插件类型 (type=plugin)
    - 添加屏幕盖板设计文件 V12 修正日志，改进 3D 打印适配与装配方案
    [OmniWatch_2.4_ST7789_ESP32S3_V12_屏幕盖板平底.scad]
2026-07-31 fix: 重构 USB 测试用例的轮询逻辑，封装 `_patch_select_poll` 方法以增强复用性
2026-07-31 fix/feat: 添加 Windows 开机自动启动任务迁移测试并优化托盘初始化逻辑
    - 添加 `test_windows_autostart.py` 单元测试，覆盖开机自动启动任务创建与旧配置迁移流程
    - 在托盘初始化过程中调用 `_migrate_legacy_autostart`，记录迁移失败日志以便用户排查
    - 重构 `win/autostart.py`，添加任务计划检查与删除方法，优化任务创建错误处理
2026-08-03 fix/feat: 添加网络历史最大值计算逻辑并优化图表显示
    - 增加上传与下载历史记录的实时最大值计算，统一 `_network_history_maximum` 方法
    - 更新 `_history` 与 `_gradient_history` 接口，支持指定最大值参数以提升显示精度
    - 优化网络历史图表绘制，改善折线图与面积图的比例动态调整
    - 修复网络历史变更的选择判定逻辑，添加 `network_history_changed` 检测
2026-08-03 fix/feat: 添加磁盘历史最大值计算逻辑并优化图表显示
    - 增加读取与写入历史记录的实时最大值计算方法 `_disk_history_maximum`
    - 更新 `_history` 与 `_gradient_history` 接口，支持最大值参数以提高显示精度
    - 优化磁盘历史图表绘制逻辑，动态调整比例改善视觉效果
2026-08-03 fix/feat: 添加 LED MOSFET PWM 小板 V4 设计文件并支持嘉立创免费打样
    - 添加 KiCad 工程文件和 Gerber 文件，兼容嘉立创免费打样流程
    - 包含手焊设计，支持 0805 电阻与 SOT-23 MOSFET 器件
    - 更新板厚、阻焊层、字符层与拼版设置，验证 JLC 客编位置
    - 提供 README 文档，详细说明拼接设计、导入与发货流程
    [BOM.csv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]
2026-08-04 fix/feat: 添加外壳设计文件 V13，修正屏幕卡钩与凹槽定位问题
    - 添加 3D 打印外壳设计文件 V13，修正屏幕卡钩根部侵入凹槽问题
    - 卡钩跟随新凹槽外移 1.00mm，根部与凹槽边缘保留 0.30mm 净距
    - 优化盖板与凹槽的装配方案，增加打印误差保护，改善装配适配性
    [LCD_ESP32S3_外壳_V13_卡钩移出凹槽.3mf, LCD_ESP32S3_外壳_V13_卡钩移出凹槽.scad]
2026-08-04 fix/feat: 更新安装脚本支持管理员令牌启动 Monitor，完善权限提升测试
    - 调整 `pico_monitor_setup.iss`，添加 `runascurrentuser` 标志确保安装完成后以管理员权限运行 Monitor
    - 添加单元测试 `test_inno_setup_launches_monitor_with_installer_admin_token`，验证脚本配置和权限提升逻辑
2026-08-04 fix/feat: 更新默认市场地址与窗口启动逻辑，补充测试用例
    - 修改默认市场地址为 https://omni.mzlblog.com 并更新相关配置初始化逻辑
    - 调整 WebView 窗口加载方式，优化启动隐藏与恢复顺序避免覆盖用户操作
    - 修复磁盘 IO 历史缓存字段不完整的问题，确保采集数据一致性
    - 新增测试用例验证默认配置值、窗口状态恢复逻辑与磁盘历史补全
2026-08-05 fix update
    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
    [pico_monitor.py]
2026-08-06 fix:代码暂存，修复部分问题
    [LCD_ESP32S3_外壳_V16_TypeC开口向后盖移1mm.3mf, LCD_ESP32S3_外壳_V16_TypeC开口向后盖移1mm.scad]
2026-08-07 fix 10pin LCD 小板Q1 SN级反转问题
    [BOM_JLCPCB.csv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]
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2026-08-08 fix/feat: 重构固件更新逻辑支持串口、ZIP 包和全量覆盖模式
    - 重命名并优化 Pico 固件打包脚本，支持生成全量固件包
    - 更新前端设备页面 UI，新增串口选择、全量/增量更新模式切换
    - 引入 `CopyableLog` 组件，统一日志视图并支持快速复制完整内容
    - 补充全量更新相关后端接口和本地校验逻辑
    - 更新测试用例覆盖窗口前端到后端的全量更新流程验证
    [config.py, pico_upgrade.py]
2026-08-08 fix/feat: 更新文件校验逻辑，优化默认路径与上传行为
    - 修改默认路径为 `E:\WorkSpace\fn-vision\pico-project\esp32-s3`
    - 优化文件传输逻辑，调整本地文件指纹生成方式，支持强制模式跳过 SHA-256 校验
    - 增加上传原因提示（设备端文件不存在或大小/SHA-256 不一致）
2026-08-08 fix/feat: 增加 Wi-Fi 设备主动发现功能，优化网段扫描逻辑
    - 引入 UDP 主动公告监听支持，默认采用公告优先且网段扫描兜底策略
    - 更新 ESP32 固件以支持 Wi-Fi 主动公告配置及发播逻辑
    - 修改设置页面，新增 Wi-Fi 发现策略配置项（公告/扫描）
    - 修复公告监听与网段扫描相关的多个测试用例并补充覆盖率
    - 优化告警及连接日志，新增候选设备来源标识
    [config.py, main.py]
2026-08-08 fix/feat: 优化 Wi-Fi 设备发现与固件打包流程
    - 增强 Wi-Fi 设备候选验证日志，标注设备来源及连接状态
    - 引入 UDP 主动公告重复检测逻辑，避免冗余候选设备处理
    - 更新固件打包脚本，默认切换至 ESP32-S3 作为目标板
    - 修改发布包测试逻辑，匹配新屏幕尺寸与本地源文件完整性
    - 删除无效目标板配置，精简构建流程
2026-08-08 fix/feat: 优化固件打包流程并增强开发板型号检测逻辑
    - 更新打包脚本，增加文件夹排除规则支持（tests, __pycache__）
    - 优化开发板型号解析逻辑，兼容无旧板型注册表的独立 ESP32-S3 工程
    - 增强兼容性，支持从 config.py 自动解析板型配置
2026-09-01 fix/feat: 增加硬件监控字段解析策略及测试用例支持
    - 新增 LibreHardwareMonitor 字段解析策略适配器和子策略模块（CPU、GPU、内存、磁盘、功耗）
    - 重构 SensorHost 快照解析逻辑，替换手工解析为策略链实现
    - 增强日志输出：添加 SensorHost 快照结果率限及开发模式即时输出支持
    - 更新 sensor_host 和相关任务的测试用例，验证字段解析策略及日志行为
2026-09-01 fix: 添加致谢信息，感谢@Tz.协助修复 intel 平台 CPU 温度获取失败问题
2026-09-02 fix/feat: 新增 PawnIO 支持并优化安装流程
    - 更新构建脚本，增加 PawnIO 安装包嵌入支持
    - 扩展 SensorHost 文档，补充 PawnIO 驱动安装及内存快照字段说明
    - 添加 split.bat 和 OpenSCAD 脚本，支持 3D 模型独立导出
    - 引入 PawnIO 第三方依赖及其 LICENSE 文件
    [01_front_shell.3mf, 02_back_cover.3mf, 03_04_screen_esp32_breakaway.3mf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]
2026-09-02 fix/feat: 添加独立 SensorHost 打包支持并优化构建脚本
    - 更新构建脚本，新增 SensorHost 独立安装路径配置
    - 修改打包流程，避免 SensorHost 解包至临时目录运行
    - 补充相关测试用例验证 SensorHost 安装行为
2026-09-02 fix/feat: 添加 SensorHost LFS 文件校验并优化构建流程
    - 更新 CI 构建脚本，支持拉取并校验 SensorHost LFS 实际文件
    - 增加构建前校验 SensorHost x64 PE 文件头的验证脚本
    - 修改本地构建脚本调用校验逻辑，确保文件完整性
    - 补充相关测试用例，验证 LFS 文件校验及打包流程完整性
2026-09-02 fix/feat: 启用 Linux HTTP 管理页面，新增配网及服务配置文档
    - 默认开启 Linux HTTP 管理页面功能，调整初始 Auth 配置为公开值
    - 更新 Debian 配置文件以匹配 HTTP 服务默认启用和初始密钥设置
    - 新增 `linux_install.md` 文档，提供常见 Linux 发行版一键安装指南
    - 新增 `http-manager-linux.md`，说明 Linux HTTP 管理页面功能与安全配置
    - 添加 `linux-wifi-config.md`，详述命令行设备配网操作与问题排查
    - 补充 Windows HTTP 管理页面配置更新说明，建议用户替换初始 Auth
2026-09-08 fix/feat: 优化 ESP32-S3 工具并新增量产界面支持
    - 更新 `historyIncrease.py`：添加股票 K 线历史判定，优化通用历史序列逻辑
    - 引入量产 GUI 工具：实现 SDK 刷写、代码同步及设备校验的自动化处理
    - 新增 `start_production.cmd` 启动脚本，便捷启动量产界面
    - 添加 `production_requirements.txt`，定义量产工具依赖
    - 新增测试用例：覆盖股票 K 线历史处理及文件传输时间设置功能
    - 补充 `量产工具说明.md` 文档，详述量产流程及操作指南
    [外壳_V16_2026-8.3mf]
2026-09-09 fix/feat: 添加 ZLABS 12px 字体支持及相关功能优化
    - 增加 ZLABS_PIXEL_12PX 字体支持，更新点阵字体管理逻辑
    - 提高兼容性：升级 Canvas C API 到版本 10，确保新字体正常使用
    - 支持通过 Web 浏览器上传 SDK 镜像、固件包和样式文件
    - 新增 HTTP 页面插件市场地址配置，优化插件安装路径校验
    - 更新测试用例，覆盖字体使用检测、新文件上传及插件功能校验
    - 添加 ZLABS 字体生成与测试脚本，内嵌生成字形点阵及测试样式
    [canvas.py, canvasC.py, config.py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]
2026-09-10 fix/feat: 优化 JSON 快照事务与 WebSocket 超时处理
    - 添加事务性快照分片支持，限制基线更新需设备 ACK
    - 实现 WebSocket PV1 行与缓冲区大小上限保护
    - 更新 CDC 写入与超时逻辑，优化连接容错性和背压处理
    - 增加开发者计划选项，支持预览版更新相关功能
    - 优化事务写入测试用例与合并语义确保状态一致性
    [data_receiver.py, pico_ack.py, pico_client.py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]
2026-09-11 fix/feat: 添加 Linux DEB 配置完整文档
    - 编写详细的 Pico Monitor Linux DEB 配置说明文档
    - 涵盖配置文件位置、优先级、示例和 YAML 解析规则
    - 补充串口、网络、监控任务、HTTP 页面等模块详细配置
    - 提供常见使用场景配置及排查步骤
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2026-09-11 fix: 同步初始化 JSON 快照事务状态
2026-09-11 fix/feat: 优化测试清理逻辑，新增多场景测试用例
    - 改进测试清理：替换 `tearDown` 为 `addCleanup`，优化临时目录与服务清理逻辑
    - 重构 WebSocket 测试代码：改用上下文管理器提升可读性
    - 增加 HTTP 伪造上传编号测试用例，覆盖桌面动作拦截场景
    - 补充浏览器上传测试：支持保留 multipart 文件名分隔符
    - 更新 Windows 打包流程：增加 Python UTF-8 输出环境变量配置
2026-09-11 fix: 测试用例优化，添加 ZLABS 字体点阵路径校验
    - 更新测试逻辑：新增条件检查确保字体点阵资源存在
    - 修复路径定义：统一 `ZLABS_BITMAP_SOURCE` 数据来源
    - 保持原字体像素一致性，调整 Bitmap 校验流程
2026-09-11 fix/feat: 取消 400ms 限制，优化 CDC 快照事务与 Linux/Windows 更新进度
    - 移除整批 CDC 快照事务的 400ms 超时限制，支持分片传输进度推进
    - 优化 USB CDC 请求写入逻辑，增强设备冷启动和慢速传输兼容性
    - 增加 CDC 连接稳定性测试用例，覆盖慢构帧与长时间背压场景
    - 改进 Linux DEB 和 Windows 安装包下载逻辑，支持实时字节进度回调展示
    - 添加 Linux HTTP 页进度同步功能及 APT 更新阶段日志
    - 更新相关单元测试，校验 HTTP 更新回调进度与用户界面响应
    [monitor_update.py, pico_client.py]
2026-09-12 fix/feat: 增加 JSONB 快照支持，优化 PV1 帧与串口写入逻辑
    - 新增 JSONB 二进制分片支持，提高大快照传输效率，移除旧版事务降级兼容
    - 更新 PV1 帧格式和设备响应，调整分片下行协议，添加 JSONB 头部解析及 err 状态处理
    - 改进串口写入逻辑，优化 Windows/ESP32-S3 背压卡顿及超长 flush 超时问题
    - 增强垃圾回收与协议解析协调逻辑，有效避免低空闲内存导致解析阻塞
    - 全面更新测试用例，覆盖 JSONB 高效传输与 ACK 回调验证
    - 调整用户配置选项，增加 JSON 分片大小参数校验
    [config.py, main.py, pico_client.py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]
2026-09-12 fix/feat: 添加待机样式开关及 CDC 完整帧优化
    - 增加待机功能开关 `idle_enabled`，支持配置禁用待机样式
    - 优化 CDC 完整帧队列与异步错误处理，确保快速回收合并帧
    - 改进 JSONB 分片逻辑，更新设备为支持完整帧的优先队列传输
    - 增强固件 FreeRTOS 任务协调，提升 USB 数据传输稳定性
    - 调整 Linux/Windows 下显示配置同步与测试用例覆盖范围
    [config.py, main.py, pico_ack.py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]
2026-09-12 fix/feat: 增加 WebSocket 原生数据面支持及超时逻辑优化
    - 添加 `_native_websocket` 接口支持，启用 C 层原生 WebSocket 数据面优化接管
    - 增强原生模式超时、错误同步与活动检测，支持多功能方法调用
    - 优化 Python/原生模式切换及资源释放逻辑，提升数据传输稳定性
2026-09-13 fix/feat: 添加按键事件监听支持，优化设备默认命令逻辑
    - 增加 `on_button_event` 方法，允许主题自定义消费物理按键事件
    - 优化按键事件透传逻辑，未被主题消费时执行默认设备动作
    - 扩展测试覆盖：验证按键监听及状态切换的正确性
    - 更新断言与快照，确保样式更新与按键状态一致
    - 调整资源打包：新增关于页二维码资源绑定
    [dashboard.py, main.py, render_service.py]
2026-09-13 fix/feat: 添加 Linux 桥接调用单元测试，优化设备状态与首屏载荷逻辑
    - 增加 `LinuxInvokeBridgeTest` 测试类，验证设备状态与首屏调用逻辑支持空载荷
    - 修改 `_device_status` 和 `_bootstrap` 接口，接收并忽略载荷参数
    - 扩展测试覆盖范围，确保调用一致性与返回结果正确性
2026-09-13 fix/feat: 重构样式和 Wi-Fi 逻辑，提取跨平台通用数据处理模块
    - 提取公共功能至 `ui_helpers`，减小重复代码和平台耦合
    - 优化样式包处理逻辑：支持跨平台解压、持久化和资源加载
    - 更新 Wi-Fi 合并和状态文本方法，实现模块化共享
    - 增加跨平台测试用例：覆盖 `ui_helpers` 核心功能
    - 移除重复实现，提升代码维护性和执行效率
2026-09-29 fix/feat: 增加 SDK 自定义选择和全量 ZIP 支持，优化量产工具交互
    - 支持手动选择 ESP32-S3 SDK 镜像及恢复自动选择最新版本
    - 新增全量 ZIP 包解压校验与临时目录逻辑，统一处理源码与 ZIP 来源
    - 更新 GUI：新增 SDK 配置界面及 ZIP/源码目录切换选项
    - 优化插拔设备流程状态提示，增强错误日志与进度显示
    - 更新使用文档，说明 SDK 自定义和 ZIP 解压校验要求
    - 添加测试：覆盖 ZIP 校验、解压与全量流程
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2026-10-10 fix/feat: 优化 USB CDC 数据传输逻辑，增强握手与错误诊断支持
    - 添加 `UsbCdcFrameReader`，支持完整帧保存和跨超时读取
    - 增加 USB 传输诊断器，记录帧超时与写入延迟数据
    - 优化握手逻辑，避免重复发送 PING 且提升响应超时处理
    - 增强多块写入事务支持，确保固定设备配置期间数据完整性
    - 扩展测试覆盖范围，验证复杂场景下 USB CDC 行为稳定性
    - 更新协议帧错误处理，保留完整帧避免丢失请求逻辑
2026-10-10 fix/feat: 添加 USB 诊断功能及通信超时逻辑优化
    - 增加 `usb_transfer_diagnostics.py`，完善 USB CDC 传输监控及慢写分析
    - 添加监控超时后返回等待页的逻辑，优化快照有效性和待机样式开关
    - 更新 USB 和 ESP32-S3 上传逻辑，确保超时与重新连接处理一致
    - 扩展测试覆盖：验证 USB 诊断、通信超时及快照恢复组态
2026-10-10 fix/feat: 修复 USB 写入吞吐统计精度问题，增强时钟不足场景兼容性
    - 修复快速内存写入在 Windows 上可能导致吞吐统计为 0 的问题，添加递增时钟模拟逻辑
    - 新增测试覆盖：验证同一时钟刻度内 USB 写入吞吐统计跳过逻辑及配置稳定性
2026-10-10 fix/feat: 支持窗口会话结束处理，优化关机与托盘隐藏逻辑
    - 添加系统会话结束处理，覆盖原有隐藏关闭场景
    - 允许关机、重启和注销适配窗口关闭逻辑
    - 优化 pywebview 窗口托盘行为，确保系统事件优先传递
    - 增加单元测试：验证会话结束、关机和托盘交互流程
2026-10-11 修复 macOS 桌面、插件运行时与 USB 兼容并修正双架构打包工作流
2026-10-11 修复 Apple Silicon 无 CPU 频率接口时的跨平台回归用例
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2026-10-11 修复 #1：缺失 mapper 别名时保留 LVM 卷容量并避免 RAID 重复累计
2026-10-11 修复 #2：保留 NVMe 命名空间名称并合并控制器扫描及健康状态
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2026-10-17 修复 5×7 字体小写 g 的降部缺失
    同步修正 ESP32-S3 与 RP2040 字形，增加三个字体变体的像素回归并纳入跨平台持续集成。
    Closes #6
2026-10-17 修复 #3：读取 Linux 未挂载物理盘容量并保留文件系统汇总语义
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2026-10-17 修复 #5：容器重复挂载优先保留 NAS 卷根并避免重复容量查询
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2026-10-23 修复 ST7789 2.4 寸屏背板 GPIO 与屏幕功能映射，并补充反序插接逻辑和测试。
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2026-11-08 修复 Linux DEB 升级配置迁移、缓存刷新和摘要文件名兼容
2026-11-09 修复 macOS 回归测试的字节码环境与 UDP 时钟依赖
